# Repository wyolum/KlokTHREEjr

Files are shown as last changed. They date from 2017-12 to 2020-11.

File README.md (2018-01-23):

# KlokTHREEjr
RGB LED matrix for text and animation display.

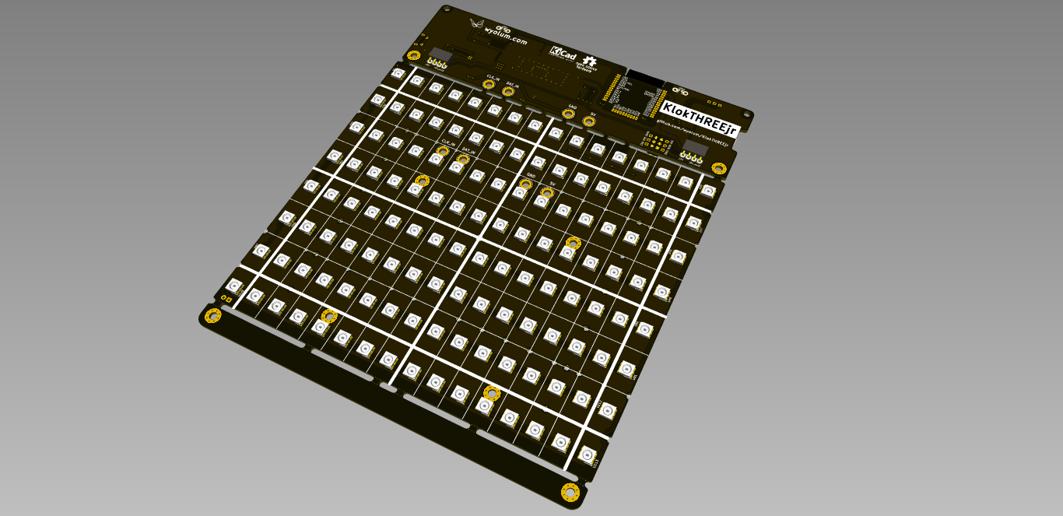
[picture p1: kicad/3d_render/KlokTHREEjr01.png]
KlokTHREEjr


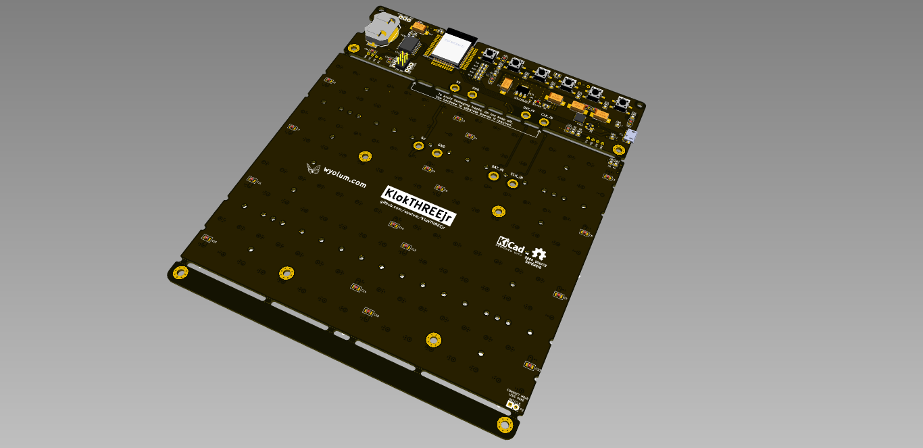
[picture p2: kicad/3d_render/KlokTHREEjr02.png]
KlokTHREEjr


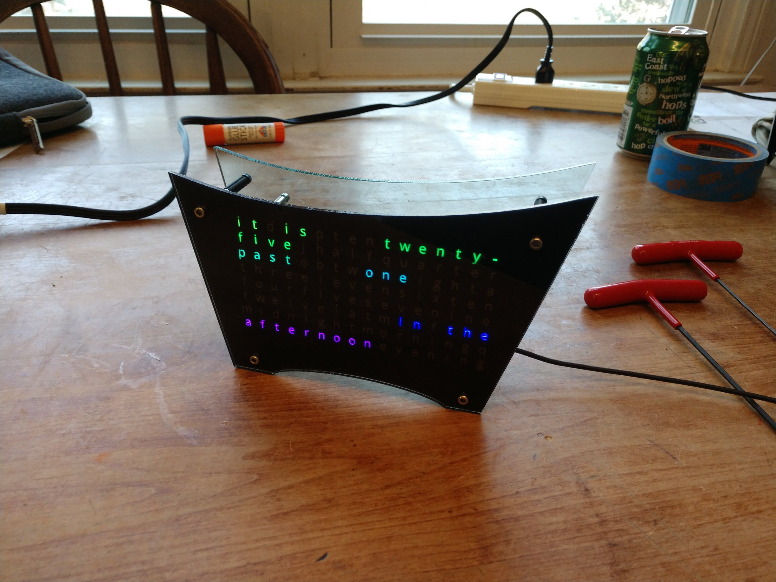
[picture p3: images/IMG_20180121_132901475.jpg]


License
-------
[CERN Open Hardware Licence v1.2 ]

[CERN Open Hardware Licence v1.2 ]:http://www.ohwr.org/attachments/2388/cern_ohl_v_1_2.txt

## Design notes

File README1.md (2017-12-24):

# Chromogram
RGB LED matrix for text and animation display.

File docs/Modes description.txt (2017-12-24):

Power-up
-
Display code version "1.0"
L | R held down <go to Self test>
- or -
wait 1 second then <go to Time mode>

_________________
Self test mode
_________________
Display "Test"
- cycle R, G, B pixels (mostly to check for bad pixels)

L | R - <go to Time mode>

_________________
Time mode
_________________
L - go to Seconds mode
R - Colour++
R held - go to Colour/Group select mode

L & R held - go to Time Set mode

_________________
Seconds mode
_________________
L - go to Temperature mode

_________________
Temperature mode
_________________
L - go to Time mode
L held - toggle between deg F and deg C

_________________
Colour/Group select mode
_________________
R - colour ++
R held - group ++
no button for 1 sec - go to Time mode

Display <Group><Colour/Speed>, e.g. "A0" for White, "A2" for Red, "B1" for solid colour fade w/ 500ms delay
(Remember last colour/speed shown when switching groups)

Group A - Solid colours
	0-White
	1-Pink
	2-Red
	3-Orange
	4-Yellow
	5-Green
	6-Blue
	7-Purple
	<repeat>

Group B - Solid colours
	0-White
	1-Hot pink
	2-Blood orange
	3-Lemon lime
	4-Neon green
	5-Teal
	6-Turquois
	7-Light purple
	<repeat>

Group C - Solid colour fade
	Speed 1 - delay 500
	Speed 2 - delay 200
	Speed 3 - delay 100
	Speed 4 - delay 50
	Speed 5 - delay 10
	<repeat>

Group D	- Rainbow colour fade
	Speed 1 - delay 500
	Speed 2 - delay 200
	Speed 3 - delay 100
	Speed 4 - delay 50
	Speed 5 - delay 10
	<repeat>

Group E - Randomly coloured letters
	Speed 0 - colours only change when words change
	Speed 1 - colours change once per minute
	Speed 2 - colours change every 15 seconds
	Speed 3 - colours change every 5 seconds
	Speed 4 - colours change every second
	Speed 5 - delay 100ms
	Speed 6 - delay 10ms
	<repeat>

Group F	- Simulated fire

<back to Group A>

_________________
Time set mode
_________________
L - enter
R - selection ++

Display "Set"
Display "Hour"
Display current hour from RTC
R - Hour ++ (0 - 23, repeating)
<hour is selected>
L - 
Display "Min"
Display current minute from RTC
R - Minute ++ (0-59, repeating)
L - 
Display "OK" for 1 second
<Return to Time mode>

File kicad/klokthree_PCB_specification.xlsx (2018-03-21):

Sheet: Template
PCB Name 名称 | KlokTHREEjr
Board Size 尺寸 | Length*width (Unit:inch) | 6.4 | * | 7.65
Material 板材 | (Rigid) FR－4 | Special Requirement:
Layers 层数 | 2 | Special Requirement:
Thickness 厚度 | 1.6 mm | Special Requirement:
Copper Weight 铜厚 | 1 oz. | Special Requirement:
Soldermask Color 阻焊颜色 | BLACK | Special Requirement:
Silkscreen Color 丝印颜色 | WHITE | Special Requirement:
Surface Finishing 焊盘喷镀 | HASL Lead Free | Special Requirement:
Via soldermask 阻焊覆盖 | Soldermask Cover | Special Requirement:
Mini trace/spacing 最小线宽 | 0.20 mm | Special Requirement:
Mini hole size 最小孔径 | 0.40 mm | Special Requirement:
Special requirements 特殊工艺
 | Other Special requirements：

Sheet: Parameter
PCB Material | Layers | Thickness | Copper Weight | Soldermask Color | Silkscreen Color | Surface Finishing | Via soldermask | Mini trace/spacing | Mini hole size
FR-4 | 1 Layer | 0.6mm | 0.5 oz | Green | White | HASL Lead Free(RoHS) | Soldermask Cover | 4 mil or 0.10 mm | 6 mil or 0.15 mm
Flexible Printed Circuit | 2 Layer | 0.8mm | 1 oz | Red | Black | ENIG | Soldermask Opening | 5 mil or0.13 mm | 8 mil or 0.2 mm
Rogers 4003 | 4 Layer | 1.0mm | 2 oz | Blue | Yellow | OSP |  | 6 mil or 0.15 mm | 10 mil or 0.25 mm
Rogers 4350 | 6 Layer | 1.2mm | 3 oz | Black | Red | Immersion Tin |  | 8 mil or 0.20 mm | 12 mil or 0.30 mm
Taconic Series | 8 Layer | 1.3mm | Other | White | Other | Immersion Sliver
Aluminum-based material | 10 Layer | 1.6mm |  | Green Matte |  | Hard Gold
RF-35 | 12 Layer | 2.0mm |  | Blue Matte |  | Other
Arlon | 14 Layer | 2.5mm |  | Black Matte
Other | 16 Layer | 3.0mm |  | Other
 | Other | Other

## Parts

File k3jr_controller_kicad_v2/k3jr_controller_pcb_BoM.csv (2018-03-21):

Id | Designator | Package | Quantity | Designation | Supplier and ref
1 | BT1 | CR2032_SMD2 | 1 | Batt_RTC
2 | LDR1,LDR2 | r_0805_ldr_2 | 2 | LDR
3 | S5 | SW_SMD | 1 | SW-DEC
4 | C17,C25,C23 | c_2917 | 3 | 10uF/25V
5 | D1 | SOT-143 | 1 | RClamp0854P.TCT
6 | P1 | USB_Micro-B_Molex-105017-0001 | 1 | USB_micro
7 | HB47,HB48 | MountingHole_3.2mm_M3_Pad_Via | 2 | mtg_hole_3mm
8 | S6 | SW_SMD | 1 | SW-MODE
9 | C27 | c_2917 | 1 | 100uF/6V3
10 | U132 | QFN-28-1EP_5x5mm_Pitch0.5mm | 1 | CP2102N-A01-GQFN28
11 | R25,R24,R11,R10,R3,R7,R6,R12,R13 | r_0805 | 9 | 10k
12 | C31,C22,C26,C24,C29,C30 | c_0805 | 6 | 100nF
13 | S4 | SW_SMD | 1 | SW-BOOT
14 | HB45,HB46 | MountingHole_3.2mm_M3 | 2 | mtg_hole_3mm_small
15 | G1,G7 | Logo-WL3 | 2 | LOGO_WL
16 | C18 | c_2917 | 1 | 22uF/25V
17 | R9,R8 | r_0805 | 2 | 4K7
18 | U131 | SOT-223-3_TabPin2 | 1 | 1117-33
19 | R23,R21 | r_0805 | 2 | 0R
20 | R22,R18,R16 | r_0805 | 3 | 470R
21 | R20,R19 | r_0805 | 2 | 0R NC
22 | R4 | r_0805 | 1 | 1k
23 | Q1 | SOT-363_SC-70-6 | 1 | DDC114TU
24 | C28 | c_0805 | 1 | 1uF/10V
25 | C21,C20,C19 | c_0805 | 3 | 1nF
26 | TP1 | BreakOutPad | 1 | ~RST
27 | S2 | SW_SMD | 1 | SW-INC
28 | U130 | DS3231 | 1 | DS3231N
29 | S3 | SW_SMD | 1 | SW-EN
30 | J8 | 1pin | 1 | GND
31 | J7 | 1pin | 1 | 5V
32 | J23 | BreakOutPad | 1 | GND
33 | J22 | BreakOutPad | 1 | RST
34 | J21 | BreakOutPad | 1 | MOSI
35 | J20 | Header_ISP | 1 | SPI
36 | J19 | BreakOutPad | 1 | SCK
37 | J18 | BreakOutPad | 1 | 3V3
38 | J17 | BreakOutPad | 1 | MISO
39 | TP3 | BreakOutPad | 1 | 32kHz
40 | TP2 | BreakOutPad | 1 | SQR
41 | J25 | Header_4x1 | 1 | I2C_ext2
42 | J24 | Header_4x1 | 1 | I2C_ext1
43 | G3,G9 | OSHW_6mm | 2 | OSHW
44 | G2,G8 | KiCad-Logo2_6mm_SilkScreen | 2 | KiCad
45 | J2 | 1pin | 1 | DAT_IN
46 | J1 | 1pin | 1 | CLK_IN
47 | JP1 | R_0402 | 1 | LED_PWR_EN
48 | U129 | esp_wroom_32 | 1 | ESP-wroom-32
49 | S1 | SW_SMD | 1 | SW-ENTER
50 | D2 | LED-0805 | 1 | LED_PWR
51 | L1,L2 | r_0805 | 2 | 330E

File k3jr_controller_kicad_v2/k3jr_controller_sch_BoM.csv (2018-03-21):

Reference Type | Quantity | Reference | Value | Footprint | Datasheet | manf# | Digikey | Field4 | Field5 | Field6 | Field7 | Field8 | Field9 | Field10 | Field11
BT | 1 | BT1, | Batt_RTC | k3jr_controller_libs:CR2032_SMD2 |  |  | BU2032SM-HD-GCT-ND
C | 3 | C19,C20,C21, | 1nF | k3jr_controller_libs:c_0805 |  | Value
C | 6 | C29,C31,C30,C22,C24,C26, | 100nF | k3jr_controller_libs:c_0805
C | 1 | C27, | 100uF/6V3 | k3jr_controller_libs:c_2917
C | 1 | C28, | 1uF/10V | k3jr_controller_libs:c_0805
C | 3 | C17,C23,C25, | 10uF/25V | k3jr_controller_libs:c_2917
C | 1 | C18, | 22uF/25V | k3jr_controller_libs:c_2917
D | 1 | D2, | LED_PWR | k3jr_controller_libs:LED-0805 |  |  |  | LED SS 5MM 625NM RED DIFF | 2V, 10mA | Round with Domed Top, 5mm, T-1 3/4 | Kingbright Corp | WP7113ID | Digikey | 754-1264-ND | http://www.digikey.com/product-detail/en/WP7113ID/754-1264-ND/1747663
D | 1 | D1, | RClamp0854P.TCT | k3jr_controller_libs:SOT-143
G | 2 | G2,G8, | KiCad | k3jr_controller_libs:KiCad-Logo2_6mm_SilkScreen |  | Value
G | 2 | G1,G7, | LOGO_WL | k3jr_controller_libs:Logo-WL3 |  | Value
G | 2 | G3,G9, | OSHW | k3jr_controller_libs:OSHW_6mm |  | Value
HB | 2 | HB47,HB48, | mtg_hole_3mm | k3jr_controller_libs:MountingHole_3.2mm_M3_Pad_Via |  | Value
HB | 2 | HB45,HB46, | mtg_hole_3mm_small | k3jr_controller_libs:MountingHole_3.2mm_M3 |  | Value
J | 1 | J1, | CLK_IN | k3jr_controller_libs:1pin
J | 1 | J2, | DAT_IN | k3jr_controller_libs:1pin
J | 2 | J23,J8, | GND | k3jr_controller_libs:BreakOutPad |  | mfr_pn
J | 1 | J24, | I2C_ext1 | k3jr_controller_libs:Header_4x1
J | 1 | J25, | I2C_ext2 | k3jr_controller_libs:Header_4x1
J | 1 | J17, | MISO | k3jr_controller_libs:BreakOutPad
J | 1 | J21, | MOSI | k3jr_controller_libs:BreakOutPad |  | mfr_pn
J | 1 | J22, | RST | k3jr_controller_libs:BreakOutPad |  | mfr_pn
J | 1 | J19, | SCK | k3jr_controller_libs:BreakOutPad |  | mfr_pn
J | 1 | J20, | SPI | k3jr_controller_libs:Header_ISP
J | 1 | J7, | 5V | k3jr_controller_libs:1pin
J | 1 | J18, | 3V3 | k3jr_controller_libs:BreakOutPad |  | mfr_pn
JP | 1 | JP1, | LED_PWR_EN | k3jr_controller_libs:R_0402
L | 2 | L1,L2, | 330E | k3jr_controller_libs:r_0805
LDR | 2 | LDR1,LDR2, | LDR | k3jr_controller_libs:r_0805_ldr_2
P | 1 | P1, | USB_micro | k3jr_controller_libs:USB_Micro-B_Molex-105017-0001
Q | 1 | Q1, | DDC114TU | k3jr_controller_libs:SOT-363_SC-70-6 | https://www.diodes.com/assets/Datasheets/ds30345.pdf
R | 2 | R8,R9, | 4K7 | k3jr_controller_libs:r_0805
R | 2 | R21,R23, | 0R | k3jr_controller_libs:r_0805 |  | Value
R | 3 | R22,R16,R18, | 470R | k3jr_controller_libs:r_0805 |  | Value
R | 2 | R20,R19, | 0R NC | k3jr_controller_libs:r_0805 |  | Value
R | 1 | R4, | 1k | k3jr_controller_libs:r_0805
R | 9 | R24,R25,R12,R13,R10,R11,R6,R7,R3, | 10k | k3jr_controller_libs:r_0805
S | 1 | S4, | SW-BOOT | k3jr_controller_libs:SW_SMD |  | Value
S | 1 | S5, | SW-DEC | k3jr_controller_libs:SW_SMD
S | 1 | S3, | SW-EN | k3jr_controller_libs:SW_SMD |  | Value
S | 1 | S1, | SW-ENTER | k3jr_controller_libs:SW_SMD
S | 1 | S2, | SW-INC | k3jr_controller_libs:SW_SMD
S | 1 | S6, | SW-MODE | k3jr_controller_libs:SW_SMD
TP | 1 | TP2, | SQR | k3jr_controller_libs:BreakOutPad
TP | 1 | TP3, | 32kHz | k3jr_controller_libs:BreakOutPad
TP | 1 | TP1, | ~RST | k3jr_controller_libs:BreakOutPad
U | 1 | U131, | 1117-33 | k3jr_controller_libs:SOT-223-3_TabPin2 | http://www.diodes.com/datasheets/AP1117.pdf | mfr_pn
U | 1 | U132, | CP2102N-A01-GQFN28 | k3jr_controller_libs:QFN-28-1EP_5x5mm_Pitch0.5mm | http://www.silabs.com/support%20documents/technicaldocs/cp2102n-datasheet.pdf | Value
U | 1 | U130, | DS3231N | k3jr_controller_libs:DS3231
U | 1 | U129, | ESP-wroom-32 | k3jr_controller_libs:esp_wroom_32 |  | mfr_pn

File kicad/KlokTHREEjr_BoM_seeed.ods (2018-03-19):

Electronic Engineering BOM List
Product Name： KlokTHREEjr
Version：V1
Issue Date：18/MAR/2018
Item No. (序号) | Reference Des (上件位置) | Qty (用量) | Catalog (分类） | Part_Description (规格描述) | Part_Value （元件值） | Part_Package （元件封装） | Manufacturers Name (使用厂牌名称) | Manufacturers Part No. (使用厂牌型号) | Distributors Name （供应商名称） | Distributors Part No. (供貨商型号) | Unit Price （单价） | Price Break To Use （价格分段的购买量） | Notes/Remark （备注）
Example（填写范例）
1 | BT1 | 1 | OTHER | HOLDER COIN CELL 20MM SMD | Batt_RTC | CR2032_SMD | MPD (Memory Protection Devices) | BK-912 | Digikey | BK-912-ND |  |  | https://www.digikey.com/product-detail/en/mpd-memory-protection-devices/BK-912/BK-912-ND/2647825
2 | BATT1 | 1 | OTHER | BATTERY LITHIUM 3V COIN 20MM | Battery Coin 2032 | CR2032 | Panasonic – BSG | CR2032 | Digikey | P189-ND |  |  | https://www.digikey.com/product-detail/en/panasonic-bsg/CR2032/P189-ND/31939
3 | C31,C22,C26,C24,C29,C30,C9,C6,C1,C2,C3,C4,C5,C7,C8,C10,C11,C12,C13,C14,C15,C16 | 22 | Capacitor | CAP CER 0.1UF 50V X7R 0805 | 100nF | c_0805 | KEMET | C0805C104M5RACTU | Digikey | 399-1169-1-ND |  |  | https://www.digikey.com/product-detail/en/kemet/C0805C104M5RACTU/399-1169-1-ND/411444
4 | C17,C23,C25 | 3 | Capacitor | CAP ALUM POLY 10UF 20% 25V SMD | 10uF/25V | c_2917 | Panasonic Electronic Components | EEF-CS1E100R | Digikey | P16804-1-ND |  |  | https://www.digikey.com/product-detail/en/panasonic-electronic-components/EEF-CS1E100R/P16804-1-ND/4755574
5 | C18 | 1 | Capacitor | CAP ALUM POLY 22UF 20% 25V SMD | 22uF/25V | c_2917 | Panasonic Electronic Components | EEF-CX1E220R | Digikey | P16818-1-ND |  |  | https://www.digikey.com/product-detail/en/panasonic-electronic-components/EEF-CX1E220R/P16818-1-ND/4755588
6 | C19,C20,C21 | 3 | Capacitor | CAP CER 1000PF 50V X7R 0603 | 1nF | c_0805 | AVX Corporation | 06035C102KAT2A | Digikey | 478-1215-1-ND |  |  | https://www.digikey.com/product-detail/en/avx-corporation/06035C102KAT2A/478-1215-1-ND/564247
7 | C27 | 1 | Capacitor | CAP ALUM POLY 100UF 20% 6.3V SMD | 100uF/6V3 | c_2917 | Panasonic Electronic Components | EEF-CX0J101R | Digikey | PCE4278CT-ND |  |  | https://www.digikey.com/product-detail/en/panasonic-electronic-components/EEF-CX0J101R/PCE4278CT-ND/816448
8 | C28 | 1 | Capacitor | CAP CER 1UF 25V X7R 0805 | 1uF/25V | c_0805 | Samsung Electro-Mechanics | CL21B105KAFNNNG | Digikey | 1276-6469-1-ND |  |  | https://www.digikey.com/product-detail/en/samsung-electro-mechanics/CL21B105KAFNNNG/1276-6469-1-ND/5958097
9 | D1 | 1 | Diode | TVS DIODE 5.5V 30V SLP1616P6 | RClamp0854P.TCT | SOT-143 | Semtech Corporation | RCLAMP0854P.TCT | Digikey | RCLAMP0854P.TCTCT-ND |  |  | https://www.digikey.com/product-detail/en/semtech-corporation/RCLAMP0854P.TCT/RCLAMP0854P.TCTCT-ND/5113720
10 | D2 | 1 | Diode | LED GREEN CLEAR 0805 SMD | LED_PWR | LED-0805 | Wurth Electronics Inc. | 150080GS75000 | Digikey | 732-4983-1-ND |  |  | https://www.digikey.com/product-detail/en/wurth-electronics-inc/150080GS75000/732-4983-1-ND/4489913
11 | L1,L2 | 2 | PROTECTOR CATEGORY | FERRITE BEAD 330 OHM 0805 1LN | 330E | r_0805 | TDK Corporation | MPZ2012S331AT000 | Digikey | 445-1569-1-ND |  |  | https://www.digikey.com/product-detail/en/tdk-corporation/MPZ2012S331AT000/445-1569-1-ND/571899
12 | P1 | 1 | Connector | CONN RCPT MICRO USB R/A SMD | USB_micro | USB_Micro-B_Molex-105017-0001 | Molex, LLC | 1050170001 | Digikey | WM1399CT-ND |  |  | https://www.digikey.com/product-detail/en/molex-llc/1050170001/WM1399CT-ND/2350885
13 | Q1 | 1 | Transistor | TRANS 2NPN PREBIAS 0.2W SOT363 | DDC114TU | SOT-363_SC-70-6 | Diodes Incorporated | DDC114TU-7-F | Digikey | DDC114TU-FDICT-ND |  |  | https://www.digikey.com/product-detail/en/diodes-incorporated/DDC114TU-7-F/DDC114TU-FDICT-ND/815483
14 | R1,R2,R16,R18,R22 | 5 | Resister | RES SMD 470 OHM 5% 1/8W 0805 | 470R | r_0805 | Stackpole Electronics Inc. | RMCF0805JT470R | Digikey | RMCF0805JT470RCT-ND |  |  | https://www.digikey.com/product-detail/en/stackpole-electronics-inc/RMCF0805JT470R/RMCF0805JT470RCT-ND/1942551
15 | R25,R24,R11,R10,R3,R7,R6,R12,R13 | 9 | Resister | RES SMD 10K OHM 1% 1/8W 0805 | 10k | r_0805 | Stackpole Electronics Inc. | RMCF0805FT10K0 | Digikey | RMCF0805FT10K0CT-ND |  |  | https://www.digikey.com/product-detail/en/stackpole-electronics-inc/RMCF0805FT10K0/RMCF0805FT10K0CT-ND/1942435
16 | R4 | 1 | Resister | RES SMD 1K OHM 1% 1/8W 0805 | 1k | r_0805 | Stackpole Electronics Inc. | RMCF0805FT1K00 | Digikey | RMCF0805FT1K00CT-ND |  |  | https://www.digikey.com/product-detail/en/stackpole-electronics-inc/RMCF0805FT1K00/RMCF0805FT1K00CT-ND/1942370
17 | R8,R9 | 2 | Resister | RES SMD 4.7K OHM 1% 1/8W 0805 | 4K7 | r_0805 | Stackpole Electronics Inc. | RMCF0805FT4K70 | Digikey | RMCF0805FT4K70CT-ND |  |  | https://www.digikey.com/product-detail/en/stackpole-electronics-inc/RMCF0805FT4K70/RMCF0805FT4K70CT-ND/1942412
18 | R21,R23 | 2 | Resister | RES SMD 0 OHM JUMPER 1/8W 0805 | 0R | r_0805 | Stackpole Electronics Inc. | RMCF0805ZT0R00 | Digikey | RMCF0805ZT0R00CT-ND |  |  | https://www.digikey.com/product-detail/en/stackpole-electronics-inc/RMCF0805ZT0R00/RMCF0805ZT0R00CT-ND/1942606
19 | S1 | 1 | OTHER | SWITCH TACTILE SPST-NO 0.05A 24V | SW-ENTER | SW_SMD | TE Connectivity ALCOSWITCH Switches | FSM6JSMA | Digikey | 450-1133-ND |  |  | https://www.digikey.com/product-detail/en/te-connectivity-alcoswitch-switches/FSM6JSMA/450-1133-ND/525822
20 | S2 | 1 | OTHER | SWITCH TACTILE SPST-NO 0.05A 24V | SW-INC | SW_SMD | TE Connectivity ALCOSWITCH Switches | FSM6JSMA | Digikey | 450-1133-ND |  |  | https://www.digikey.com/product-detail/en/te-connectivity-alcoswitch-switches/FSM6JSMA/450-1133-ND/525822
21 | S3 | 1 | OTHER | SWITCH TACTILE SPST-NO 0.05A 24V | EN | SW_SMD | TE Connectivity ALCOSWITCH Switches | FSM6JSMA | Digikey | 450-1133-ND |  |  | https://www.digikey.com/product-detail/en/te-connectivity-alcoswitch-switches/FSM6JSMA/450-1133-ND/525822
22 | S4 | 1 | OTHER | SWITCH TACTILE SPST-NO 0.05A 24V | BOOT | SW_SMD | TE Connectivity ALCOSWITCH Switches | FSM6JSMA | Digikey | 450-1133-ND |  |  | https://www.digikey.com/product-detail/en/te-connectivity-alcoswitch-switches/FSM6JSMA/450-1133-ND/525822
23 | S5 | 1 | OTHER | SWITCH TACTILE SPST-NO 0.05A 24V | SW-DEC | SW_SMD | TE Connectivity ALCOSWITCH Switches | FSM6JSMA | Digikey | 450-1133-ND |  |  | https://www.digikey.com/product-detail/en/te-connectivity-alcoswitch-switches/FSM6JSMA/450-1133-ND/525822
24 | S6 | 1 | OTHER | SWITCH TACTILE SPST-NO 0.05A 24V | SW-MODE | SW_SMD | TE Connectivity ALCOSWITCH Switches | FSM6JSMA | Digikey | 450-1133-ND |  |  | https://www.digikey.com/product-detail/en/te-connectivity-alcoswitch-switches/FSM6JSMA/450-1133-ND/525822
25 | U129 | 1 | IC | SMD MODULE, ESP32-D0WDQ6, 32MBIT | ESP-wroom-32 | esp_wroom_32 | Espressif Systems | ESP-WROOM-32 | Digikey | 1904-1010-1-ND |  |  | https://www.digikey.com/product-detail/en/espressif-systems/ESP-WROOM-32/1904-1010-1-ND/8544305
26 | U130 | 1 | IC | IC RTC CLK/CALENDAR I2C 16-SOIC | DS3231N | DS3231 | Maxim Integrated | DS3231M+ | Digikey | DS3231M+-ND |  |  | https://www.digikey.com/product-detail/en/maxim-integrated/DS3231M/DS3231M-ND/2402420
27 | U131 | 1 | IC | IC REG LIN 3.3V 800MA SOT223-4 | AP1117-33 | SOT-223-3_TabPin2 | Texas Instruments | TLV1117-33CDCYR | Digikey | 296-21112-1-ND |  |  | https://www.digikey.com/product-detail/en/texas-instruments/TLV1117-33CDCYR/296-21112-1-ND/1217055
28 | U132 | 1 | IC | IC BRIDGE USB TO UART 28QFN | CP2102N-A01-GQFN28 | QFN-28-1EP_5x5mm_Pitch0.5mm | Silicon Labs | CP2102N-A01-GQFN28 | Digikey | 336-3694-ND |  |  | https://www.digikey.com/product-detail/en/silicon-labs/CP2102N-A01-GQFN28/336-3694-ND/6012519
PARTS KIT (DO NOT POPULATE)
29 | LDR1,LDR2 | 2 | Resister | PHOTOCELL 16-33KOHM | LDR | r_0805_ldr | Luna Optoelectronics | PDV-P8103 | Digikey | PDV-P8103-ND |  |  | https://www.digikey.com/product-detail/en/luna-optoelectronics/PDV-P8103/PDV-P8103-ND/480610
DO NOT POPULATE
30 | U1,U2,U3,U4,U5,U6,U7,U8,U9,U10,U11,U12,U13,U14,U15,U16, U17,U18,U19,U20,U21,U22,U23,U24,U25,U26,U27,U28,U29,U30,U31,U32, U33,U34,U35,U36,U37,U38,U39,U40,U41,U42,U43,U44,U45,U46,U47,U48, U49,U50,U51,U52,U53,U54,U55,U56,U57,U58,U59,U60,U61,U62,U63,U64, U65,U66,U67,U68,U69,U70,U71,U72,U73,U74,U75,U76,U77,U78,U79,U80, U81,U82,U83,U84,U85,U86,U87,U88,U89,U90,U91,U92,U93,U94,U95,U96, U97,U98,U99,U100,U101,U102,U103,U104,U105,U106,U107,U108,U109,U110,U111,U112, U113,U114,U115,U116,U117,U118,U119,U120,U121,U122,U123,U124,U125,U126,U127,U128 | 128 | IC | 5050 SMD RGB LED with built-in controller | APA102 | 5050 | Shiji Lighting | APA102C |  | Aliexpress
1. Recommended Distributor: Digi-Key, Mouser, Avnet Express, Farnell.
2. Catalog: Capacitor,Resister,Diode,Connector,Transistor,IC,PROTECTOR CATEGORY,OTHER
3. Required Fields: Item No, Reference Des, Qty, Catalog, Part_Value, Part Package
Optional Fields: Part_Description, Manufacturers Name, Manufacturers Part No, Distributors Name, Distributors Part No, Unit Cost, Price break to use, Notes/Remark

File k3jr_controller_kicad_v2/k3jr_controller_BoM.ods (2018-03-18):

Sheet: klokTHREEjr_pcb_BoM
No | Designator | Package | Quantity | Designation | Digi PN | Mfr. | Mfg PN | Decription | Link
1 | BT1 | CR2032_SMD | 1 | Batt_RTC | BK-912-ND | MPD (Memory Protection Devices) | BK-912 | HOLDER COIN CELL 20MM SMD | https://www.digikey.com/product-detail/en/mpd-memory-protection-devices/BK-912/BK-912-ND/2647825
2 | BATT1 | CR2032 | 1 | Battery Coin 2032 | P189-ND | Panasonic – BSG | CR2032 | BATTERY LITHIUM 3V COIN 20MM | https://www.digikey.com/product-detail/en/panasonic-bsg/CR2032/P189-ND/31939
3 | C31,C22,C26,C24,C29,C30,C9,C6,C1,C2,C3,C4,C5,C7,C8,C10,C11,C12,C13,C14,C15,C16 | c_0805 | 22 | 100nF | 399-1169-1-ND | KEMET | C0805C104M5RACTU | CAP CER 0.1UF 50V X7R 0805 | https://www.digikey.com/product-detail/en/kemet/C0805C104M5RACTU/399-1169-1-ND/411444
4 | C17,C23,C25 | c_2917 | 3 | 10uF/25V | P16804-1-ND | Panasonic Electronic Components | EEF-CS1E100R | CAP ALUM POLY 10UF 20% 25V SMD | https://www.digikey.com/product-detail/en/panasonic-electronic-components/EEF-CS1E100R/P16804-1-ND/4755574
5 | C18 | c_2917 | 1 | 22uF/25V | P16818-1-ND | Panasonic Electronic Components | EEF-CX1E220R | CAP ALUM POLY 22UF 20% 25V SMD | https://www.digikey.com/product-detail/en/panasonic-electronic-components/EEF-CX1E220R/P16818-1-ND/4755588
6 | C19,C20,C21 | c_0805 | 3 | 1nF | 478-1215-1-ND | AVX Corporation | 06035C102KAT2A | CAP CER 1000PF 50V X7R 0603 | https://www.digikey.com/product-detail/en/avx-corporation/06035C102KAT2A/478-1215-1-ND/564247
7 | C27 | c_2917 | 1 | 100uF/6V3 | PCE4278CT-ND | Panasonic Electronic Components | EEF-CX0J101R | CAP ALUM POLY 100UF 20% 6.3V SMD | https://www.digikey.com/product-detail/en/panasonic-electronic-components/EEF-CX0J101R/PCE4278CT-ND/816448
8 | C28 | c_0805 | 1 | 1uF/25V | 1276-6469-1-ND | Samsung Electro-Mechanics | CL21B105KAFNNNG | CAP CER 1UF 25V X7R 0805 | https://www.digikey.com/product-detail/en/samsung-electro-mechanics/CL21B105KAFNNNG/1276-6469-1-ND/5958097
9 | D1 | SOT-143 | 1 | RClamp0854P.TCT | RCLAMP0854P.TCTCT-ND | Semtech Corporation | RCLAMP0854P.TCT | TVS DIODE 5.5V 30V SLP1616P6 | https://www.digikey.com/product-detail/en/semtech-corporation/RCLAMP0854P.TCT/RCLAMP0854P.TCTCT-ND/5113720
10 | D2 | LED-0805 | 1 | LED_PWR | 732-4983-1-ND | Wurth Electronics Inc. | 150080GS75000 | LED GREEN CLEAR 0805 SMD | https://www.digikey.com/product-detail/en/wurth-electronics-inc/150080GS75000/732-4983-1-ND/4489913
11 | L1,L2 | r_0805 | 2 | 330E | 445-1569-1-ND | TDK Corporation | MPZ2012S331AT000 | FERRITE BEAD 330 OHM 0805 1LN | https://www.digikey.com/product-detail/en/tdk-corporation/MPZ2012S331AT000/445-1569-1-ND/571899
12 | LDR1,LDR2 | r_0805_ldr | 2 | LDR | PDV-P8103-ND | Luna Optoelectronics | PDV-P8103 | PHOTOCELL 16-33KOHM | https://www.digikey.com/product-detail/en/luna-optoelectronics/PDV-P8103/PDV-P8103-ND/480610
13 | P1 | USB_Micro-B_Molex-105017-0001 | 1 | USB_micro | WM1399CT-ND | Molex, LLC | 1050170001 | CONN RCPT MICRO USB R/A SMD | https://www.digikey.com/product-detail/en/molex-llc/1050170001/WM1399CT-ND/2350885
14 | Q1 | SOT-363_SC-70-6 | 1 | DDC114TU | DDC114TU-FDICT-ND | Diodes Incorporated | DDC114TU-7-F | TRANS 2NPN PREBIAS 0.2W SOT363 | https://www.digikey.com/product-detail/en/diodes-incorporated/DDC114TU-7-F/DDC114TU-FDICT-ND/815483
15 | R1,R2,R16,R18,R22 | r_0805 | 5 | 470R | RMCF0805JT470RCT-ND | Stackpole Electronics Inc. | RMCF0805JT470R | RES SMD 470 OHM 5% 1/8W 0805 | https://www.digikey.com/product-detail/en/stackpole-electronics-inc/RMCF0805JT470R/RMCF0805JT470RCT-ND/1942551
16 | R25,R24,R11,R10,R3,R7,R6,R12,R13 | r_0805 | 9 | 10k | RMCF0805FT10K0CT-ND | Stackpole Electronics Inc. | RMCF0805FT10K0 | RES SMD 10K OHM 1% 1/8W 0805 | https://www.digikey.com/product-detail/en/stackpole-electronics-inc/RMCF0805FT10K0/RMCF0805FT10K0CT-ND/1942435
17 | R4 | r_0805 | 1 | 1k | RMCF0805FT1K00CT-ND | Stackpole Electronics Inc. | RMCF0805FT1K00 | RES SMD 1K OHM 1% 1/8W 0805 | https://www.digikey.com/product-detail/en/stackpole-electronics-inc/RMCF0805FT1K00/RMCF0805FT1K00CT-ND/1942370
18 | R8,R9 | r_0805 | 2 | 4K7 | RMCF0805FT4K70CT-ND | Stackpole Electronics Inc. | RMCF0805FT4K70 | RES SMD 4.7K OHM 1% 1/8W 0805 | https://www.digikey.com/product-detail/en/stackpole-electronics-inc/RMCF0805FT4K70/RMCF0805FT4K70CT-ND/1942412
19 | R21,R23 | r_0805 | 2 | 0R | RMCF0805ZT0R00CT-ND | Stackpole Electronics Inc. | RMCF0805ZT0R00 | RES SMD 0 OHM JUMPER 1/8W 0805 | https://www.digikey.com/product-detail/en/stackpole-electronics-inc/RMCF0805ZT0R00/RMCF0805ZT0R00CT-ND/1942606
20 | S1 | SW_SMD | 1 | SW-ENTER | 450-1133-ND | TE Connectivity ALCOSWITCH Switches | FSM6JSMA | SWITCH TACTILE SPST-NO 0.05A 24V | https://www.digikey.com/product-detail/en/te-connectivity-alcoswitch-switches/FSM6JSMA/450-1133-ND/525822
21 | S2 | SW_SMD | 1 | SW-INC | 450-1133-ND | TE Connectivity ALCOSWITCH Switches | FSM6JSMA | SWITCH TACTILE SPST-NO 0.05A 24V | https://www.digikey.com/product-detail/en/te-connectivity-alcoswitch-switches/FSM6JSMA/450-1133-ND/525822
22 | S3 | SW_SMD | 1 | EN | 450-1133-ND | TE Connectivity ALCOSWITCH Switches | FSM6JSMA | SWITCH TACTILE SPST-NO 0.05A 24V | https://www.digikey.com/product-detail/en/te-connectivity-alcoswitch-switches/FSM6JSMA/450-1133-ND/525822
23 | S4 | SW_SMD | 1 | BOOT | 450-1133-ND | TE Connectivity ALCOSWITCH Switches | FSM6JSMA | SWITCH TACTILE SPST-NO 0.05A 24V | https://www.digikey.com/product-detail/en/te-connectivity-alcoswitch-switches/FSM6JSMA/450-1133-ND/525822
24 | S5 | SW_SMD | 1 | SW-DEC | 450-1133-ND | TE Connectivity ALCOSWITCH Switches | FSM6JSMA | SWITCH TACTILE SPST-NO 0.05A 24V | https://www.digikey.com/product-detail/en/te-connectivity-alcoswitch-switches/FSM6JSMA/450-1133-ND/525822
25 | S6 | SW_SMD | 1 | SW-MODE | 450-1133-ND | TE Connectivity ALCOSWITCH Switches | FSM6JSMA | SWITCH TACTILE SPST-NO 0.05A 24V | https://www.digikey.com/product-detail/en/te-connectivity-alcoswitch-switches/FSM6JSMA/450-1133-ND/525822
26 | U1,U2,U3,U4,U5,U6,U7,U8,U9,U10,U11,U12,U13,U14,U15,U16, U17,U18,U19,U20,U21,U22,U23,U24,U25,U26,U27,U28,U29,U30,U31,U32, U33,U34,U35,U36,U37,U38,U39,U40,U41,U42,U43,U44,U45,U46,U47,U48, U49,U50,U51,U52,U53,U54,U55,U56,U57,U58,U59,U60,U61,U62,U63,U64, U65,U66,U67,U68,U69,U70,U71,U72,U73,U74,U75,U76,U77,U78,U79,U80, U81,U82,U83,U84,U85,U86,U87,U88,U89,U90,U91,U92,U93,U94,U95,U96, U97,U98,U99,U100,U101,U102,U103,U104,U105,U106,U107,U108,U109,U110,U111,U112, U113,U114,U115,U116,U117,U118,U119,U120,U121,U122,U123,U124,U125,U126,U127,U128 | 5050 | 128 | APA102 | Aliexpress | Shiji Lighting | APA102C | 5050 SMD RGB LED with built-in controller
27 | U129 | esp_wroom_32 | 1 | ESP-wroom-32 | 1904-1010-1-ND | Espressif Systems | ESP-WROOM-32 | SMD MODULE, ESP32-D0WDQ6, 32MBIT | https://www.digikey.com/product-detail/en/espressif-systems/ESP-WROOM-32/1904-1010-1-ND/8544305
28 | U130 | DS3231 | 1 | DS3231N | DS3231M+-ND | Maxim Integrated | DS3231M+ | IC RTC CLK/CALENDAR I2C 16-SOIC | https://www.digikey.com/product-detail/en/maxim-integrated/DS3231M/DS3231M-ND/2402420
29 | U131 | SOT-223-3_TabPin2 | 1 | AP1117-33 | 296-21112-1-ND | Texas Instruments | TLV1117-33CDCYR | IC REG LIN 3.3V 800MA SOT223-4 | https://www.digikey.com/product-detail/en/texas-instruments/TLV1117-33CDCYR/296-21112-1-ND/1217055
30 | U132 | QFN-28-1EP_5x5mm_Pitch0.5mm | 1 | CP2102N-A01-GQFN28 | 336-3694-ND | Silicon Labs | CP2102N-A01-GQFN28 | IC BRIDGE USB TO UART 28QFN | https://www.digikey.com/product-detail/en/silicon-labs/CP2102N-A01-GQFN28/336-3694-ND/6012519
 | DNP
 | R19,R20 | r_0805 | 2 | 0R NC
 | J20 | Header_3x2 | 1 | Header_ISP
 | J24 | Header_4x1 | 1 | I2C_ext1
 | J25 | Header_4x1 | 1 | I2C_ext2
 | JP1 | R_0402 | 1 | LED_PWR_EN
 | P2 | Pin_Header_Straight_1x02 | 1 | OUT_CLK_DAT

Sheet: BoM_PCB
Id | Designator | Package | Quantity | Designation | Supplier and ref
1 | BT1 | CR2032_SMD2 | 1 | Batt_RTC
2 | C17,C25,C23 | c_2917 | 3 | 10uF/25V
3 | C18 | c_2917 | 1 | 22uF/25V
4 | C21,C20,C19 | c_0805 | 3 | 1nF
5 | C27 | c_2917 | 1 | 100uF/6V3
6 | C28 | c_0805 | 1 | 1uF/10V
7 | C31,C22,C26,C24,C29,C30,C9,C6,C1,C2,C3,C4,C5,C7,C8,C10,C11,C12,C13,C14,C15,C16 | c_0805 | 22 | 100nF
8 | D1 | SOT-143 | 1 | RClamp0854P.TCT
9 | D2 | LED-0805 | 1 | LED_PWR
10 | L1,L2 | r_0805 | 2 | 330E
11 | LDR1,LDR2 | r_0805_ldr_2 | 2 | LDR
12 | P1 | USB_Micro-B_Molex-105017-0001 | 1 | USB_micro
13 | Q1 | SOT-363_SC-70-6 | 1 | DDC114TU
14 | R4 | r_0805 | 1 | 1k
15 | R9,R8 | r_0805 | 2 | 4K7
16 | R20,R19 | r_0805 | 2 | 0R NC
17 | R22,R18,R16,R1,R2 | r_0805 | 5 | 470R
18 | R23,R21 | r_0805 | 2 | 0R
19 | R25,R24,R11,R10,R3,R7,R6,R12,R13 | r_0805 | 9 | 10k
20 | S1 | SW_SMD | 1 | SW-ENTER
 | S2 | SW_SMD | 1 | SW-INC
 | S3 | SW_SMD | 1 | SW-EN
 | S4 | SW_SMD | 1 | SW-BOOT
 | S5 | SW_SMD | 1 | SW-DEC
 | S6 | SW_SMD | 1 | SW-MODE
21 | U127,U18,U1,U3,U4,U5,U6,U7,U8,U9,U10,U11,U12,U13,U14,U15,U16,U17,U19,U20,U21,U22,U23,U24,U25,U26,U27,U28,U29,U30,U31,U32,U33,U34,U35,U36,U37,U38,U39,U40,U41,U42,U43,U44,U45,U46,U47,U48,U49,U50,U51,U52,U53,U54,U55,U56,U57,U58,U59,U60,U61,U62,U63,U64,U65,U66,U67,U68,U69,U70,U71,U72,U73,U74,U75,U76,U77,U78,U79,U80,U81,U82,U83,U84,U85,U86,U87,U88,U89,U90,U91,U92,U93,U94,U95,U96,U97,U98,U99,U100,U101,U102,U103,U104,U105,U106,U107,U108,U109,U110,U111,U112,U113,U114,U115,U116,U117,U118,U119,U120,U121,U122,U123,U124,U125,U126,U128,U2 | APA102 | 128 | APA102
22 | U129 | esp_wroom_32 | 1 | ESP-wroom-32
23 | U130 | DS3231 | 1 | DS3231N
24 | U131 | SOT-223-3_TabPin2 | 1 | 1117-33
25 | U132 | QFN-28-1EP_5x5mm_Pitch0.5mm | 1 | CP2102N-A01-GQFN28
26 | BITE1,BITE2,BITE3,BITE4,BITE5,BITE6,BITE7,BITE8 | mouse-bite-2.54mm-slot_OSH | 8 | Mouse_Bite
27 | G1,G7 | Logo-WL3 | 2 | LOGO_WL
28 | G2,G8 | KiCad-Logo2_6mm_SilkScreen | 2 | KiCad
29 | G3,G9 | OSHW_6mm | 2 | OSHW
30 | HB44,HB43,HB42,HB41,HB40,HB39,HB38,HB37,HB36,HB35,HB34,HB33,HB32,HB31,HB30,HB29,HB28,HB27,HB26,HB25,HB24,HB23,HB22,HB21,HB20,HB19,HB18,HB17,HB16,HB15,HB14,HB13,HB12,HB11,HB10,HB9,HB8,HB7,HB6,HB5,HB4,HB3,HB2,HB1 | hole_baffle_2mm | 44 | hole_baffle
31 | HB45,HB46 | MountingHole_3.2mm_M3 | 2 | mtg_hole_3mm_small
32 | HB47,HB48,HB49,HB50,HB51,HB52,HB53,HB54 | MountingHole_3.2mm_M3_Pad_Via | 8 | mtg_hole_3mm
33 | J1,J9 | 1pin | 2 | CLK_IN
34 | J2,J10 | 1pin | 2 | DAT_IN
35 | J7,J15 | 1pin | 2 | 5V
36 | J8,J16 | 1pin | 2 | GND
37 | J17 | BreakOutPad | 1 | MISO
38 | J18 | BreakOutPad | 1 | 3V3
39 | J19 | BreakOutPad | 1 | SCK
40 | J20 | Header_ISP | 1 | SPI
41 | J21 | BreakOutPad | 1 | MOSI
42 | J22 | BreakOutPad | 1 | RST
43 | J23 | BreakOutPad | 1 | GND
44 | J24 | Header_4x1 | 1 | I2C_ext1
45 | J25 | Header_4x1 | 1 | I2C_ext2
46 | JP1 | R_0402 | 1 | LED_PWR_EN
47 | P2 | Pin_Header_Straight_1x02 | 1 | OUT_CLK_DAT
48 | TP1 | BreakOutPad | 1 | ~RST
49 | TP2 | BreakOutPad | 1 | SQR
50 | TP3 | BreakOutPad | 1 | 32kHz

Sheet: BoM_SCH
 | Reference | Value | Footprint
1 | R21 | 0R | KlokTHREEjr_libs:r_0805
 | R23 | 0R | KlokTHREEjr_libs:r_0805
2 | R20 | 0R NC | KlokTHREEjr_libs:r_0805
 | R19 | 0R NC | KlokTHREEjr_libs:r_0805
3 | R4 | 1k | KlokTHREEjr_libs:r_0805
4 | C19 | 1nF | KlokTHREEjr_libs:c_0805
 | C20 | 1nF | KlokTHREEjr_libs:c_0805
 | C21 | 1nF | KlokTHREEjr_libs:c_0805
5 | C28 | 1uF/10V | KlokTHREEjr_libs:c_0805
6 | R8 | 4K7 | KlokTHREEjr_libs:r_0805
 | R9 | 4K7 | KlokTHREEjr_libs:r_0805
7 | R24 | 10k | KlokTHREEjr_libs:r_0805
 | R25 | 10k | KlokTHREEjr_libs:r_0805
 | R12 | 10k | KlokTHREEjr_libs:r_0805
 | R13 | 10k | KlokTHREEjr_libs:r_0805
 | R10 | 10k | KlokTHREEjr_libs:r_0805
 | R11 | 10k | KlokTHREEjr_libs:r_0805
 | R6 | 10k | KlokTHREEjr_libs:r_0805
 | R7 | 10k | KlokTHREEjr_libs:r_0805
 | R3 | 10k | KlokTHREEjr_libs:r_0805
8 | C17 | 10uF/25V | KlokTHREEjr_libs:c_2917
 | C23 | 10uF/25V | KlokTHREEjr_libs:c_2917
 | C25 | 10uF/25V | KlokTHREEjr_libs:c_2917
9 | C18 | 22uF/25V | KlokTHREEjr_libs:c_2917
10 | C29 | 100nF | KlokTHREEjr_libs:c_0805
 | C31 | 100nF | KlokTHREEjr_libs:c_0805
 | C30 | 100nF | KlokTHREEjr_libs:c_0805
 | C1 | 100nF | KlokTHREEjr_libs:c_0805
 | C2 | 100nF | KlokTHREEjr_libs:c_0805
 | C3 | 100nF | KlokTHREEjr_libs:c_0805
 | C4 | 100nF | KlokTHREEjr_libs:c_0805
 | C5 | 100nF | KlokTHREEjr_libs:c_0805
 | C6 | 100nF | KlokTHREEjr_libs:c_0805
 | C7 | 100nF | KlokTHREEjr_libs:c_0805
 | C8 | 100nF | KlokTHREEjr_libs:c_0805
 | C9 | 100nF | KlokTHREEjr_libs:c_0805
 | C10 | 100nF | KlokTHREEjr_libs:c_0805
 | C11 | 100nF | KlokTHREEjr_libs:c_0805
 | C12 | 100nF | KlokTHREEjr_libs:c_0805
 | C14 | 100nF | KlokTHREEjr_libs:c_0805
 | C13 | 100nF | KlokTHREEjr_libs:c_0805
 | C15 | 100nF | KlokTHREEjr_libs:c_0805
 | C16 | 100nF | KlokTHREEjr_libs:c_0805
 | C22 | 100nF | KlokTHREEjr_libs:c_0805
 | C24 | 100nF | KlokTHREEjr_libs:c_0805
 | C26 | 100nF | KlokTHREEjr_libs:c_0805
11 | C27 | 100uF/6V3 | KlokTHREEjr_libs:c_2917
12 | L1 | 330E | KlokTHREEjr_libs:r_0805
 | L1 | 330E | KlokTHREEjr_libs:r_0805
13 | R1 | 470R | KlokTHREEjr_libs:r_0805
 | R2 | 470R | KlokTHREEjr_libs:r_0805
 | R22 | 470R | KlokTHREEjr_libs:r_0805
 | R16 | 470R | KlokTHREEjr_libs:r_0805
 | R18 | 470R | KlokTHREEjr_libs:r_0805
14 | U131 | 1117-33 | KlokTHREEjr_libs:SOT-223-3_TabPin2
15 | U1 | APA102 | KlokTHREEjr_libs:APA102
 | U2 | APA102 | KlokTHREEjr_libs:APA102
 | U3 | APA102 | KlokTHREEjr_libs:APA102
 | U4 | APA102 | KlokTHREEjr_libs:APA102
 | U5 | APA102 | KlokTHREEjr_libs:APA102
 | U6 | APA102 | KlokTHREEjr_libs:APA102
 | U7 | APA102 | KlokTHREEjr_libs:APA102
 | U8 | APA102 | KlokTHREEjr_libs:APA102
 | U9 | APA102 | KlokTHREEjr_libs:APA102
 | U10 | APA102 | KlokTHREEjr_libs:APA102
 | U11 | APA102 | KlokTHREEjr_libs:APA102
 | U12 | APA102 | KlokTHREEjr_libs:APA102
 | U13 | APA102 | KlokTHREEjr_libs:APA102
 | U14 | APA102 | KlokTHREEjr_libs:APA102
 | U15 | APA102 | KlokTHREEjr_libs:APA102
 | U16 | APA102 | KlokTHREEjr_libs:APA102
 | U17 | APA102 | KlokTHREEjr_libs:APA102
 | U18 | APA102 | KlokTHREEjr_libs:APA102
 | U19 | APA102 | KlokTHREEjr_libs:APA102
 | U20 | APA102 | KlokTHREEjr_libs:APA102
 | U21 | APA102 | KlokTHREEjr_libs:APA102
 | U22 | APA102 | KlokTHREEjr_libs:APA102
 | U23 | APA102 | KlokTHREEjr_libs:APA102
 | U24 | APA102 | KlokTHREEjr_libs:APA102
 | U25 | APA102 | KlokTHREEjr_libs:APA102
 | U26 | APA102 | KlokTHREEjr_libs:APA102
 | U27 | APA102 | KlokTHREEjr_libs:APA102
 | U28 | APA102 | KlokTHREEjr_libs:APA102
 | U29 | APA102 | KlokTHREEjr_libs:APA102
 | U30 | APA102 | KlokTHREEjr_libs:APA102
 | U31 | APA102 | KlokTHREEjr_libs:APA102
 | U32 | APA102 | KlokTHREEjr_libs:APA102
 | U33 | APA102 | KlokTHREEjr_libs:APA102
 | U34 | APA102 | KlokTHREEjr_libs:APA102
 | U35 | APA102 | KlokTHREEjr_libs:APA102
 | U36 | APA102 | KlokTHREEjr_libs:APA102
 | U37 | APA102 | KlokTHREEjr_libs:APA102
 | U38 | APA102 | KlokTHREEjr_libs:APA102
 | U39 | APA102 | KlokTHREEjr_libs:APA102
 | U40 | APA102 | KlokTHREEjr_libs:APA102
 | U41 | APA102 | KlokTHREEjr_libs:APA102
 | U42 | APA102 | KlokTHREEjr_libs:APA102
 | U43 | APA102 | KlokTHREEjr_libs:APA102
 | U44 | APA102 | KlokTHREEjr_libs:APA102
 | U45 | APA102 | KlokTHREEjr_libs:APA102
 | U46 | APA102 | KlokTHREEjr_libs:APA102
 | U47 | APA102 | KlokTHREEjr_libs:APA102
 | U48 | APA102 | KlokTHREEjr_libs:APA102
 | U49 | APA102 | KlokTHREEjr_libs:APA102
 | U50 | APA102 | KlokTHREEjr_libs:APA102
 | U51 | APA102 | KlokTHREEjr_libs:APA102
 | U52 | APA102 | KlokTHREEjr_libs:APA102
 | U53 | APA102 | KlokTHREEjr_libs:APA102
 | U54 | APA102 | KlokTHREEjr_libs:APA102
 | U55 | APA102 | KlokTHREEjr_libs:APA102
 | U56 | APA102 | KlokTHREEjr_libs:APA102
 | U57 | APA102 | KlokTHREEjr_libs:APA102
 | U58 | APA102 | KlokTHREEjr_libs:APA102
 | U59 | APA102 | KlokTHREEjr_libs:APA102
 | U60 | APA102 | KlokTHREEjr_libs:APA102
 | U61 | APA102 | KlokTHREEjr_libs:APA102
 | U62 | APA102 | KlokTHREEjr_libs:APA102
 | U63 | APA102 | KlokTHREEjr_libs:APA102
 | U64 | APA102 | KlokTHREEjr_libs:APA102
 | U65 | APA102 | KlokTHREEjr_libs:APA102
 | U66 | APA102 | KlokTHREEjr_libs:APA102
 | U67 | APA102 | KlokTHREEjr_libs:APA102
 | U68 | APA102 | KlokTHREEjr_libs:APA102
 | U69 | APA102 | KlokTHREEjr_libs:APA102
 | U70 | APA102 | KlokTHREEjr_libs:APA102
 | U71 | APA102 | KlokTHREEjr_libs:APA102
 | U72 | APA102 | KlokTHREEjr_libs:APA102
 | U73 | APA102 | KlokTHREEjr_libs:APA102
 | U74 | APA102 | KlokTHREEjr_libs:APA102
 | U75 | APA102 | KlokTHREEjr_libs:APA102
 | U76 | APA102 | KlokTHREEjr_libs:APA102
 | U77 | APA102 | KlokTHREEjr_libs:APA102
 | U78 | APA102 | KlokTHREEjr_libs:APA102
 | U79 | APA102 | KlokTHREEjr_libs:APA102
 | U80 | APA102 | KlokTHREEjr_libs:APA102
 | U81 | APA102 | KlokTHREEjr_libs:APA102
 | U82 | APA102 | KlokTHREEjr_libs:APA102
 | U83 | APA102 | KlokTHREEjr_libs:APA102
 | U84 | APA102 | KlokTHREEjr_libs:APA102
 | U85 | APA102 | KlokTHREEjr_libs:APA102
 | U86 | APA102 | KlokTHREEjr_libs:APA102
 | U87 | APA102 | KlokTHREEjr_libs:APA102
 | U88 | APA102 | KlokTHREEjr_libs:APA102
 | U89 | APA102 | KlokTHREEjr_libs:APA102
 | U90 | APA102 | KlokTHREEjr_libs:APA102
 | U91 | APA102 | KlokTHREEjr_libs:APA102
 | U92 | APA102 | KlokTHREEjr_libs:APA102
 | U93 | APA102 | KlokTHREEjr_libs:APA102
 | U94 | APA102 | KlokTHREEjr_libs:APA102
 | U95 | APA102 | KlokTHREEjr_libs:APA102
 | U96 | APA102 | KlokTHREEjr_libs:APA102
 | U97 | APA102 | KlokTHREEjr_libs:APA102
 | U98 | APA102 | KlokTHREEjr_libs:APA102
 | U99 | APA102 | KlokTHREEjr_libs:APA102
 | U100 | APA102 | KlokTHREEjr_libs:APA102
 | U101 | APA102 | KlokTHREEjr_libs:APA102
 | U102 | APA102 | KlokTHREEjr_libs:APA102
 | U103 | APA102 | KlokTHREEjr_libs:APA102
 | U104 | APA102 | KlokTHREEjr_libs:APA102
 | U105 | APA102 | KlokTHREEjr_libs:APA102
 | U106 | APA102 | KlokTHREEjr_libs:APA102
 | U107 | APA102 | KlokTHREEjr_libs:APA102
 | U108 | APA102 | KlokTHREEjr_libs:APA102
 | U109 | APA102 | KlokTHREEjr_libs:APA102
 | U110 | APA102 | KlokTHREEjr_libs:APA102
 | U111 | APA102 | KlokTHREEjr_libs:APA102
 | U112 | APA102 | KlokTHREEjr_libs:APA102
 | U113 | APA102 | KlokTHREEjr_libs:APA102
 | U114 | APA102 | KlokTHREEjr_libs:APA102
 | U115 | APA102 | KlokTHREEjr_libs:APA102
 | U116 | APA102 | KlokTHREEjr_libs:APA102
 | U117 | APA102 | KlokTHREEjr_libs:APA102
 | U118 | APA102 | KlokTHREEjr_libs:APA102
 | U119 | APA102 | KlokTHREEjr_libs:APA102
 | U120 | APA102 | KlokTHREEjr_libs:APA102
 | U121 | APA102 | KlokTHREEjr_libs:APA102
 | U122 | APA102 | KlokTHREEjr_libs:APA102
 | U123 | APA102 | KlokTHREEjr_libs:APA102
 | U124 | APA102 | KlokTHREEjr_libs:APA102
 | U125 | APA102 | KlokTHREEjr_libs:APA102
 | U126 | APA102 | KlokTHREEjr_libs:APA102
 | U127 | APA102 | KlokTHREEjr_libs:APA102
 | U128 | APA102 | KlokTHREEjr_libs:APA102
16 | BT1 | Batt_RTC | KlokTHREEjr_libs:CR2032_SMD2
17 | U132 | CP2102N-A01-GQFN28 | KlokTHREEjr_libs:QFN-28-1EP_5x5mm_Pitch0.5mm
18 | Q1 | DDC114TU | KlokTHREEjr_libs:SOT-363_SC-70-6
19 | U130 | DS3231N | KlokTHREEjr_libs:DS3231
20 | U129 | ESP-wroom-32 | KlokTHREEjr_libs:esp_wroom_32
21 | LDR1 | LDR | KlokTHREEjr_libs:r_0805_ldr
 | LDR2 | LDR | KlokTHREEjr_libs:r_0805_ldr
22 | D2 | LED_PWR | KlokTHREEjr_libs:LED-0805
23 | D1 | RClamp0854P.TCT | KlokTHREEjr_libs:SOT-143
24 | S4 | SW-BOOT | KlokTHREEjr_libs:SW_SMD
 | S5 | SW-DEC | KlokTHREEjr_libs:SW_SMD
 | S3 | SW-EN | KlokTHREEjr_libs:SW_SMD
 | S1 | SW-ENTER | KlokTHREEjr_libs:SW_SMD
 | S2 | SW-INC | KlokTHREEjr_libs:SW_SMD
 | S6 | SW-MODE | KlokTHREEjr_libs:SW_SMD
25 | P1 | USB_micro | KlokTHREEjr_libs:USB_Micro-B_Molex-105017-0001
 | TP1 | ~RST | KlokTHREEjr_libs:BreakOutPad
 | J1 | CLK_IN | KlokTHREEjr_libs:1pin
 | J9 | CLK_IN | KlokTHREEjr_libs:1pin
 | J2 | DAT_IN | KlokTHREEjr_libs:1pin
 | J10 | DAT_IN | KlokTHREEjr_libs:1pin
 | J18 | 3V3 | KlokTHREEjr_libs:BreakOutPad
 | J23 | GND | KlokTHREEjr_libs:BreakOutPad
 | J8 | GND | KlokTHREEjr_libs:1pin
 | J16 | GND | KlokTHREEjr_libs:1pin
 | J7 | 5V | KlokTHREEjr_libs:1pin
 | J15 | 5V | KlokTHREEjr_libs:1pin
 | TP3 | 32kHz | KlokTHREEjr_libs:BreakOutPad
 | HB1 | hole_baffle | KlokTHREEjr_libs:hole_baffle_2mm
 | HB2 | hole_baffle | KlokTHREEjr_libs:hole_baffle_2mm
 | HB3 | hole_baffle | KlokTHREEjr_libs:hole_baffle_2mm
 | HB4 | hole_baffle | KlokTHREEjr_libs:hole_baffle_2mm
 | HB5 | hole_baffle | KlokTHREEjr_libs:hole_baffle_2mm
 | HB6 | hole_baffle | KlokTHREEjr_libs:hole_baffle_2mm
 | HB7 | hole_baffle | KlokTHREEjr_libs:hole_baffle_2mm
 | HB8 | hole_baffle | KlokTHREEjr_libs:hole_baffle_2mm
 | HB9 | hole_baffle | KlokTHREEjr_libs:hole_baffle_2mm
 | HB10 | hole_baffle | KlokTHREEjr_libs:hole_baffle_2mm
 | HB11 | hole_baffle | KlokTHREEjr_libs:hole_baffle_2mm
 | HB12 | hole_baffle | KlokTHREEjr_libs:hole_baffle_2mm
 | HB13 | hole_baffle | KlokTHREEjr_libs:hole_baffle_2mm
 | HB14 | hole_baffle | KlokTHREEjr_libs:hole_baffle_2mm
 | HB15 | hole_baffle | KlokTHREEjr_libs:hole_baffle_2mm
 | HB16 | hole_baffle | KlokTHREEjr_libs:hole_baffle_2mm
 | HB17 | hole_baffle | KlokTHREEjr_libs:hole_baffle_2mm
 | HB18 | hole_baffle | KlokTHREEjr_libs:hole_baffle_2mm
 | HB19 | hole_baffle | KlokTHREEjr_libs:hole_baffle_2mm
 | HB20 | hole_baffle | KlokTHREEjr_libs:hole_baffle_2mm
 | HB21 | hole_baffle | KlokTHREEjr_libs:hole_baffle_2mm
 | HB22 | hole_baffle | KlokTHREEjr_libs:hole_baffle_2mm
 | HB23 | hole_baffle | KlokTHREEjr_libs:hole_baffle_2mm
 | HB24 | hole_baffle | KlokTHREEjr_libs:hole_baffle_2mm
 | HB25 | hole_baffle | KlokTHREEjr_libs:hole_baffle_2mm
 | HB26 | hole_baffle | KlokTHREEjr_libs:hole_baffle_2mm
 | HB27 | hole_baffle | KlokTHREEjr_libs:hole_baffle_2mm
 | HB28 | hole_baffle | KlokTHREEjr_libs:hole_baffle_2mm
 | HB29 | hole_baffle | KlokTHREEjr_libs:hole_baffle_2mm
 | HB30 | hole_baffle | KlokTHREEjr_libs:hole_baffle_2mm
 | HB31 | hole_baffle | KlokTHREEjr_libs:hole_baffle_2mm
 | HB32 | hole_baffle | KlokTHREEjr_libs:hole_baffle_2mm
 | HB33 | hole_baffle | KlokTHREEjr_libs:hole_baffle_2mm
 | HB34 | hole_baffle | KlokTHREEjr_libs:hole_baffle_2mm
 | HB35 | hole_baffle | KlokTHREEjr_libs:hole_baffle_2mm
 | HB36 | hole_baffle | KlokTHREEjr_libs:hole_baffle_2mm
 | HB37 | hole_baffle | KlokTHREEjr_libs:hole_baffle_2mm
 | HB38 | hole_baffle | KlokTHREEjr_libs:hole_baffle_2mm
 | HB39 | hole_baffle | KlokTHREEjr_libs:hole_baffle_2mm
 | HB40 | hole_baffle | KlokTHREEjr_libs:hole_baffle_2mm
 | HB41 | hole_baffle | KlokTHREEjr_libs:hole_baffle_2mm
 | HB42 | hole_baffle | KlokTHREEjr_libs:hole_baffle_2mm
 | HB43 | hole_baffle | KlokTHREEjr_libs:hole_baffle_2mm
 | HB44 | hole_baffle | KlokTHREEjr_libs:hole_baffle_2mm
 | J24 | I2C_ext1 | KlokTHREEjr_libs:Header_4x1
 | J25 | I2C_ext2 | KlokTHREEjr_libs:Header_4x1
 | G2 | KiCad | KlokTHREEjr_libs:KiCad-Logo2_6mm_SilkScreen
 | G8 | KiCad | KlokTHREEjr_libs:KiCad-Logo2_6mm_SilkScreen
 | JP1 | LED_PWR_EN | KlokTHREEjr_libs:R_0402
 | G1 | LOGO_WL | KlokTHREEjr_libs:Logo-WL3
 | G7 | LOGO_WL | KlokTHREEjr_libs:Logo-WL3
 | J17 | MISO | KlokTHREEjr_libs:BreakOutPad
 | J21 | MOSI | KlokTHREEjr_libs:BreakOutPad
 | BITE1 | Mouse_Bite | KlokTHREEjr_libs:mouse-bite-2.54mm-slot_OSH
 | BITE2 | Mouse_Bite | KlokTHREEjr_libs:mouse-bite-2.54mm-slot_OSH
 | BITE5 | Mouse_Bite | KlokTHREEjr_libs:mouse-bite-2.54mm-slot_OSH
 | BITE6 | Mouse_Bite | KlokTHREEjr_libs:mouse-bite-2.54mm-slot_OSH
 | BITE7 | Mouse_Bite | KlokTHREEjr_libs:mouse-bite-2.54mm-slot_OSH
 | BITE8 | Mouse_Bite | KlokTHREEjr_libs:mouse-bite-2.54mm-slot_OSH
 | BITE3 | Mouse_Bite | KlokTHREEjr_libs:mouse-bite-2.54mm-slot_OSH
 | BITE4 | Mouse_Bite | KlokTHREEjr_libs:mouse-bite-2.54mm-slot_OSH
 | HB47 | mtg_hole_3mm | KlokTHREEjr_libs:MountingHole_3.2mm_M3_Pad_Via
 | HB48 | mtg_hole_3mm | KlokTHREEjr_libs:MountingHole_3.2mm_M3_Pad_Via
 | HB49 | mtg_hole_3mm | KlokTHREEjr_libs:MountingHole_3.2mm_M3_Pad_Via
 | HB50 | mtg_hole_3mm | KlokTHREEjr_libs:MountingHole_3.2mm_M3_Pad_Via
 | HB51 | mtg_hole_3mm | KlokTHREEjr_libs:MountingHole_3.2mm_M3_Pad_Via
 | HB52 | mtg_hole_3mm | KlokTHREEjr_libs:MountingHole_3.2mm_M3_Pad_Via
 | HB53 | mtg_hole_3mm | KlokTHREEjr_libs:MountingHole_3.2mm_M3_Pad_Via
 | HB54 | mtg_hole_3mm | KlokTHREEjr_libs:MountingHole_3.2mm_M3_Pad_Via
 | HB45 | mtg_hole_3mm_small | KlokTHREEjr_libs:MountingHole_3.2mm_M3
 | HB46 | mtg_hole_3mm_small | KlokTHREEjr_libs:MountingHole_3.2mm_M3
 | G3 | OSHW | KlokTHREEjr_libs:OSHW_6mm
 | G9 | OSHW | KlokTHREEjr_libs:OSHW_6mm
 | P2 | OUT_CLK_DAT | KlokTHREEjr_libs:Pin_Header_Straight_1x02
 | J22 | RST | KlokTHREEjr_libs:BreakOutPad
 | J19 | SCK | KlokTHREEjr_libs:BreakOutPad
 | J20 | SPI | KlokTHREEjr_libs:Header_ISP
 | TP2 | SQR | KlokTHREEjr_libs:BreakOutPad

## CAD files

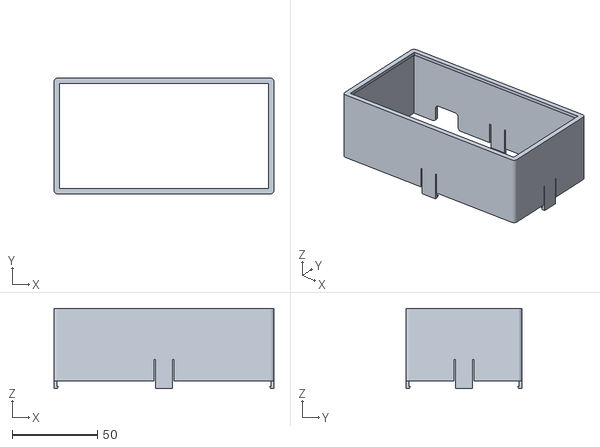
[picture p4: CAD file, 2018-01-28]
fabricate/DesKLOK_case_anool/3d_print_ver/desk_klok_case.stl
128.8 x 67.8 x 46.9

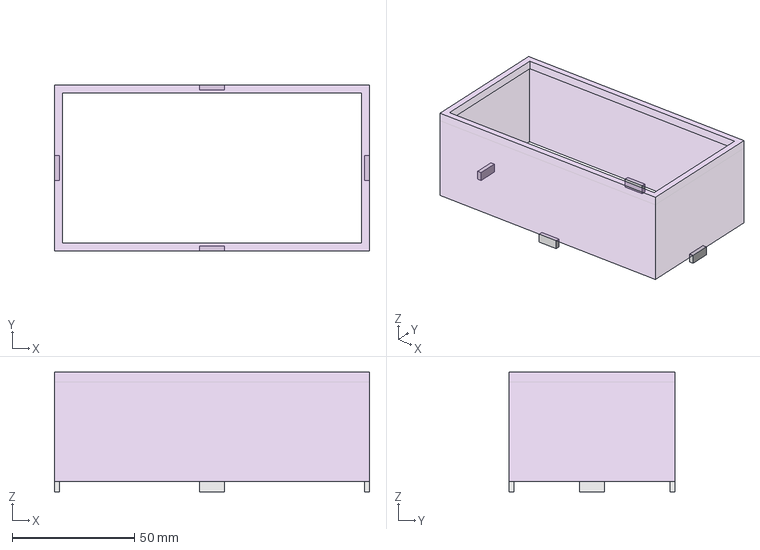
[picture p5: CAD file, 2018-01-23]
fabricate/DesKLOK_case_anool/DesKLOK_case_01.fcstd
128.8 x 67.8 x 49.0 mm

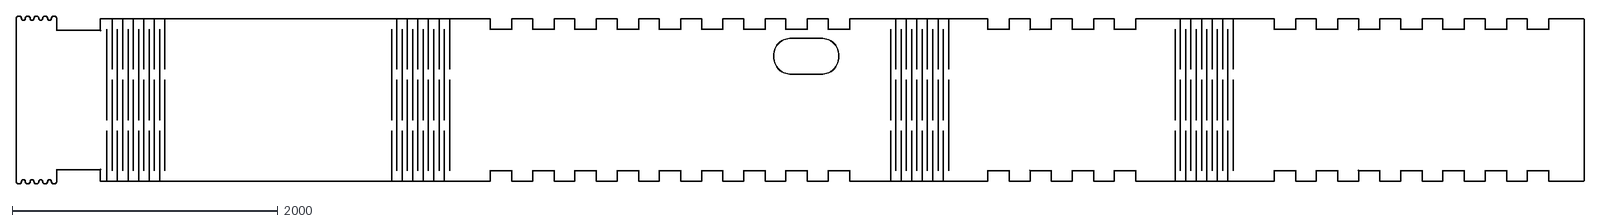
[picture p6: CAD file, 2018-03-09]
fabricate/DesKLOK_case_anool/laser_cut_ver2/desk_klok_FlexBox_side.dxf
11793.5 x 1262.5

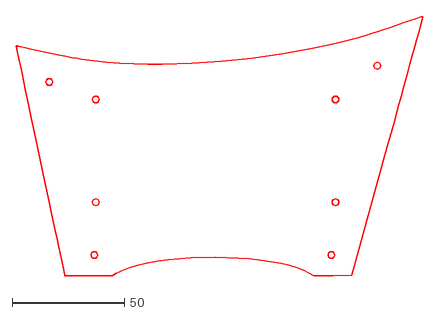
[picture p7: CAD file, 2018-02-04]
fabricate/dulles_clock/dulles_back_plate.dxf
181.6 x 116.0

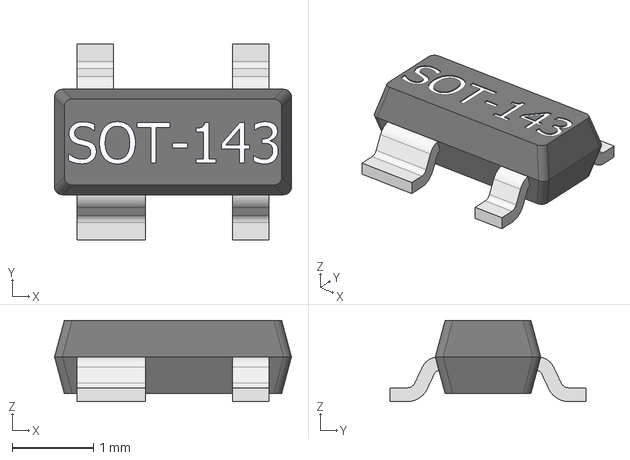
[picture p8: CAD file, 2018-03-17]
k3jr_controller_kicad_v2/3d_modules/SOT-143.step
2.92 x 2.42 x 1.00 mm

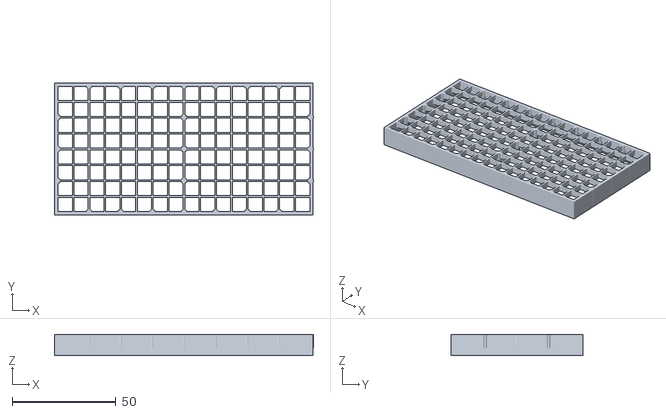
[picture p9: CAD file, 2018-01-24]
fabricate/DesKLOK_case_anool/3d_print_ver/desk_klok_baffle.stl
124.7 x 63.7 x 10.2

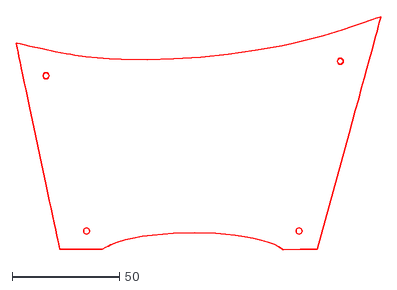
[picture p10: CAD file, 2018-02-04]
fabricate/dulles_clock/dulles_front_plate.dxf
169.8 x 108.4

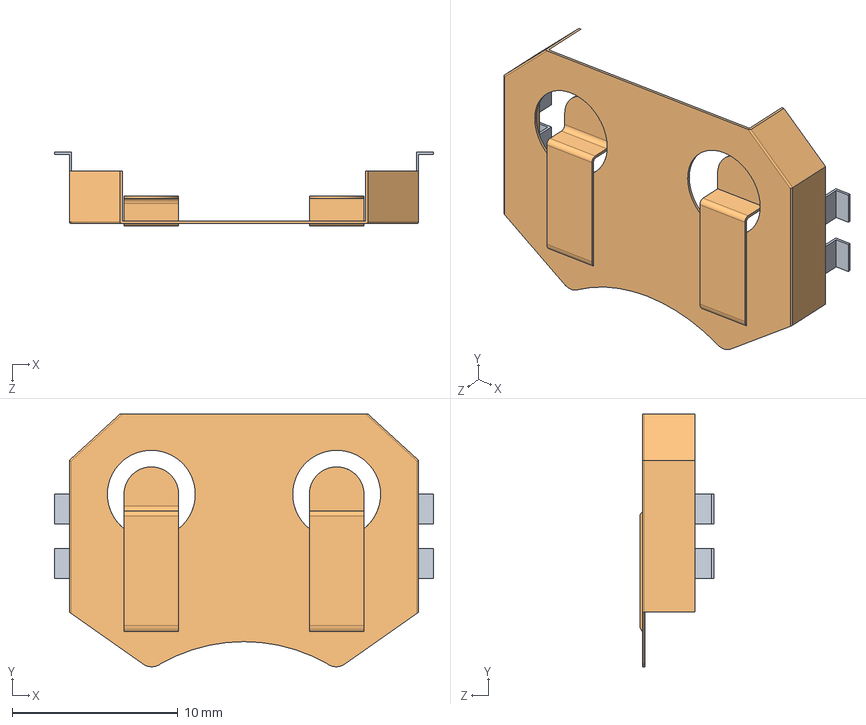
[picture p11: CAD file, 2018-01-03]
k3jr_controller_kicad_v2/3d_modules/bat_2032_BK-912_V1I3.step
22.9 x 15.2 x 4.47 mm
User Library-BK-912_V1I3_1
User Library-BK-912_V1I3_2
User Library-BK-912_V1I3_3
User Library-BK-912_V1I3_4
User Library-BK-912_V1I3_5

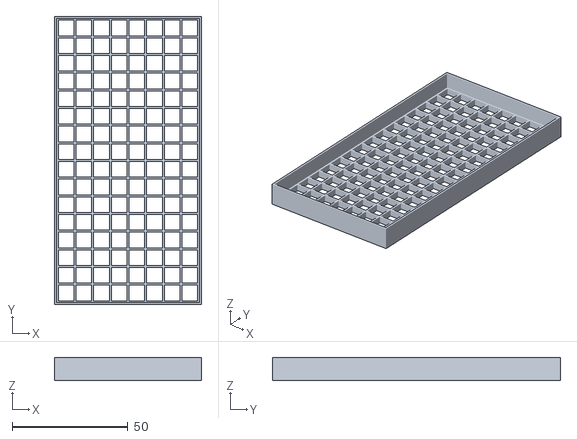
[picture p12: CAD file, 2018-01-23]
fabricate/dulles_clock/ultim8x8baffles.stl
63.4 x 124.4 x 10.0

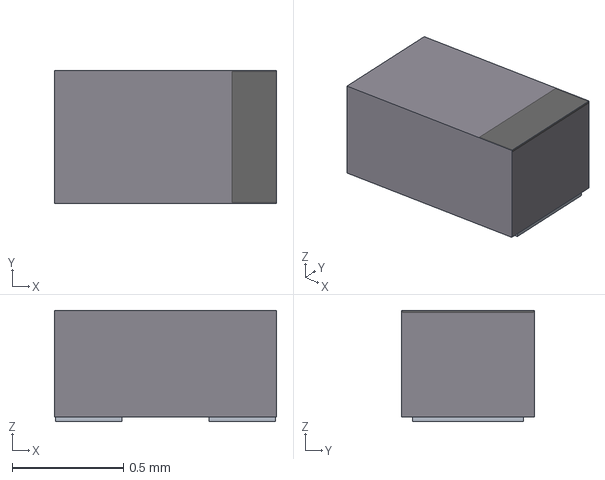
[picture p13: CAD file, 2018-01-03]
k3jr_controller_kicad_v2/3d_modules/D_LLP1006-2L.step
1.00 x 0.6 x 0.5 mm

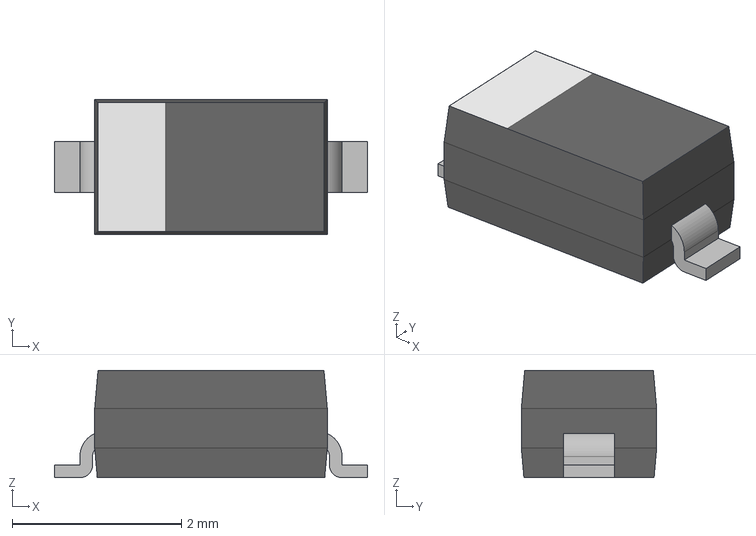
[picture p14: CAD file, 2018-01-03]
k3jr_controller_kicad_v2/3d_modules/D_SOD_123.step
3.70 x 1.60 x 1.27 mm

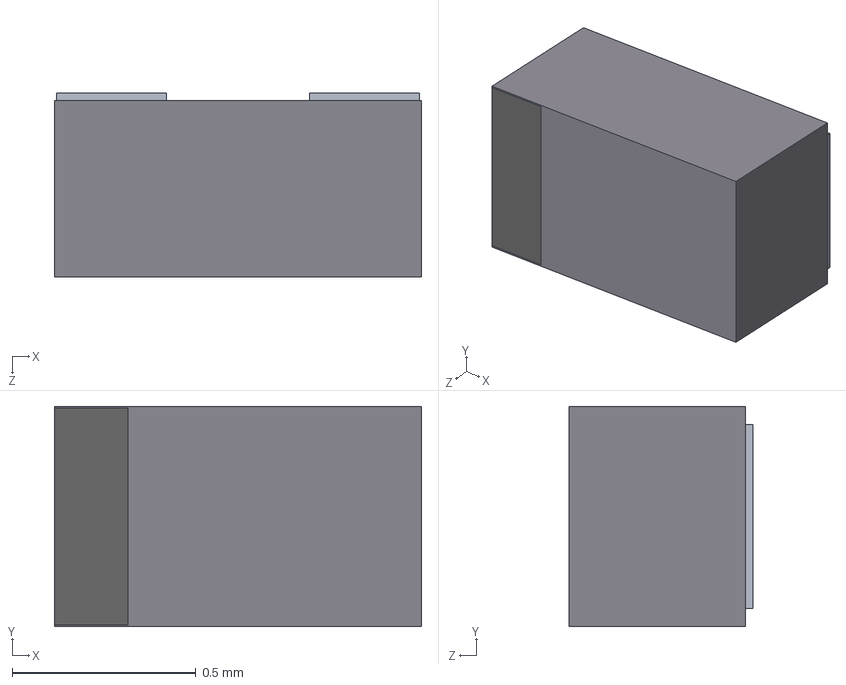
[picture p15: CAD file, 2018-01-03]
k3jr_controller_kicad_v2/3d_modules/D_1006-LLP1006-2L.step
1.00 x 0.6 x 0.5 mm
User Library-D_1006_Pad002
User Library-D_1006_Cut
User Library-D_1006_Pad001

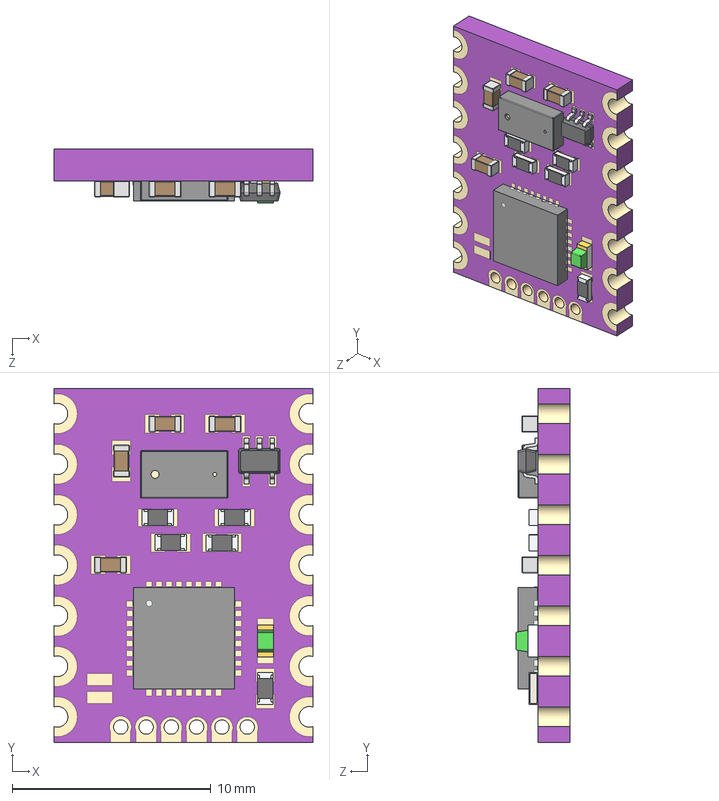
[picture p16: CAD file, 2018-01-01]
k3jr_controller_kicad_v2/3d_modules/MappyDot.step
13.0 x 17.8 x 2.70 mm
mappydot
User Library-CR1608-0603_Predeterminado x 5
User Library-cap_0603-1___ _________ x 4
User Library-led0603_GRE_Domyslna
User Library-VQFN-32
User Library-sot353___ _________
vl53l0x

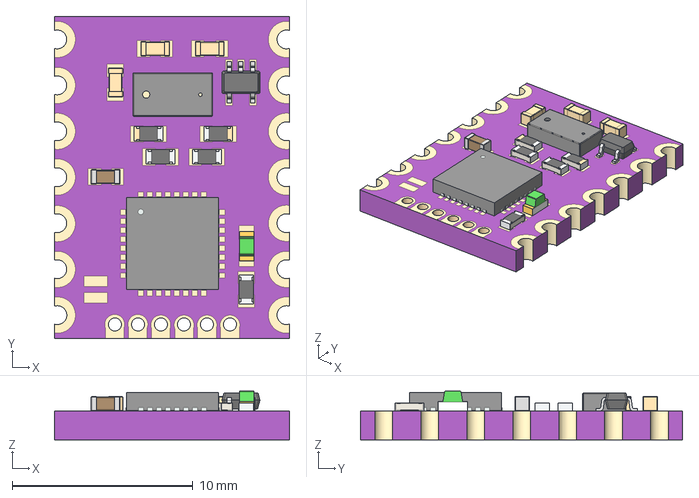
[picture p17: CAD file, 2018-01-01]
k3jr_controller_kicad_v2/3d_modules/mappydot1.step
13.0 x 17.8 x 2.70 mm

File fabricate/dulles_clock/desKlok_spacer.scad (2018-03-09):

H = 8;
// H = 37.5 - 20 // with 10mm spacer
difference(){
  cylinder(h=H, d=4 + 1.4, $fn=30);
  translate([0, 0, -1])cylinder(h=H + 2, d=4, $fn=30);
}

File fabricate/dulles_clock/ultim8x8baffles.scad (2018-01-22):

inch=25.4;
//cube/led width
cw = 7;
led_h = 1.4;
//diagonal separation
//ds = sqrt(2*(cw*cw));
ds = .3*inch;
// ds = 7.7;
L = 8 * ds;
W = 16 * ds;

//baffle height
bh = 3;
bt = .82;

w = .2 * inch;
h = led_h;

module grid(){
  for(yl = [0:ds:17*ds]){
    translate([-cw/2, -ds/2 + yl-bt, led_h])cube([L, bt, bh]);
  } 
  for(xl = [0:ds:8*ds]){
    translate([-cw/2 + xl, -ds/2 - bt, led_h])cube([bt, W + bt, bh]);
  } 

  /*
  translate([(0 + .5) * ds + bt, (1 + .5) * ds - bt/2, 0])rotate(a=45, v=[0, 0, 1])translate([-w/2, -w/2, 0]) cube([w, w, h]);
  translate([(0 + .5) * ds + bt, (13 + .5) * ds - bt/2, 0])rotate(a=45, v=[0, 0, 1])translate([-w/2, -w/2, 0]) cube([w, w, h]);
  translate([(6 + .5) * ds + bt, (1 + .5) * ds - bt/2, 0])rotate(a=45, v=[0, 0, 1])translate([-w/2, -w/2, 0]) cube([w, w, h]);
  translate([(6 + .5) * ds + bt, (13 + .5) * ds - bt/2, 0])rotate(a=45, v=[0, 0, 1])translate([-w/2, -w/2, 0]) cube([w, w, h]);
  
  translate([(0 + .5) * ds + bt, (1 + .5) * ds - bt/2, led_h])cylinder($fn=4, r1=w/2 * sqrt(2), r2=1, h=bh);
  translate([(0 + .5) * ds + bt, (13 + .5) * ds - bt/2, led_h])cylinder($fn=4, r1=w/2 * sqrt(2), r2=1, h=bh);
  translate([(6 + .5) * ds + bt, (1 + .5) * ds - bt/2, led_h])cylinder($fn=4, r1=w/2 * sqrt(2), r2=1, h=bh);
  translate([(6 + .5) * ds + bt, (13 + .5) * ds - bt/2, led_h])cylinder($fn=4, r1=w/2 * sqrt(2), r2=1, h=bh);
  */
  //translate([(1 + .5) * ds, (1 + .5) * ds, 0])rotate(a=45, v=[0, 0, 1])translate([-w/2, -w/2, 0]) cube([w, w, h]);
  //translate([(-2 + .5) * ds, (1 + .5) * ds, led_h])cylinder($fn=4, r1=w/2 * sqrt(2), r2=0, h=bh);
}
translate([-ds/2 + .3, ds/2 + bt, 0])rotate(a=180, v=[0, 1, 0])grid();

translate([-L-bt, 0, -4.41])
difference(){
  translate([-bt, -bt, 0])cube([L + 3 * bt, W + 3 * bt, 10]);
  translate([0, 0, -1])cube([L +     bt, W +     bt, 12]);
}

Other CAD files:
k3jr_controller_kicad_v2/3d_modules/bat_cr2032.step
k3jr_controller_kicad_v2/3d_modules/bat_2032_2.step
k3jr_controller_kicad_v2/3d_modules/QFN28-0_5.step
k3jr_controller_kicad_v2/3d_modules/SOT-223.step
fabricate/DesKLOK_case_anool/laser_cut_ver1/baffles.stl
k3jr_controller_kicad_v1/3d_modules/LED_SMD_APA102.step
k3jr_controller_kicad_v1/3d_modules/LED_SMD_APA102_01.step
k3jr_controller_kicad_v1/3d_modules/LED_SMD_APA102_02.step
k3jr_controller_kicad_v1/3d_modules/MicroUSB-B_Molex_105017-0001.step
k3jr_controller_kicad_v1/3d_modules/QFN-28.step
k3jr_controller_kicad_v1/3d_modules/QFN28-0_5.step
k3jr_controller_kicad_v1/3d_modules/QFN_28_1EP_5x5mm.step
k3jr_controller_kicad_v1/3d_modules/SOD-123.step
k3jr_controller_kicad_v1/3d_modules/SOIC16_Wide.step
k3jr_controller_kicad_v1/3d_modules/SOT-223.step
k3jr_controller_kicad_v1/3d_modules/SOT-363.step
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

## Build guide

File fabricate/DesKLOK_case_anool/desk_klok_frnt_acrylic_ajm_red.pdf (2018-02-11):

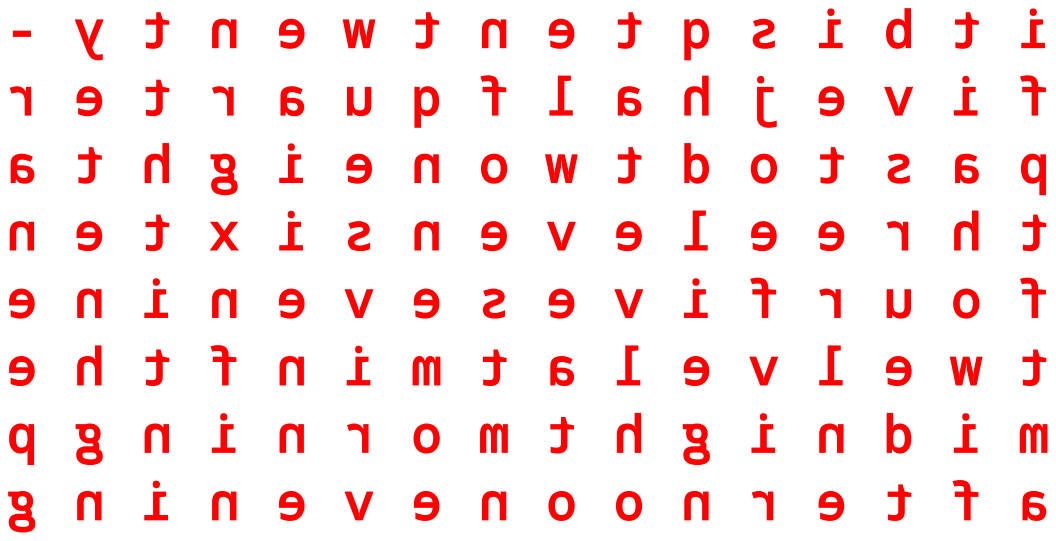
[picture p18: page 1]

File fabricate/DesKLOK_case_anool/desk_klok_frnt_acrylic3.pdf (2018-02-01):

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
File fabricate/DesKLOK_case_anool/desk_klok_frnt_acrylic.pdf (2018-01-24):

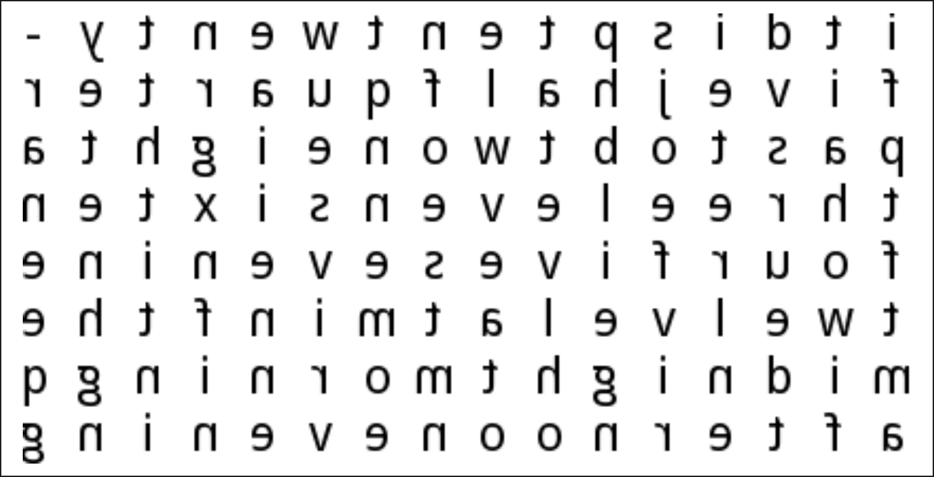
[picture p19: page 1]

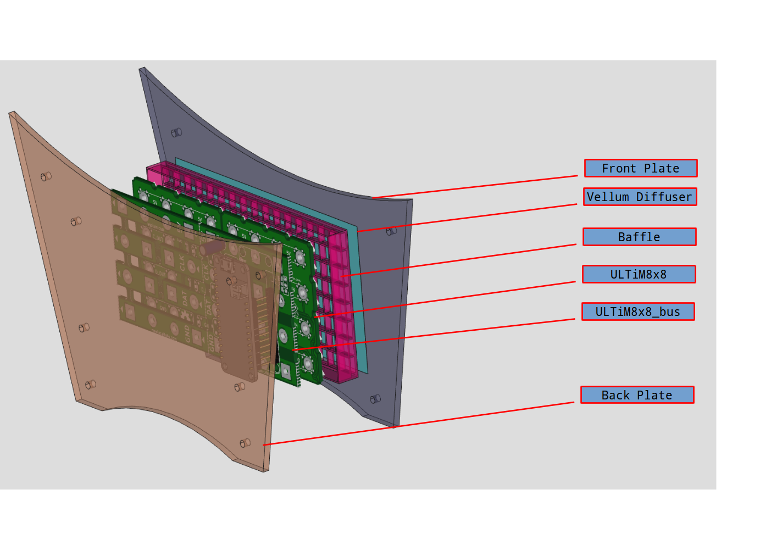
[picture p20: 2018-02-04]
fabricate/dulles_clock/dulles_clock_render_04.png

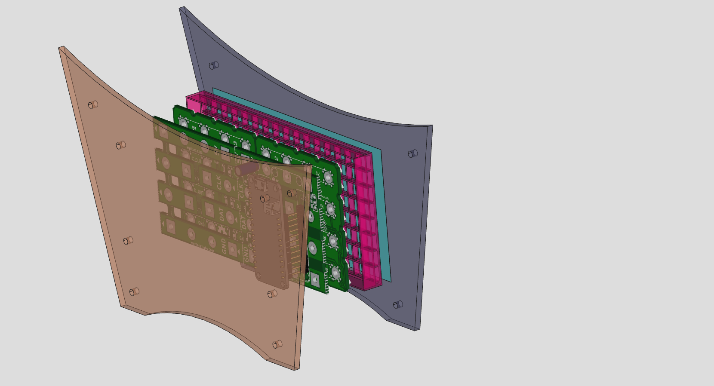
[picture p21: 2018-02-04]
fabricate/dulles_clock/dulles_clock_render_02.png

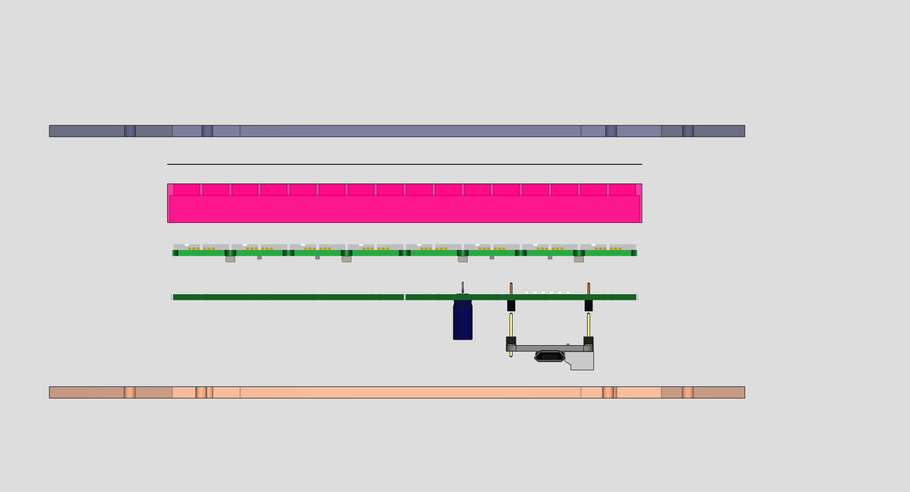
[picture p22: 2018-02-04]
fabricate/dulles_clock/dulles_clock_render_01.png

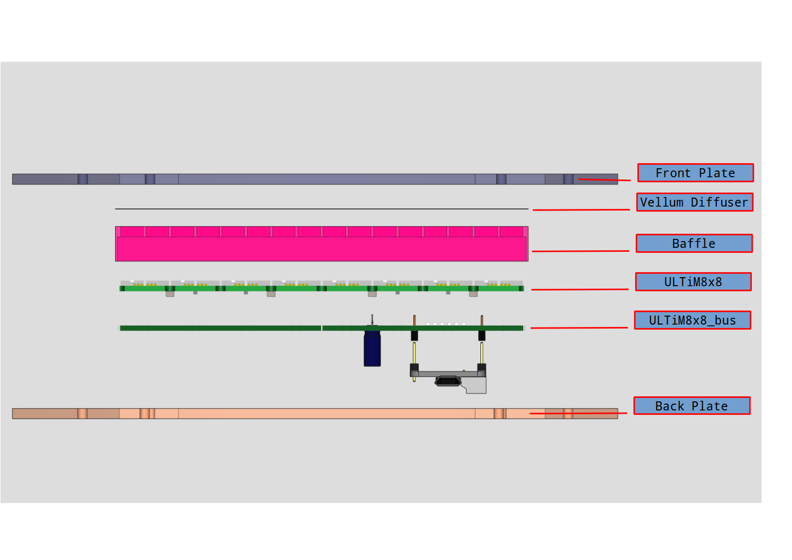
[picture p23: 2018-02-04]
fabricate/dulles_clock/dulles_clock_render_03.png

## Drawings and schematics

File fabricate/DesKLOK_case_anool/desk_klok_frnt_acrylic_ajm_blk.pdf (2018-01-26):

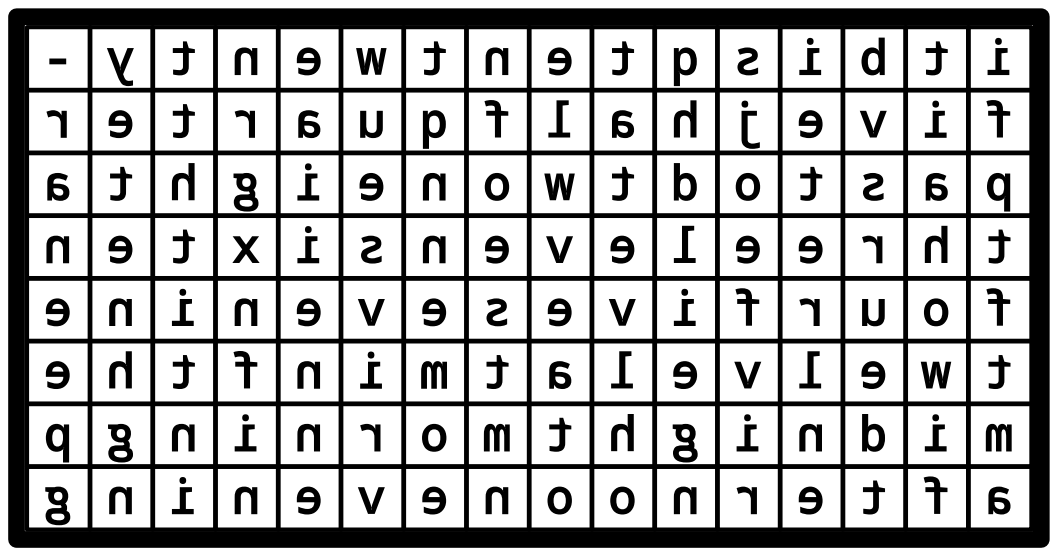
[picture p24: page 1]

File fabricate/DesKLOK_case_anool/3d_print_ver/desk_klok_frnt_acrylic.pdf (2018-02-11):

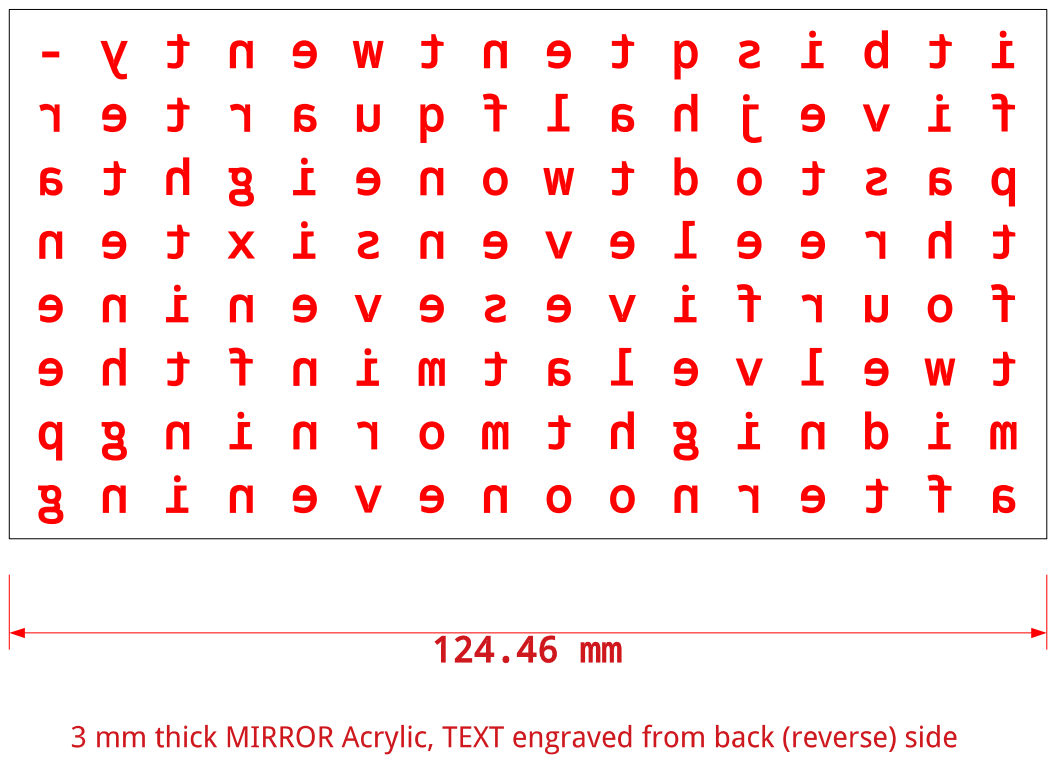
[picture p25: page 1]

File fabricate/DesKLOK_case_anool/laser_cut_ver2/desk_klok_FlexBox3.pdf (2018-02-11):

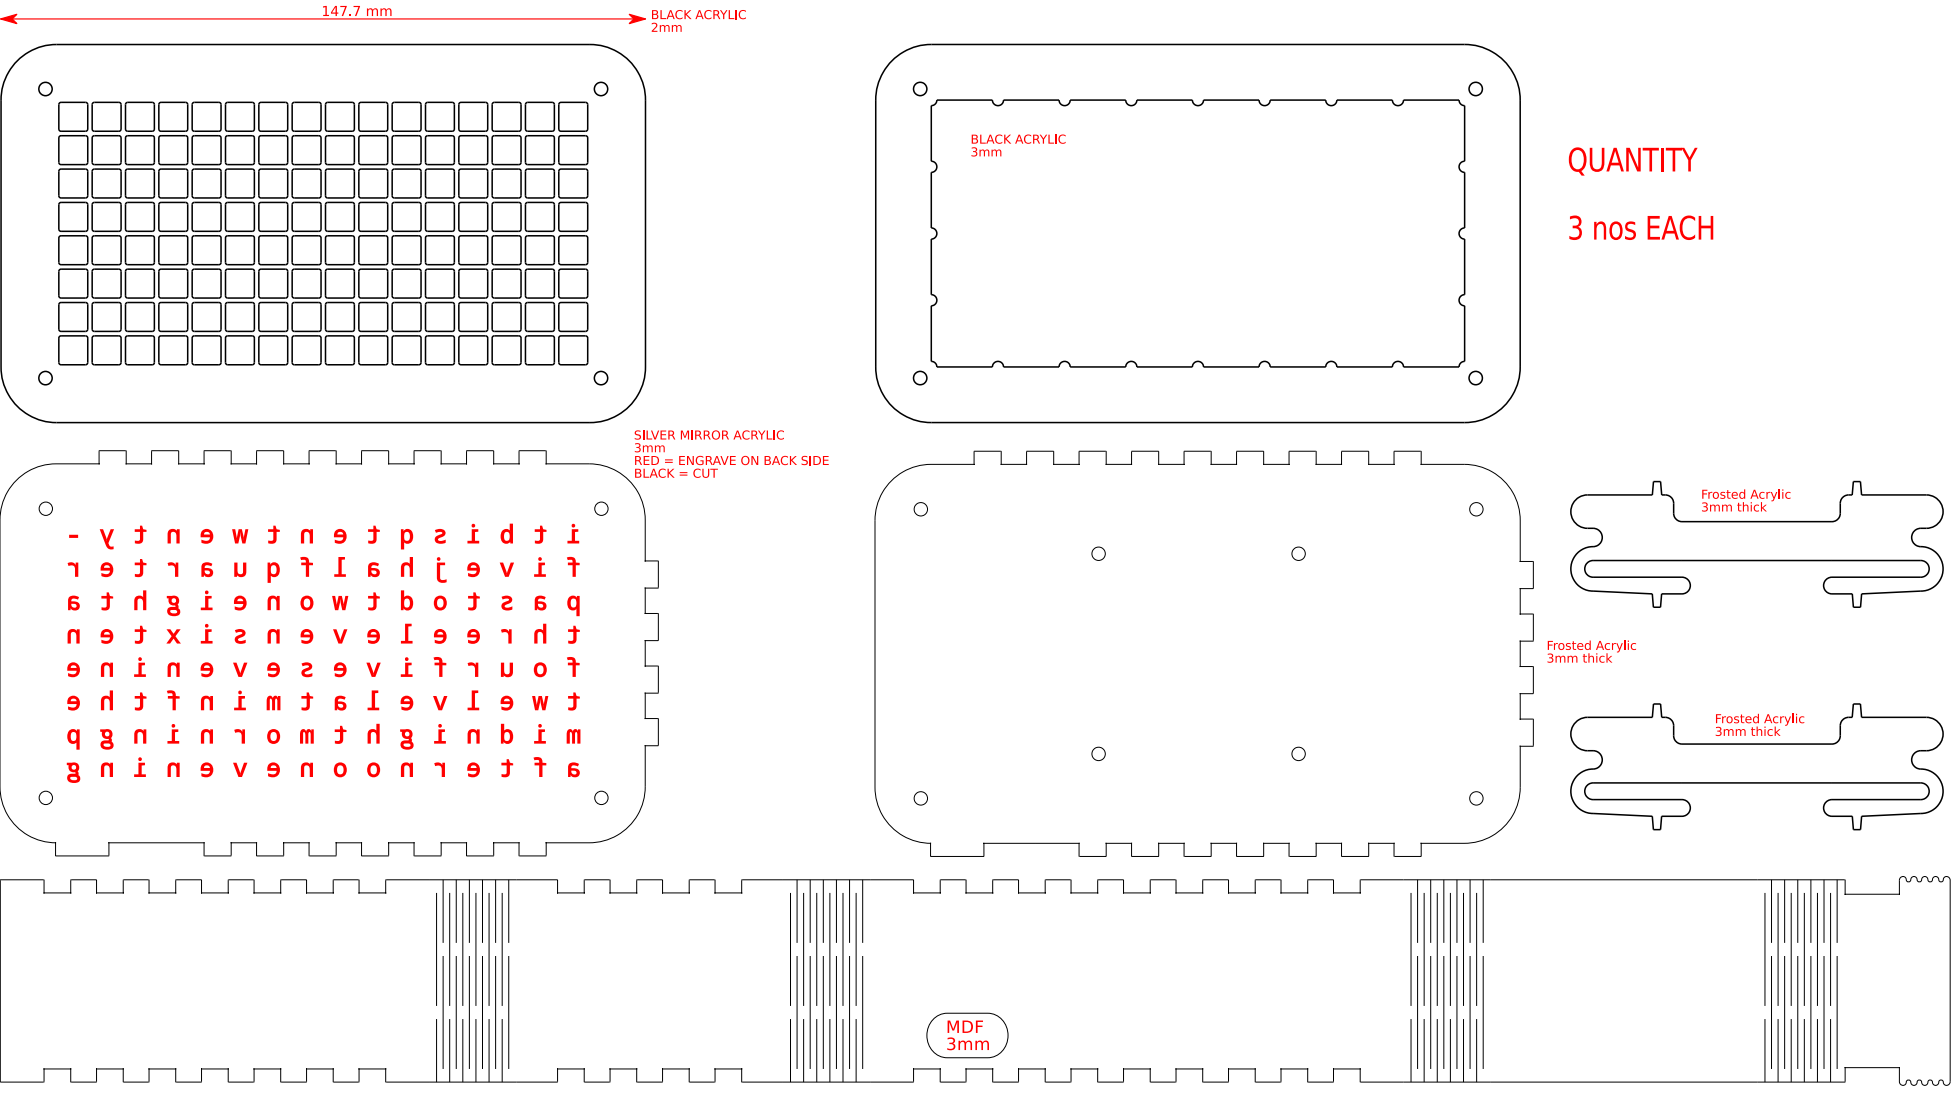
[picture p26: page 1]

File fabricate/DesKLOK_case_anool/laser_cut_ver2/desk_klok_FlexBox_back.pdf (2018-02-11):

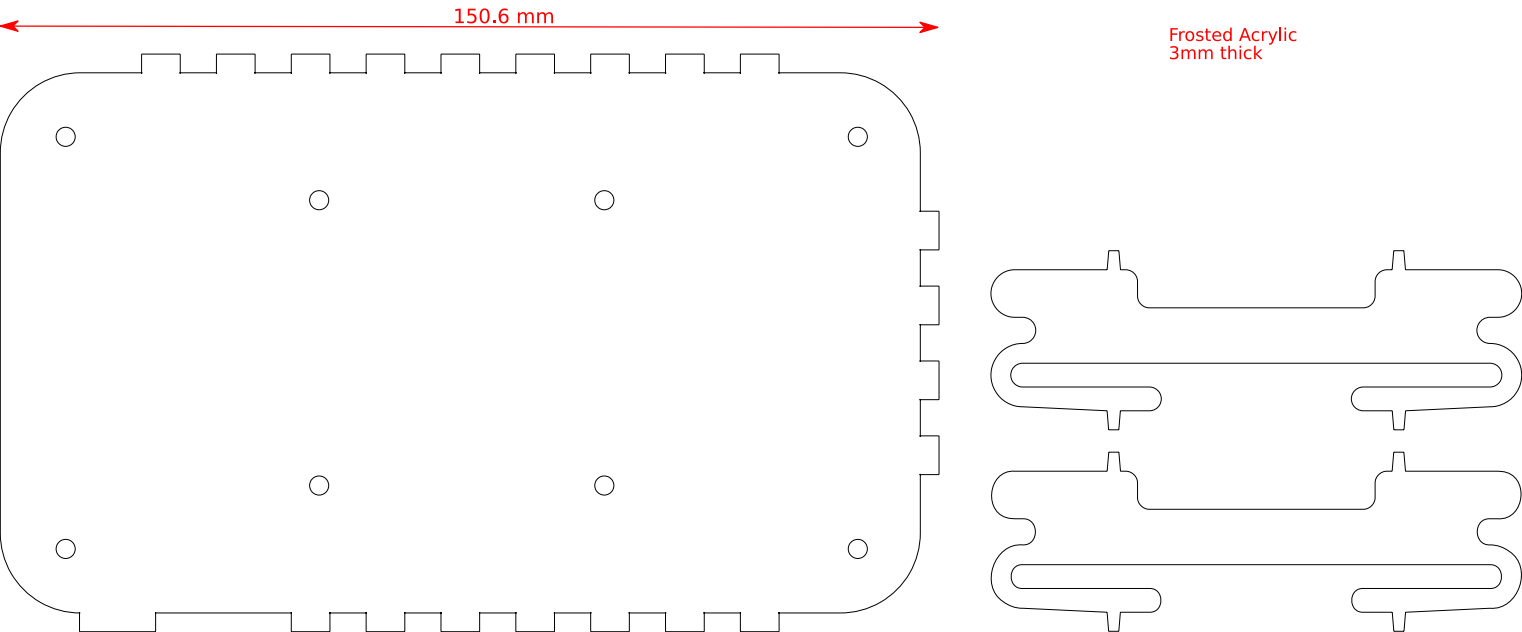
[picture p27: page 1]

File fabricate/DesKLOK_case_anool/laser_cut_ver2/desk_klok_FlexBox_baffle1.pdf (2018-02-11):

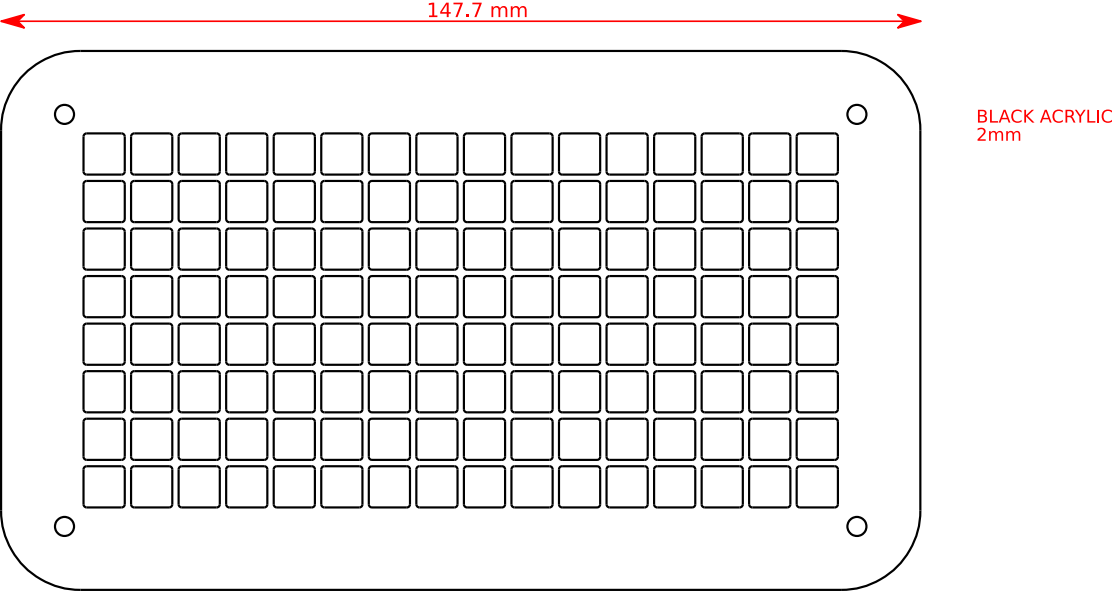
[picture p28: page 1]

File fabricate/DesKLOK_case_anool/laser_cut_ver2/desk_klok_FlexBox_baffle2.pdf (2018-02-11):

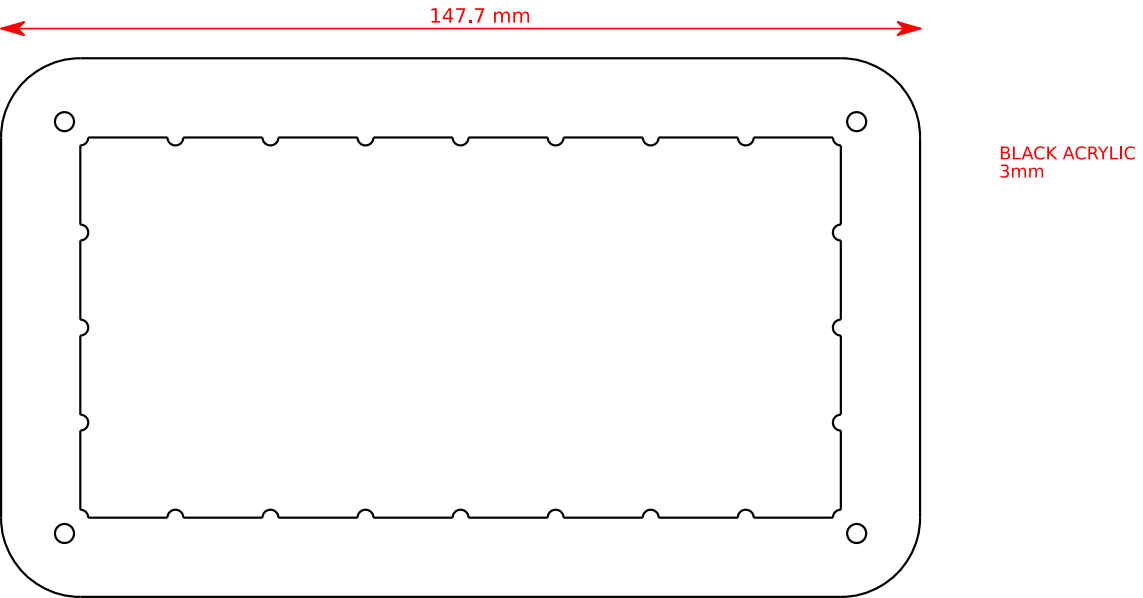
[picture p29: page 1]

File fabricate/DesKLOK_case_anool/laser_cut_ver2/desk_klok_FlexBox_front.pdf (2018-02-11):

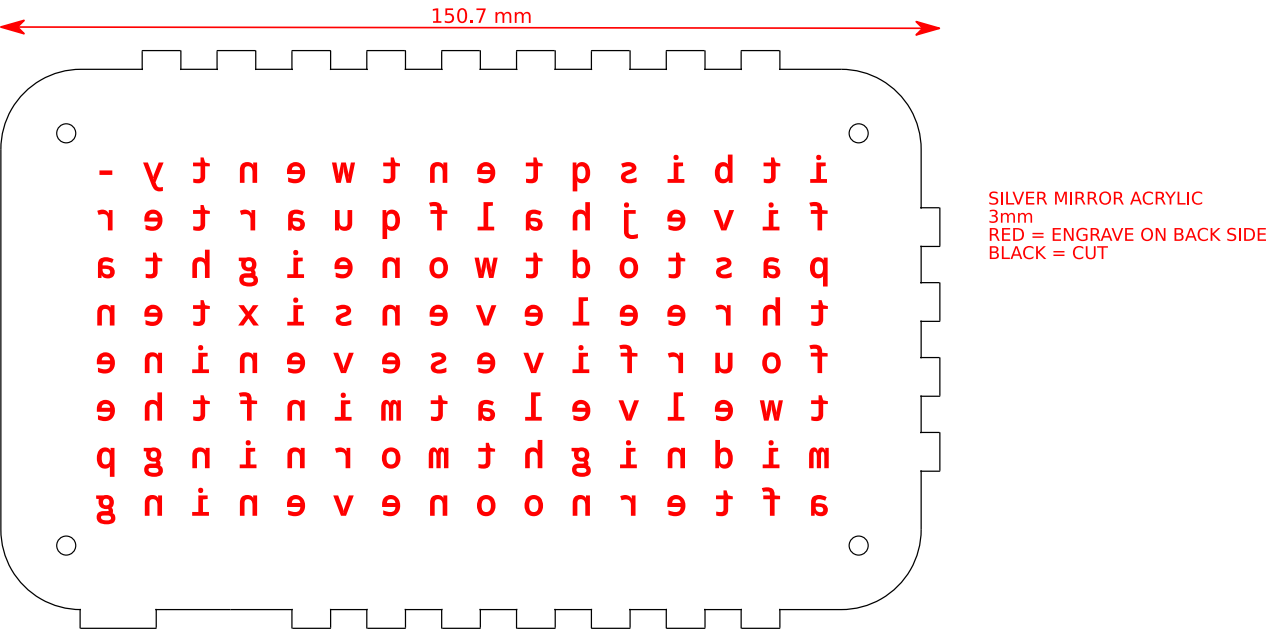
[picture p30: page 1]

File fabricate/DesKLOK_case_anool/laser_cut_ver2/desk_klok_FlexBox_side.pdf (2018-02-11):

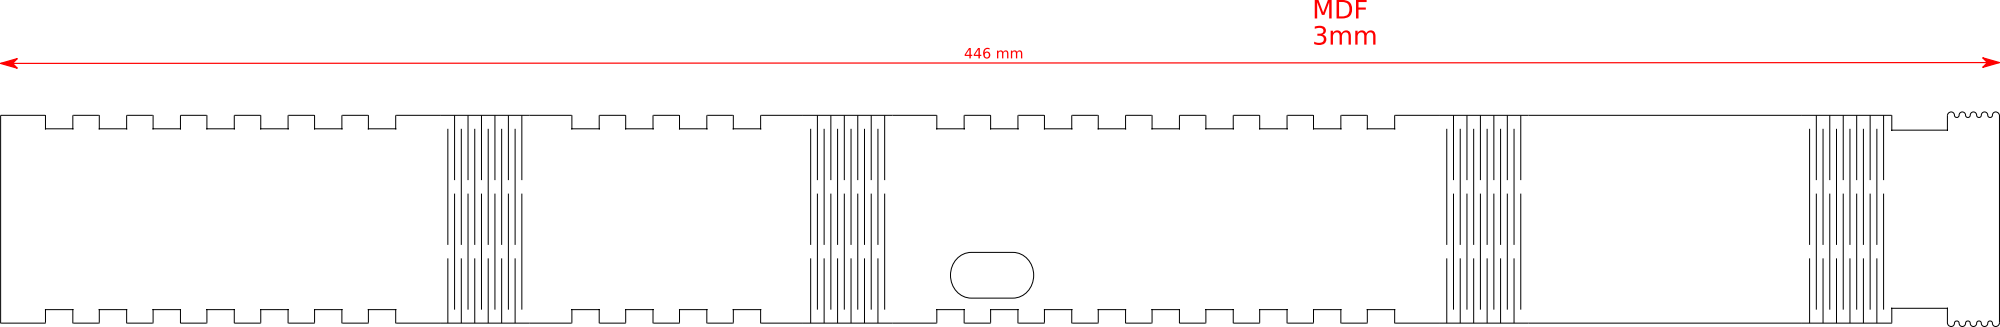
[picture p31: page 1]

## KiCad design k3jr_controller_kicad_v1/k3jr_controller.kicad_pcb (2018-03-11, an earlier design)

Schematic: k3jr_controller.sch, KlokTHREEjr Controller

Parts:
C27: 100uF/6V3; c_2917
C28: 1uF/10V; c_0805
C29, C30, C31: 100nF; c_0805
G1: LOGO_WL; Logo-WL3
G2: KiCad; KiCad-Logo2_6mm_SilkScreen
G3: OSHW; OSHW_6mm
J17: MISO; BreakOutPad
J18: 3V3; BreakOutPad
J19: SCK; BreakOutPad
J20: SPI; Header_ISP
J21: MOSI; BreakOutPad
J22: RST; BreakOutPad
J23: GND; BreakOutPad
J24: I2C_ext1; Header_4x1
J25: I2C_ext2; Header_4x1
R10, R11, R24, R25: 10k; r_0805
S1: SW-ENTER; SW_SMD
S2: SW-INC; SW_SMD
S5: SW-DEC; SW_SMD
S6: SW-MODE; SW_SMD
U129: ESP-wroom-32; esp_wroom_32

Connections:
/3V3: C27.1, C28.1, C29.1, C30.1, C31.1, J18.1, J20.2, J24.3, J25.3, U129.2; also elsewhere on the board
/5V: S1.1, S1.3, S2.1, S2.3, S5.1, S5.3, S6.1, S6.3; also elsewhere on the board
/CLK: U129.20
/CLK_IN: U129.27; also elsewhere on the board
/CMD: U129.19
/DAT_IN: U129.26; also elsewhere on the board
/EN: U129.3; also elsewhere on the board
/IO0: U129.25; also elsewhere on the board
/IO2: U129.24
/IO12: U129.14
/IO13: U129.16; also elsewhere on the board
/IO14: U129.13
/IO15: U129.23; also elsewhere on the board
/IO23: U129.37
/IO27: U129.12
/IO34: U129.6
/IO35: U129.7
/LDR1: U129.11; also elsewhere on the board
/LDR2: U129.8; also elsewhere on the board
/LDR3: U129.9; also elsewhere on the board
/LDR4: U129.10; also elsewhere on the board
/MISO: J17.1, J20.1
/MOSI: J20.4, J21.1
/NC: U129.32
/RST: J20.5, J22.1
/RXD0: U129.34; also elsewhere on the board
/SCK: J19.1, J20.3
/SCL: J24.1, J25.1, U129.36; also elsewhere on the board
/SD2: U129.17
/SD3: U129.18
/SDA: J24.2, J25.2, U129.33; also elsewhere on the board
/SDI: U129.22
/SDO: U129.21
/SENSOR_VN: U129.5
/SENSOR_VP: U129.4
/SW_D: R24.1, S5.2, S5.4, U129.29
/SW_E: R10.1, S1.2, S1.4, U129.31
/SW_I: R11.1, S2.2, S2.4, U129.30
/SW_M: R25.1, S6.2, S6.4, U129.28
/TXD0: U129.35; also elsewhere on the board
GND: C27.2, C28.2, C29.2, C30.2, C31.2, J20.6, J23.1, J24.4, J25.4, R10.2, R11.2, R24.2, R25.2, U129.1, U129.15, U129.38, U129.39; also elsewhere on the board

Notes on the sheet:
Push Buttons
BUTTONS
LED CLK/DAT
I2C
SERIAL
LDR
Native SPI pins are (clk, mosi, miso, cs): SPI1: 6, 8, 7, 11 HSPI: 14,13,12,15 VSPI: 18,23,19, 5 If using native pins max SPI clock can be set to 80 MHZ. Only HSPI & VSPI are supported by esp-idf driver.
SPI header with breakout pins. Connect with wire to appropriate pins on ESP32
I2C interface for external connections to sensors etc.
SPI HEADER
I2C HEADER

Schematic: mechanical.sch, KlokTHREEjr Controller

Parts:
G4: LOGO_WL; Logo-WL3
G5: KiCad; KiCad-Logo2_6mm_SilkScreen
G6: OSHW; OSHW_6mm
HB45, HB46: mtg_hole_3mm_small; MountingHole_3.2mm_M3
HB47, HB48: mtg_hole_3mm; MountingHole_3.2mm_M3_Pad_Via
J1: CLK_IN; 1pin
J2: DAT_IN; 1pin
J3: LDR1; 1pin
J4: LDR2; 1pin
J5: LDR3; 1pin
J6: LDR4; 1pin
J7: 5V; 1pin
J8: GND; 1pin

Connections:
/5V: J7.1; also elsewhere on the board
/CLK_IN: J1.1; also elsewhere on the board
/DAT_IN: J2.1; also elsewhere on the board
/LDR1: J3.1; also elsewhere on the board
/LDR2: J4.1; also elsewhere on the board
/LDR3: J5.1; also elsewhere on the board
/LDR4: J6.1; also elsewhere on the board
GND: J8.1; also elsewhere on the board

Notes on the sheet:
<- 6.1" ->
<- 1.35" ->
Mounting holes for C3jr compatibility 3 mm diameter plated
Mounting holes for piggy back attachment of "snap-off" control board. Use M3 HEX posts to connect LED board to control board

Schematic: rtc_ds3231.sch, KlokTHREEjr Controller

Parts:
BT1: Batt_RTC; CR2032_SMD2; Digikey BU2032SM-HD-GCT-ND
C22: 100nF; c_0805
R6, R7: 10k; r_0805
R8, R9: 4K7; r_0805
TP1: ~RST; BreakOutPad
TP2: SQR; BreakOutPad
TP3: 32kHz; BreakOutPad
U130: DS3231N; DS3231

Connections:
/3V3: R6.1, R7.1, R8.1, R9.1, U130.2; also elsewhere on the board
/SCL: R8.2, U130.16; also elsewhere on the board
/SDA: R9.2, U130.15; also elsewhere on the board
/rtc_ds3231/32kHz: R7.2, TP3.1, U130.1
/rtc_ds3231/BAT: BT1.1, C22.1, U130.14
/rtc_ds3231/RESET: TP1.1, U130.4
/rtc_ds3231/SQR: R6.2, TP2.1, U130.3
GND: BT1.2, C22.2, U130.5, U130.6, U130.7, U130.8, U130.9, U130.10, U130.11, U130.12, U130.13; also elsewhere on the board

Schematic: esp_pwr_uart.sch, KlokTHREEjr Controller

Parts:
C17, C23, C25: 10uF/25V; c_2917
C18: 22uF/25V; c_2917
C19, C20, C21: 1nF; c_0805
C24, C26: 100nF; c_0805
D1: 1N5819; D_SOD-123
D2: LED_PWR; LED-0805
D3, D4: VESD05A1B; D_LLP1006-2L
JP1: LED_PWR_EN; R_0402
P1: USB_micro; USB_Micro-B_Molex-105017-0001
Q1: DDC114TU; SOT-363_SC-70-6
R3: 10k; r_0805
R4: 1k; r_0805
R16, R18, R22: 470R; r_0805
R19, R20: 0R NC; r_0805
R21, R23: 0R; r_0805
S3: EN; SW_SMD
S4: BOOT; SW_SMD
U131: 1117-33; SOT-223-3_TabPin2
U132: CP2102N-A01-GQFN28; QFN-28-1EP_5x5mm_Pitch0.5mm

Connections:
/3V3: C18.1, C23.1, C24.1, R3.1, U131.2 (VO), U132.6, U132.7; also elsewhere on the board
/5V: C17.1, C25.1, C26.1, D1.2, R4.1, U131.3 (VI), U132.8; also elsewhere on the board
/DTR: Q1.2, Q1.4, U132.28
/EN: C19.1, Q1.6, R3.2, R16.1; also elsewhere on the board
/IO0: Q1.3, R18.1; also elsewhere on the board
/IO13: R20.1; also elsewhere on the board
/IO15: R19.1; also elsewhere on the board
/RXD0: R23.1; also elsewhere on the board
/TXD0: R21.1; also elsewhere on the board
/esp_pwr_uart/CTS: R19.2, U132.23
/esp_pwr_uart/RTS: Q1.1, Q1.5, R20.2, U132.24
/esp_pwr_uart/RXD: R21.2, U132.25
/esp_pwr_uart/TXD: R22.1, R23.2
/esp_pwr_uart/USB_D+: D3.2, P1.3, U132.4
/esp_pwr_uart/USB_D-: D4.2, P1.2, U132.5
GND: C17.2, C18.2, C19.2, C20.2, C21.2, C23.2, C24.2, C25.2, C26.2, D3.1, D4.1, JP1.1, P1.5, P1.6, S3.2, S3.4, S4.2, S4.4, U131.1 (GND), U132.3, U132.29; also elsewhere on the board
unnamed: C20.1, R16.2, S3.1, S3.3
unnamed: C21.1, R18.2, S4.1, S4.3
unnamed: D1.1, P1.1
unnamed: D2.1, R4.2
unnamed: D2.2, JP1.2
unnamed: R22.2, U132.26

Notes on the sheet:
Auto program DTR RTS-->EN IO0 1 1 1 1 0 0 1 1 1 0 0 1 0 1 1 0

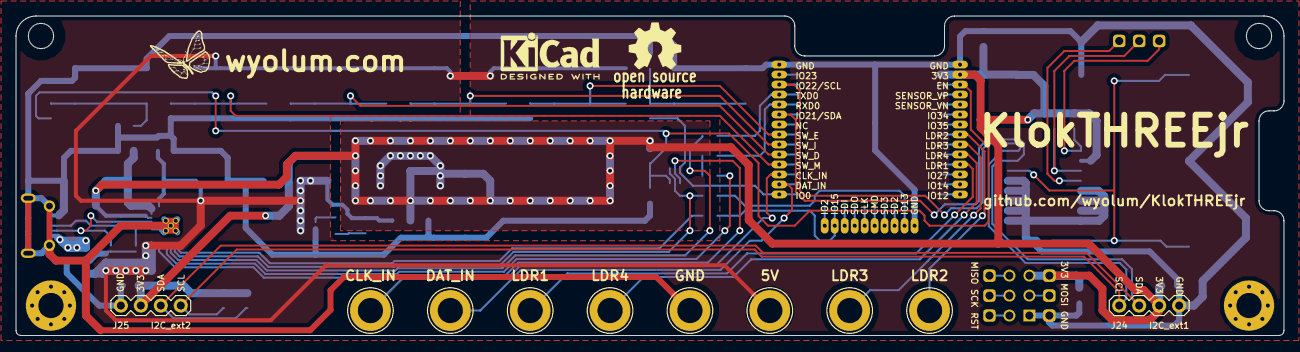
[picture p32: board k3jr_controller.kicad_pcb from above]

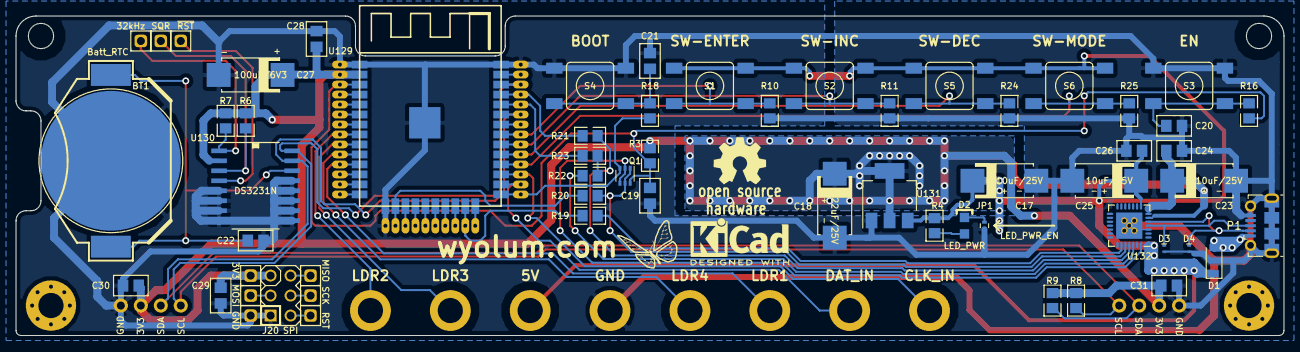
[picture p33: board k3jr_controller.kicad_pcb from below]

Board: 2 copper layers, 161.3 x 40.6 mm, 80 parts (63 on the bottom side), 42 nets.

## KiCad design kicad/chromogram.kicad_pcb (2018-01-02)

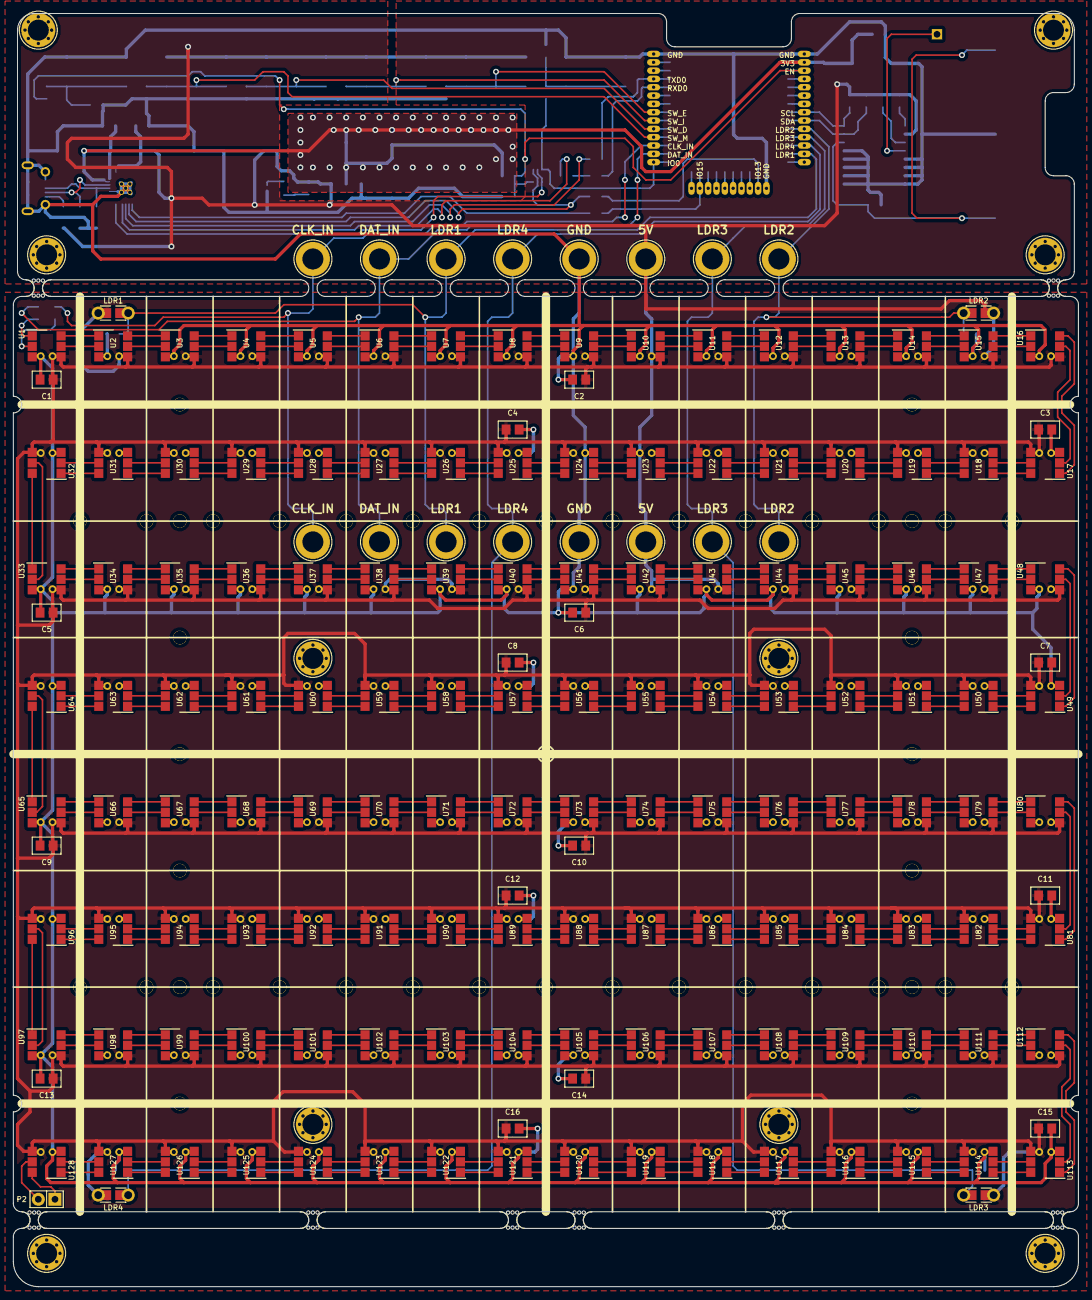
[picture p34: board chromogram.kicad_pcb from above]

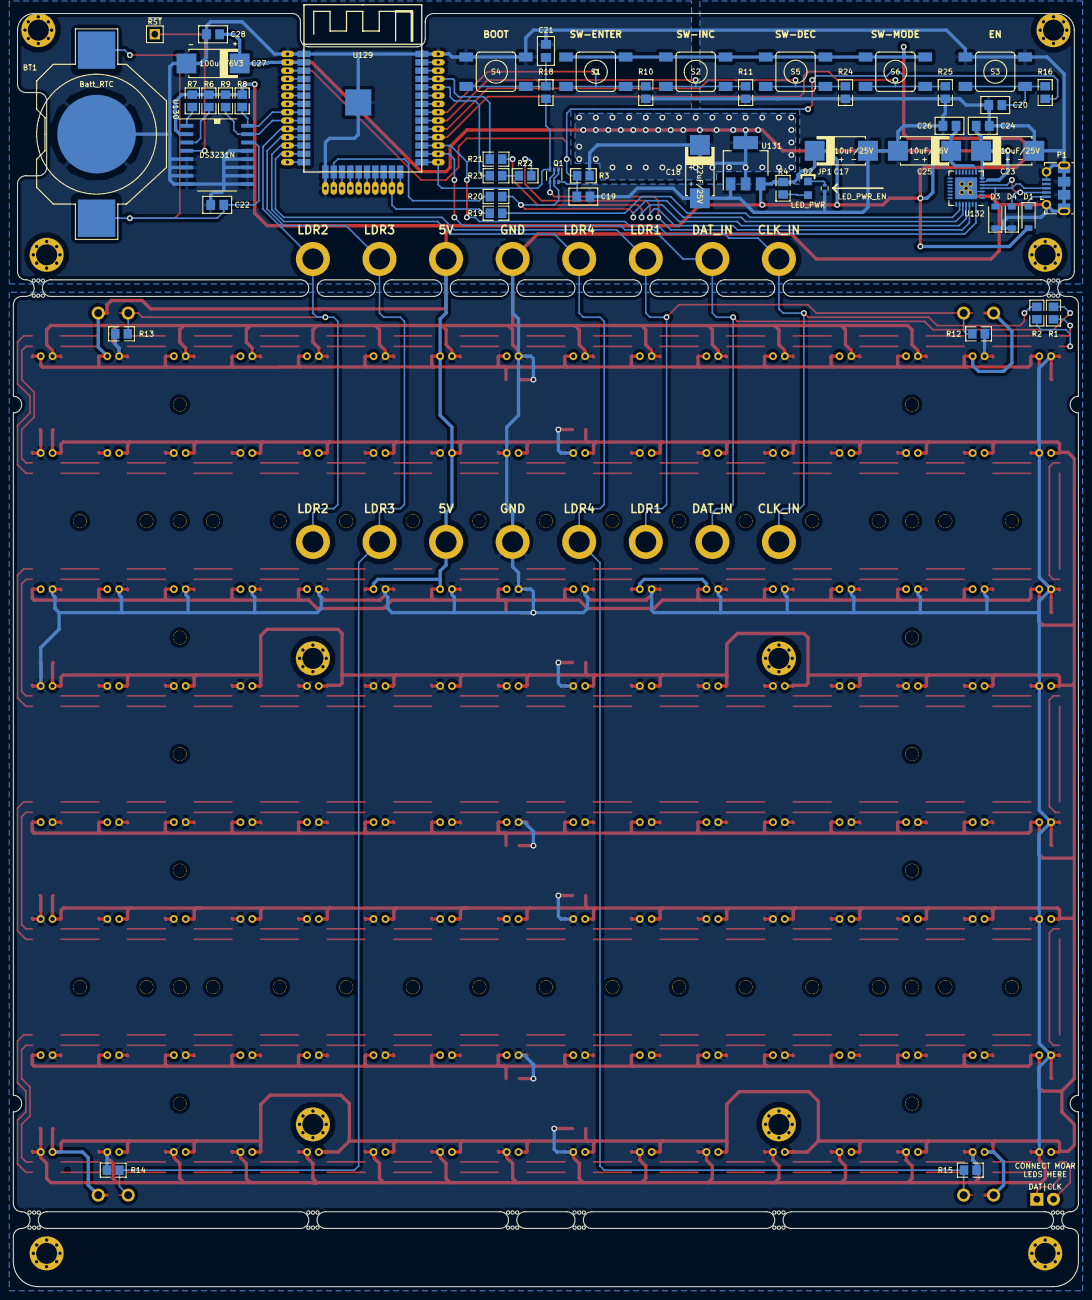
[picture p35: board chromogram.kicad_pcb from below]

Board: 2 copper layers, 162.6 x 194.3 mm, 281 parts (54 on the bottom side), 296 nets.

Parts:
BITE1, BITE2, BITE3, BITE4, BITE5, BITE6, BITE7, BITE8: Mouse_Bite; mouse-bite-2.54mm-slot
BT1: Batt_RTC; CR2032_SMD
C1, C2, C3, C4, C5, C6, C7, C8, C9, C10, C11, C12, C13, C14, C15, C16, C22, C24, C26: 100nF; c_0805
C17, C23, C25: 10uF/25V; c_2917
C18: 22uF/25V; c_2917
C19, C20, C21: 1nF; c_0805
C27: 100uF/6V3; c_2917
C28: 1uF/10V; c_0805
D1: 1N5819; D_SOD-123
D2: LED_PWR; LED-0805
D3, D4: VESD05A1B; D_SOD-123
HB1, HB2, HB3, HB4, HB5, HB6, HB7, HB8, HB9, HB10, HB11, HB12, HB13, HB14, HB15, HB16, HB17, HB18, HB19, HB20, HB21, HB22, HB23, HB24, HB25, HB26, HB27, HB28, HB29, HB30, HB31, HB32, HB33, HB34, HB35, HB36, HB37, HB38, HB39, HB40, HB41, HB42, HB43, HB44: hole_baffle; hole_baffle_2mm
HB45, HB46, HB47, HB48, HB49, HB50, HB51, HB52, HB53, HB54: hole_baffle; mtg_hole_3mm_vias_2
J1, J9: CLK_IN; 1pin
J2, J10: DAT_IN; 1pin
J3, J11: LDR1; 1pin
J4, J12: LDR2; 1pin
J5, J13: LDR3; 1pin
J6, J14: LDR4; 1pin
J7, J15: 5V; 1pin
J8, J16: GND; 1pin
JP1: LED_PWR_EN; R_0402
LDR1, LDR2, LDR3, LDR4: LDR; r_0805_ldr
P1: USB_micro; USB_Micro-B_Molex-105017-0001
P2: OUT_CLK_DAT; Pin_Header_Straight_1x02
Q1: DDC114TU; SOT-363_SC-70-6
R1, R2, R16, R18, R22: 470R; r_0805
R3: 10k; r_0805
R4: 2k; r_0805
R6, R7, R10, R11, R12, R13, R14, R15, R24, R25: 10K; r_0805
R8, R9: 4K7; r_0805
R19, R20: 0R NC; r_0805
R21, R23: 0R; r_0805
S1: SW-ENTER; SW_SMD
S2: SW-INC; SW_SMD
S3: EN; SW_SMD
S4: BOOT; SW_SMD
S5: SW-DEC; SW_SMD
S6: SW-MODE; SW_SMD
TP1: ~RST; BreakOutPad
U1, U2, U3, U4, U5, U6, U7, U8, U9, U10, U11, U12, U13, U14, U15, U16, U17, U18, U19, U20, U21, U22, U23, U24, U25, U26, U27, U28, U29, U30, U31, U32, U33, U34, U35, U36, U37, U38, U39, U40, U41, U42, U43, U44, U45, U46, U47, U48, U49, U50, U51, U52, U53, U54, U55, U56, U57, U58, U59, U60, U61, U62, U63, U64, U65, U66, U67, U68, U69, U70, U71, U72, U73, U74, U75, U76, U77, U78, U79, U80, U81, U82, U83, U84, U85, U86, U87, U88, U89, U90, U91, U92, U93, U94, U95, U96, U97, U98, U99, U100, U101, U102, U103, U104, U105, U106, U107, U108, U109, U110, U111, U112, U113, U114, U115, U116, U117, U118, U119, U120, U121, U122, U123, U124, U125, U126, U127, U128: APA102
U129: ESP-wroom-32; esp_wroom_32
U130: DS3231N; DS3231
U131: AP1117-15; SOT-223-3_TabPin2
U132: CP2102N-A01-GQFN28; QFN-28-1EP_5x5mm_Pitch0.5mm

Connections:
/3V3: C18.1, C23.1, C24.1, C27.1, C28.1, R3.1, U129.2, U131.2, U132.6, U132.7
/5V: C1.2, C2.2, C3.2, C4.2, C5.2, C6.2, C7.2, C8.2, C9.2, C10.2, C11.2, C12.2, C13.2, C14.2, C15.2, C16.2, C17.1, C25.1, C26.1, D1.2, J7.1, J15.1, LDR1.1, LDR2.1, LDR3.1, LDR4.1, R4.1, R6.1, R7.1, R8.1, R9.1, S1.1, S1.3, S2.1, S2.3, S5.1, S5.3, S6.1, S6.3, U1.4, U2.4, U3.4, U4.4, U5.4, U6.4, U7.4, U8.4, U9.4, U10.4, U11.4, U12.4, U13.4, U14.4, U15.4, U16.4, U17.4, U18.4, U19.4, U20.4, U21.4, U22.4, U23.4, U24.4, U25.4, U26.4, U27.4, U28.4, U29.4, U30.4, U31.4, U32.4, U33.4, U34.4, U35.4, U36.4, U37.4, U38.4, U39.4, U40.4, U41.4, U42.4, U43.4, U44.4, U45.4, U46.4, U47.4, U48.4, U49.4, U50.4, U51.4, U52.4, U53.4, U54.4, U55.4, U56.4, U57.4, U58.4, U59.4, U60.4, U61.4, U62.4, U63.4, U64.4, U65.4, U66.4, U67.4, U68.4, U69.4, U70.4, U71.4, U72.4, U73.4, U74.4, U75.4, U76.4, U77.4, U78.4, U79.4, U80.4, U81.4, U82.4, U83.4, U84.4, U85.4, U86.4, U87.4, U88.4, U89.4, U90.4, U91.4, U92.4, U93.4, U94.4, U95.4, U96.4, U97.4, U98.4, U99.4, U100.4, U101.4, U102.4, U103.4, U104.4, U105.4, U106.4, U107.4, U108.4, U109.4, U110.4, U111.4, U112.4, U113.4, U114.4, U115.4, U116.4, U117.4, U118.4, U119.4, U120.4, U121.4, U122.4, U123.4, U124.4, U125.4, U126.4, U127.4, U128.4, U130.2, U131.3, U132.8
/CI_A: R2.2, U1.2
/CI_B: U16.5, U17.2
/CI_C: U32.5, U33.2
/CI_D: U48.5, U49.2
/CI_E: U64.5, U65.2
/CI_F: U80.5, U81.2
/CI_G: U96.5, U97.2
/CI_H: U112.5, U113.2
/CLK_IN: J1.1, J9.1, R2.1, U129.27
/CLK_OUT: P2.2, U128.5
/DAT_IN: J2.1, J10.1, R1.1, U129.26
/DAT_OUT: P2.1, U128.6
/DI_A: R1.2, U1.1
/DI_B: U16.6, U17.1
/DI_C: U32.6, U33.1
/DI_D: U48.6, U49.1
/DI_E: U64.6, U65.1
/DI_F: U80.6, U81.1
/DI_G: U96.6, U97.1
/DI_H: U112.6, U113.1
/DTR: Q1.2, Q1.4, U132.28
/EN: C19.1, Q1.6, R3.2, R16.1, U129.3
/IO0: Q1.3, R18.1, U129.25
/IO13: R20.1, U129.16
/IO15: R19.1, U129.23
/LDR1: J3.1, J11.1, LDR1.2, R12.1, U129.13
/LDR2: J4.1, J12.1, LDR2.2, R13.1, U129.10
/LDR3: J5.1, J13.1, LDR3.2, R14.1, U129.11
/LDR4: J6.1, J14.1, LDR4.2, R15.1, U129.12
/RXD0: R23.1, U129.34
/SCL: R8.2, U129.8, U130.16
/SDA: R9.2, U129.9, U130.15
/SW_D: R24.1, S5.2, S5.4, U129.29
/SW_E: R10.1, S1.2, S1.4, U129.31
/SW_I: R11.1, S2.2, S2.4, U129.30
/SW_M: R25.1, S6.2, S6.4, U129.28
/TXD0: R21.1, U129.35
/esp_pwr_uart/CTS: R19.2, U132.23
/esp_pwr_uart/RTS: Q1.1, Q1.5, R20.2, U132.24
/esp_pwr_uart/RXD: R21.2, U132.25
/esp_pwr_uart/TXD: R22.1, R23.2
/esp_pwr_uart/USB_D+: D3.2, P1.3, U132.4
/esp_pwr_uart/USB_D-: D4.2, P1.2, U132.5
/rtc_ds3231/32kHz: R7.2, U130.1
/rtc_ds3231/BAT: BT1.1, C22.1, U130.14
/rtc_ds3231/RESET: TP1.1, U130.4
/rtc_ds3231/SQR: R6.2, U130.3
GND: BT1.2, C1.1, C2.1, C3.1, C4.1, C5.1, C6.1, C7.1, C8.1, C9.1, C10.1, C11.1, C12.1, C13.1, C14.1, C15.1, C16.1, C17.2, C18.2, C19.2, C20.2, C21.2, C22.2, C23.2, C24.2, C25.2, C26.2, C27.2, C28.2, D3.1, D4.1, J8.1, J16.1, JP1.1, P1.5, P1.6, R10.2, R11.2, R12.2, R13.2, R14.2, R15.2, R24.2, R25.2, S3.2, S3.4, S4.2, S4.4, U1.3, U2.3, U3.3, U4.3, U5.3, U6.3, U7.3, U8.3, U9.3, U10.3, U11.3, U12.3, U13.3, U14.3, U15.3, U16.3, U17.3, U18.3, U19.3, U20.3, U21.3, U22.3, U23.3, U24.3, U25.3, U26.3, U27.3, U28.3, U29.3, U30.3, U31.3, U32.3, U33.3, U34.3, U35.3, U36.3, U37.3, U38.3, U39.3, U40.3, U41.3, U42.3, U43.3, U44.3, U45.3, U46.3, U47.3, U48.3, U49.3, U50.3, U51.3, U52.3, U53.3, U54.3, U55.3, U56.3, U57.3, U58.3, U59.3, U60.3, U61.3, U62.3, U63.3, U64.3, U65.3, U66.3, U67.3, U68.3, U69.3, U70.3, U71.3, U72.3, U73.3, U74.3, U75.3, U76.3, U77.3, U78.3, U79.3, U80.3, U81.3, U82.3, U83.3, U84.3, U85.3, U86.3, U87.3, U88.3, U89.3, U90.3, U91.3, U92.3, U93.3, U94.3, U95.3, U96.3, U97.3, U98.3, U99.3, U100.3, U101.3, U102.3, U103.3, U104.3, U105.3, U106.3, U107.3, U108.3, U109.3, U110.3, U111.3, U112.3, U113.3, U114.3, U115.3, U116.3, U117.3, U118.3, U119.3, U120.3, U121.3, U122.3, U123.3, U124.3, U125.3, U126.3, U127.3, U128.3, U129.1, U129.15, U129.38, U129.39, U130.5, U130.6, U130.7, U130.8, U130.9, U130.10, U130.11, U130.12, U130.13, U131.1, U132.3, U132.29
unnamed: C20.1, R16.2, S3.1, S3.3
unnamed: C21.1, R18.2, S4.1, S4.3
unnamed: D1.1, P1.1
unnamed: D2.1, R4.2
unnamed: D2.2, JP1.2
unnamed: R22.2, U132.26
unnamed: U1.5, U2.2
unnamed: U1.6, U2.1
unnamed: U2.5, U3.2
unnamed: U2.6, U3.1
unnamed: U3.5, U4.2
unnamed: U3.6, U4.1
unnamed: U4.5, U5.2
unnamed: U4.6, U5.1
unnamed: U5.5, U6.2
unnamed: U5.6, U6.1
unnamed: U6.5, U7.2
unnamed: U6.6, U7.1
unnamed: U7.5, U8.2
unnamed: U7.6, U8.1
unnamed: U8.5, U9.2
unnamed: U8.6, U9.1
unnamed: U9.6, U10.1
unnamed: U9.5, U10.2
unnamed: U10.5, U11.2
unnamed: U10.6, U11.1
unnamed: U11.5, U12.2
unnamed: U11.6, U12.1
unnamed: U12.5, U13.2
unnamed: U12.6, U13.1
unnamed: U13.5, U14.2
unnamed: U13.6, U14.1
unnamed: U14.5, U15.2
unnamed: U14.6, U15.1
unnamed: U15.5, U16.2
unnamed: U15.6, U16.1
unnamed: U17.5, U18.2
unnamed: U17.6, U18.1
unnamed: U18.5, U19.2
unnamed: U18.6, U19.1
unnamed: U19.5, U20.2
unnamed: U19.6, U20.1
unnamed: U20.5, U21.2
unnamed: U20.6, U21.1
unnamed: U21.5, U22.2
unnamed: U21.6, U22.1
unnamed: U22.5, U23.2
unnamed: U22.6, U23.1
unnamed: U23.5, U24.2
unnamed: U23.6, U24.1
unnamed: U24.5, U25.2
unnamed: U24.6, U25.1
unnamed: U25.5, U26.2
unnamed: U25.6, U26.1
unnamed: U26.5, U27.2
unnamed: U26.6, U27.1
unnamed: U27.5, U28.2
unnamed: U27.6, U28.1
unnamed: U28.5, U29.2
unnamed: U28.6, U29.1
unnamed: U29.5, U30.2
unnamed: U29.6, U30.1
unnamed: U30.5, U31.2
unnamed: U30.6, U31.1
unnamed: U31.5, U32.2
unnamed: U31.6, U32.1
unnamed: U33.5, U34.2
unnamed: U33.6, U34.1
unnamed: U34.5, U35.2
unnamed: U34.6, U35.1
unnamed: U35.5, U36.2
unnamed: U35.6, U36.1
unnamed: U36.5, U37.2
unnamed: U36.6, U37.1
unnamed: U37.5, U38.2
unnamed: U37.6, U38.1
unnamed: U38.5, U39.2
unnamed: U38.6, U39.1
unnamed: U39.5, U40.2
unnamed: U39.6, U40.1
unnamed: U40.5, U41.2
unnamed: U40.6, U41.1
unnamed: U41.5, U42.2
unnamed: U41.6, U42.1
unnamed: U42.5, U43.2
unnamed: U42.6, U43.1
unnamed: U43.5, U44.2
unnamed: U43.6, U44.1
unnamed: U44.5, U45.2
unnamed: U44.6, U45.1
unnamed: U45.5, U46.2
unnamed: U45.6, U46.1
unnamed: U46.5, U47.2
unnamed: U46.6, U47.1
unnamed: U47.5, U48.2
unnamed: U47.6, U48.1
unnamed: U49.5, U50.2
unnamed: U49.6, U50.1
unnamed: U50.5, U51.2
unnamed: U50.6, U51.1
unnamed: U51.5, U52.2
unnamed: U51.6, U52.1
unnamed: U52.5, U53.2
unnamed: U52.6, U53.1
unnamed: U53.5, U54.2
unnamed: U53.6, U54.1
unnamed: U54.5, U55.2
unnamed: U54.6, U55.1
unnamed: U55.5, U56.2
unnamed: U55.6, U56.1
unnamed: U56.5, U57.2
unnamed: U56.6, U57.1
unnamed: U57.5, U58.2
unnamed: U57.6, U58.1
unnamed: U58.5, U59.2
unnamed: U58.6, U59.1
unnamed: U59.5, U60.2
unnamed: U59.6, U60.1
unnamed: U60.5, U61.2
unnamed: U60.6, U61.1
unnamed: U61.5, U62.2
unnamed: U61.6, U62.1
unnamed: U62.5, U63.2
unnamed: U62.6, U63.1
unnamed: U63.5, U64.2
unnamed: U63.6, U64.1
unnamed: U65.5, U66.2
unnamed: U65.6, U66.1
unnamed: U66.5, U67.2
unnamed: U66.6, U67.1
unnamed: U67.5, U68.2
unnamed: U67.6, U68.1
unnamed: U68.5, U69.2
unnamed: U68.6, U69.1
unnamed: U69.5, U70.2
unnamed: U69.6, U70.1
unnamed: U70.5, U71.2
unnamed: U70.6, U71.1
unnamed: U71.5, U72.2
unnamed: U71.6, U72.1
unnamed: U72.5, U73.2
unnamed: U72.6, U73.1
unnamed: U73.5, U74.2
unnamed: U73.6, U74.1
unnamed: U74.5, U75.2
unnamed: U74.6, U75.1
unnamed: U75.5, U76.2
unnamed: U75.6, U76.1
unnamed: U76.5, U77.2
unnamed: U76.6, U77.1
unnamed: U77.5, U78.2
unnamed: U77.6, U78.1
unnamed: U78.5, U79.2
unnamed: U78.6, U79.1
unnamed: U79.5, U80.2
unnamed: U79.6, U80.1
unnamed: U81.5, U82.2
unnamed: U81.6, U82.1
unnamed: U82.5, U83.2
unnamed: U82.6, U83.1
unnamed: U83.5, U84.2
unnamed: U83.6, U84.1
unnamed: U84.5, U85.2
unnamed: U84.6, U85.1
unnamed: U85.5, U86.2
unnamed: U85.6, U86.1
unnamed: U86.5, U87.2
unnamed: U86.6, U87.1
unnamed: U87.5, U88.2
unnamed: U87.6, U88.1
unnamed: U88.5, U89.2
unnamed: U88.6, U89.1
unnamed: U89.5, U90.2
unnamed: U89.6, U90.1
unnamed: U90.5, U91.2
unnamed: U90.6, U91.1
unnamed: U91.5, U92.2
unnamed: U91.6, U92.1
unnamed: U92.5, U93.2
unnamed: U92.6, U93.1
unnamed: U93.5, U94.2
unnamed: U93.6, U94.1
unnamed: U94.5, U95.2
unnamed: U94.6, U95.1
unnamed: U95.5, U96.2
unnamed: U95.6, U96.1
unnamed: U97.5, U98.2
unnamed: U97.6, U98.1
unnamed: U98.5, U99.2
unnamed: U98.6, U99.1
unnamed: U99.6, U100.1
unnamed: U99.5, U100.2
unnamed: U100.5, U101.2
unnamed: U100.6, U101.1
unnamed: U101.5, U102.2
unnamed: U101.6, U102.1
unnamed: U102.5, U103.2
unnamed: U102.6, U103.1
unnamed: U103.5, U104.2
unnamed: U103.6, U104.1
unnamed: U104.5, U105.2
unnamed: U104.6, U105.1
unnamed: U105.5, U106.2
unnamed: U105.6, U106.1
unnamed: U106.5, U107.2
unnamed: U106.6, U107.1
unnamed: U107.5, U108.2
unnamed: U107.6, U108.1
unnamed: U108.5, U109.2
unnamed: U108.6, U109.1
unnamed: U109.5, U110.2
unnamed: U109.6, U110.1
unnamed: U110.5, U111.2
unnamed: U110.6, U111.1
unnamed: U111.5, U112.2
unnamed: U111.6, U112.1
unnamed: U113.5, U114.2
unnamed: U113.6, U114.1
unnamed: U114.5, U115.2
unnamed: U114.6, U115.1
unnamed: U115.5, U116.2
unnamed: U115.6, U116.1
unnamed: U116.5, U117.2
unnamed: U116.6, U117.1
unnamed: U117.5, U118.2
unnamed: U117.6, U118.1
unnamed: U118.5, U119.2
unnamed: U118.6, U119.1
unnamed: U119.5, U120.2
unnamed: U119.6, U120.1
unnamed: U120.5, U121.2
unnamed: U120.6, U121.1
unnamed: U121.5, U122.2
unnamed: U121.6, U122.1
unnamed: U122.5, U123.2
unnamed: U122.6, U123.1
unnamed: U123.5, U124.2
unnamed: U123.6, U124.1
unnamed: U124.5, U125.2
unnamed: U124.6, U125.1
unnamed: U125.5, U126.2
unnamed: U125.6, U126.1
unnamed: U126.5, U127.2
unnamed: U126.6, U127.1
unnamed: U127.5, U128.2
unnamed: U127.6, U128.1

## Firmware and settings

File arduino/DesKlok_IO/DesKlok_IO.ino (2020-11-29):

#include <AdafruitIO_WiFi.h>
#include <EEPROM.h>
#include <EEPROMAnything.h>
#include "config.h"
#include <NTPClient.h>
#include <WiFiUdp.h>
#include <FastLED.h>
#include <WiFiClientSecure.h>
#include <credentials.h> //see arduino/libraries/credentials/README for a credentials.h template
#define ULTIM8x16
#include <MatrixMaps.h>

#define WIFI_MANAGER

WiFiClientSecure *client_p;

//#include "dutch_v1.h"
// #include "english_v0.h"
// #include "english_v2.h"
#include "english_v3.h"
// #include "english_v4.h"
// #include "french_v1.h"
// #include "german_v1.h"
// #include "german_v2.h"
// #include "german_v3.h"
// #include "german_v4.h"
// #include "german_v5.h"
// #include "hebrew_v1.h"
// #include "hungarian_v1.h"
// #include "hungarian_v2.h"
// #include "irish_v1.h"
// #include "spanish_v1.h"

// You can specify the time server pool and the offset (in seconds, can be
// changed later with setTimeOffset() ). Additionaly you can specify the
// update interval (in milliseconds, can be changed using setUpdateInterval() ).
WiFiUDP ntpUDP;

NTPClient timeClient(ntpUDP, "us.pool.ntp.org", 0, 60000);

struct config_t{
  int timezone;
  long alarm;
  int mode;
  uint8_t brightness;
  uint8_t display_idx;
} configuration;

uint32_t current_time;

typedef void (*Init)();
typedef void (*Background)();
typedef void (*Transition)(uint16_t last_time_inc, uint16_t time_inc);
void minutes_hack(uint8_t i, bool *out);
void get_time_display(bool* mask, int i);
void fill_red();
void fill_green();
void fill_blue();

typedef struct{
  Init       init;
  Background background;
  Transition transition;
  String     name;
  int        id;
} Display;

typedef Display Displays[];

void noop(){
}
void blend_to_rainbow();

Display WordDropDisplay = {blend_to_rainbow, rainbow, word_drop, String("Word Drop"), 0};
Display WipeAroundDisplay = {blend_to_rainbow, rainbow, wipe_around_transition, String("Wipe Around"), 1};
Display TheMatrixDisplay = {blend_to_blue, fill_blue, TheMatrix, String("The Matrix"), 2};

const int N_DISPLAY = 3;
Display *Display_ps[N_DISPLAY] = {&WordDropDisplay,
				  &WipeAroundDisplay,
				  &TheMatrixDisplay};
Display* CurrentDisplay_p = &WipeAroundDisplay;

void new_display(Display* Display_p){
  Display_p->init();
  CurrentDisplay_p = Display_p;
}

// language constants
uint8_t n_minute_led;               // number of minute hack leds
uint8_t n_minute_state;             // number of minute hack states to cycle through
uint8_t n_byte_per_display = 4;         // number of bytes used for each 5 minunte time incriment

uint8_t display_idx;
uint8_t last_min_hack_inc = 0;
uint16_t last_time_inc = 0;

/* The display memory buffer is larger than physical display for screen 
 * staging and fast display.
 */
const uint8_t MAX_BRIGHTNESS = 50;
const bool ON = true;
const bool OFF = false;

// How many leds are in the strip?
#define N_BOARD 2
#define NUM_LEDS 64 * N_BOARD
bool mask[NUM_LEDS];
bool wipe[NUM_LEDS];

//// LOLIN32
// Clock pin only needed for SPI based chipsets when not using hardware SPI
//#define CLK_PIN 12

#define DATA_PIN     13
#define CLK_PIN      14

#define COLOR_ORDER BGR
#define LED_TYPE APA102
#define MILLI_AMPS 1000  // IMPORTANT: set the max milli-Amps of your power supply (4A = 4000mA)

// This is an array of leds.  One item for each led in your strip.
CRGB leds[NUM_LEDS];
CRGB buffer[2 * NUM_LEDS];


void blend_to_rainbow(){
  int i;
  CHSV newcolor;
  int count = ((current_time % 300) * 255) / 300;
  
  newcolor.val = 255;
  newcolor.sat = 255;
  for(int ii=0; ii<NUM_LEDS; ii++){
    for( int row = 0; row < MatrixHeight; row++) {
      for( int col = 0; col < MatrixWidth; col++) {
	i = XY(col, row);
	if(mask[i]){
	  newcolor.hue =  (count + (MatrixWidth * row + col) * 2) % 256;
	  nblend(leds[XY(col, row)], newcolor, 1);
	}
      }
    }
    FastLED.show();
    delay(1);
  }
}

void blend_to_color(CRGB color){
  for(int kk=0; kk<128; kk++){
    for(int ii=0; ii<NUM_LEDS; ii++){
      if(mask[ii]){
	nblend(leds[ii], color, 1);
      }
    }
    FastLED.show();
    delay(1);
  }
}

void blend_to_red(){
  blend_to_color(CRGB::Red);
}

void blend_to_green(){
  blend_to_color(CRGB::Green);
}

void blend_to_blue(){
  blend_to_color(CRGB::Blue);
}

void fill_red(){
  fill_solid(leds, NUM_LEDS, CRGB::Red);
}
void fill_green(){
  fill_solid(leds, NUM_LEDS, CRGB::Green);
}
void fill_blue(){
  fill_solid(leds, NUM_LEDS, CRGB::Blue);
}

void printTime(uint32_t tm){
  uint8_t hh, mm, ss;
  char s[8];
  
  hh = (tm % 86400 / 3600) % 24;
  mm = (tm % 86400 / 60) % 60;
  ss = (tm % 86400) % 60;
  
  sprintf(s, "%02d:%02d:%02d", hh, mm, ss);
  Serial.println(s);
}

void handleTimeSeconds(uint32_t tm){
  current_time = tm;
  printTime(current_time);
}

void setup(){
  Serial.begin(115200);
  delay(200);

  FastLED.addLeds<LED_TYPE, DATA_PIN, CLK_PIN, COLOR_ORDER>(leds, NUM_LEDS);
  FastLED.setDither(true);
  FastLED.setCorrection(TypicalLEDStrip);
  FastLED.setMaxPowerInVoltsAndMilliamps(5, MILLI_AMPS);
  fill_solid(leds, NUM_LEDS, CRGB::Black);
  FastLED.show();


#ifndef CONNECT_TO_ADA_IO  
  io.connect();
  Serial.print("Wait for IO connect.");
  while(io.status() < AIO_CONNECTED) {
    Serial.print(".");
    delay(500);
  }
  Serial.println(io.statusText());Serial.println("Connected to IO");
#endif
  timezone->onMessage(handleTimezone);
  brightness->onMessage(handleBrightness);
  display_idx_io->onMessage(handleDisplayIdx);
  EEPROM.begin(512);
  loadSettings();
  new_display(Display_ps[configuration.display_idx % N_DISPLAY]);
  
  FastLED.setBrightness(configuration.brightness);
  
  timeClient.setTimeOffset(configuration.timezone * 60);
  timeClient.begin();
  CurrentDisplay_p->init();
}

void loadSettings(){
  EEPROM_readAnything(0, configuration);  
}

void saveSettings(){
  EEPROM_writeAnything(0, configuration);
  EEPROM.commit();
}

void handleTimezone(AdafruitIO_Data *message){
  char *data = (char*)message->value();
  int dataLen = strlen(data);
  if (dataLen >= 0) {
    String dataStr = String(data);
    int new_timezone = (int)dataStr.toInt();
    if (new_timezone != configuration.timezone && -1440/2 < new_timezone && new_timezone <= 1440/2){
      configuration.timezone = new_timezone;
      timeClient.setTimeOffset(configuration.timezone * 60);
      saveSettings();
    }
  }  

  // print out the received value
  Serial.print(message->feedName());
  Serial.print(" ");
  Serial.println(message->value());
}

void handleBrightness(AdafruitIO_Data *message){
  char *data = (char*)message->value();

  int dataLen = strlen(data);
  if (dataLen > 0) {
    String dataStr = String(data);
    int new_brightness = (int)dataStr.toInt();
    if ((new_brightness != configuration.brightness) && (0 <= new_brightness) && (new_brightness <= MAX_BRIGHTNESS)){
      configuration.brightness = new_brightness;
      FastLED.setBrightness(configuration.brightness);
      saveSettings();
    }
  }
  // print out the received value
  Serial.print(message->feedName());
  Serial.print(" ");
  Serial.println(message->value());
}

void handleDisplayIdx(AdafruitIO_Data *message){
  char *data = (char*)message->value();

  int dataLen = strlen(data);
  if (dataLen > 0) {
    String dataStr = String(data);
    int new_idx = (int)dataStr.toInt() % N_DISPLAY;
    if ((new_idx != configuration.display_idx) && (0 <= new_idx) && (new_idx <= MAX_BRIGHTNESS)){
      configuration.display_idx = new_idx;
      new_display(Display_ps[new_idx]);
      saveSettings();
    }
  }
  // print out the received value
  Serial.print(message->feedName());
  Serial.print(" ");
  Serial.println(message->value());
}

const struct CRGB color = CRGB::White;

uint16_t XY( uint8_t x, uint8_t y)
{
  if(FLIP_DISPLAY){
    x = MatrixWidth - x - 1;
    y = MatrixHeight - y - 1;
  }
  uint16_t out = 0;
  if(x < MatrixWidth && y < MatrixHeight){
    out = MatrixMap[y][x];
  }
  return out;
}

typedef void (*Pattern)();
typedef Pattern PatternList[];
typedef struct {
  Pattern pattern;
  String name;
} PatternAndName;
typedef PatternAndName PatternAndNameList[];

// Pride2015 by Mark Kriegsman: https://gist.github.com/kriegsman/964de772d64c502760e5
// This function draws rainbows with an ever-changing,
// widely-varying set of parameters.
void pride()
{
  static uint16_t sPseudotime = 0;
  static uint16_t sLastMillis = 0;
  static uint16_t sHue16 = 0;

  uint8_t sat8 = beatsin88( 87, 220, 250);
  uint8_t brightdepth = beatsin88( 341, 96, 224);
  uint16_t brightnessthetainc16 = beatsin88( 203, (25 * 256), (40 * 256));
  uint8_t msmultiplier = beatsin88(147, 23, 60);

  uint16_t hue16 = sHue16;//gHue * 256;
  uint16_t hueinc16 = beatsin88(113, 1, 3000);

  uint16_t ms = millis();
  uint16_t deltams = ms - sLastMillis ;
  sLastMillis  = ms;
  sPseudotime += deltams * msmultiplier;
  sHue16 += deltams * beatsin88( 400, 5, 9);
  uint16_t brightnesstheta16 = sPseudotime;

  for ( uint16_t i = 0 ; i < NUM_LEDS; i++) {
    hue16 += hueinc16;
    uint8_t hue8 = hue16 / 256;

    brightnesstheta16  += brightnessthetainc16;
    uint16_t b16 = sin16( brightnesstheta16  ) + 32768;

    uint16_t bri16 = (uint32_t)((uint32_t)b16 * (uint32_t)b16) / 65536;
    uint8_t bri8 = (uint32_t)(((uint32_t)bri16) * brightdepth) / 65536;
    bri8 += (255 - brightdepth);

    CRGB newcolor = CHSV( hue8, sat8, bri8);

    uint16_t pixelnumber = i;
    pixelnumber = (NUM_LEDS - 1) - pixelnumber;

    nblend( leds[pixelnumber], newcolor, 64);
  }
}

void pride2()
{
  static uint16_t sPseudotime = 0;
  static uint16_t sLastMillis = 0;
  static uint16_t sHue16 = 0;

  uint8_t sat8 = beatsin88( 87, 220, 250);
  uint8_t brightdepth = beatsin88( 341, 96, 224);
  uint16_t brightnessthetainc16 = beatsin88( 203, (25 * 256), (40 * 256));
  uint8_t msmultiplier = beatsin88(147, 23, 60);

  uint16_t hue16 = sHue16;//gHue * 256;
  uint16_t hueinc16 = beatsin88(113, 1, 3000);

  uint16_t ms = millis();
  uint16_t deltams = ms - sLastMillis ;
  sLastMillis  = ms;
  sPseudotime += deltams * msmultiplier;
  sHue16 += deltams * beatsin88( 400, 5, 9);
  uint16_t brightnesstheta16 = sPseudotime;

  for (uint8_t x = 0; x < MatrixWidth; x++) {
    hue16 += hueinc16;
    uint8_t hue8 = hue16 / 256;

    brightnesstheta16  += brightnessthetainc16;
    uint16_t b16 = sin16( brightnesstheta16  ) + 32768;

    uint16_t bri16 = (uint32_t)((uint32_t)b16 * (uint32_t)b16) / 65536;
    uint8_t bri8 = (uint32_t)(((uint32_t)bri16) * brightdepth) / 65536;
    bri8 += (255 - brightdepth);

    CRGB newcolor = CHSV( hue8, sat8, bri8);

    for (uint8_t y = 0; y < MatrixHeight; y++) {
      nblend(leds[XY(x, y)], newcolor, 64);
    }
  }
}

PatternAndNameList patterns = {
  { pride,                  "Pride" },
  { pride2,                 "Pride 2" }
};

void rainbow() {
  int i, dx, dy;
  CHSV hsv;
  float dist;
  
  hsv.hue = 0;
  hsv.val = 255;
  hsv.sat = 240;
  int count = ((current_time % 300) * 255) / 300;
  for( int row = 0; row < MatrixHeight; row++) {
    for( int col = 0; col < MatrixWidth; col++) {
      dy = (row - 4) * 2;
      dx = col - 8;
      dist = sqrt(dx * dx + dy * dy);
      i = XY(col, row);
      //hsv.hue =  ((int)(dist * 16) - count) % 256;
      hsv.hue =  (count + (MatrixWidth * row + col) * 2) % 256;
      leds[i] = hsv;
    }
  }
  // Show the leds (only one of which is set to white, from above)
  //delay(100);
}

void fillMask(bool* mask, bool b){
  fillMask(mask, b, 0, NUM_LEDS);
}

void fillMask(bool* mask, bool b, int start, int stop){
  for(int i = start; i < stop && i < NUM_LEDS; i++){
    mask[i] = b;
  }
}
void setPixelMask(bool* mask, uint8_t row, uint8_t col, bool b){
  if(row >= MatrixHeight){
  }
  else if(col >= MatrixWidth){
  }
  else{
    uint16_t pos = XY(col, row);
    if(pos < NUM_LEDS){
      mask[pos] = b;
    }
  }
}

void setWordMask(bool *mask, uint8_t* word, bool b){
  // word = [row, col, len]
  for(int i=0; i < word[2]; i++){
    setPixelMask(mask, word[1], word[0] + i, b);
  }
}

void logical_and(int n, bool* mask, bool* wipe, bool* out){
  int i;
  for(i = 0; i < n; i++){
    out[i] = mask[i] && wipe[i];
  }
}

void logical_or(int n, bool* mask, bool* wipe, bool* out){
  int i;
  for(i = 0; i < n; i++){
    out[i] = mask[i] || wipe[i];
  }
}

void logical_copy(int n, bool* mask, bool* out){
  int i;
  for(i = 0; i < n; i++){
    out[i] = mask[i];
  }
}
  
void logical_not(int n, bool* mask, bool* out){
  int i;
  for(i = 0; i < n; i++){
    out[i] = !mask[i];
  }
}

bool logical_equal(int n, bool* mask, bool* wipe){
  bool out;
  int i = 0;
  while(i < n && mask[i] == wipe[i]){
    i++;
  }
  return i == n;
}
bool all_true(int n, bool* mask){
  int i = 0;
  
  while(i < n && mask[i]){
    i++;
  }
  return i == n;
}

bool any_false(int n, bool* mask){
  return !all_true(n, mask);
}

bool all_false(int n, bool* mask){
  int i = 0;
  
  while(i < n && !mask[i]){
    i++;
  }
  return i == n;
}

bool any_true(int n, bool* mask){
  return !all_false(n, mask);
}


void apply_mask(bool* mask){
  uint16_t b, k;
  for(uint16_t i=0; i < NUM_LEDS; i++){
    if(!mask[i]){
      leds[i] = CRGB::Black;
    }
  }
}

const int32_t UPDATE_INTERVAL_MS = 1000;
int32_t last_update_ms= 0;
const int32_t UPDATE_IO_MS = 5000;
int32_t last_io_update_ms= 0;

void loop(){
  desk_clock();
}

void word_drop_in(uint16_t time_inc){
  uint8_t bits;     // holds the on off state for 8 words at a time
  uint8_t word[3];  // start columm, start row, length of the current word
  bool tmp_mask[NUM_LEDS];
  uint8_t tmp_word[3];
  
  fillMask(mask, false);
  fillMask(wipe, false);
  fillMask(tmp_mask, false);
  
  for(uint8_t j = 0; j < n_byte_per_display; j++){ // j is a byte index 
    // read the state for the next set of 8 words
    bits = pgm_read_byte(DISPLAYS + 1 + (time_inc * n_byte_per_display) + j);
    for(uint8_t k = 0; k < 8; k++){                     // k is a bit index
      if((bits >> k) & 1){                              // check to see if word is on or off
	getword(j * 8 + k, word);                       // if on, read location and length
	tmp_word[0] = word[0];
	tmp_word[1] = word[1];
	tmp_word[2] = word[2];
	for(int rr = 0; rr <= word[1]; rr++){
	  tmp_word[1] = rr;
	  setWordMask(wipe, tmp_word, true);
	  logical_or(NUM_LEDS, mask, wipe, tmp_mask);
	  rainbow();
	  apply_mask(tmp_mask);
	  FastLED.show();
	  delay(25);
	}
	setWordMask(mask, word, true);
	for(int rr = 0; rr < word[1]; rr++){
	  tmp_word[1] = rr;
	  setWordMask(wipe, tmp_word, false);
	  logical_or(NUM_LEDS, mask, wipe, tmp_mask);
	  
	  rainbow();
	  apply_mask(tmp_mask);
	  FastLED.show();
	  delay(25);
	}
      }
    }
  }
}
void word_drop_out(uint16_t time_inc){
  uint8_t bits;     // holds the on off state for 8 words at a time
  uint8_t word[3];  // start columm, start row, length of the current word
  bool tmp_mask[NUM_LEDS];
  uint8_t tmp_word[3];
  
  //fillMask(mask, false);
  //fillMask(wipe, false);
  //fillMask(tmp_mask, false);
  logical_copy(NUM_LEDS, mask, wipe);
  logical_copy(NUM_LEDS, mask, tmp_mask);
  
  for(uint8_t j = 0; j < n_byte_per_display; j++){ // j is a byte index 
    // read the state for the next set of 8 words
    bits = pgm_read_byte(DISPLAYS + 1 + (time_inc * n_byte_per_display) + j);
    for(uint8_t k = 0; k < 8; k++){                     // k is a bit index
      if((bits >> k) & 1){                              // check to see if word is on or off
	getword(j * 8 + k, word);                       // if on, read location and length
	tmp_word[0] = word[0];
	tmp_word[1] = word[1];
	tmp_word[2] = word[2];
	for(int rr = word[1]; rr <= 8; rr++){
	  tmp_word[1] = rr;
	  setWordMask(wipe, tmp_word, true);
	  logical_or(NUM_LEDS, mask, wipe, tmp_mask);
	  rainbow();
	  apply_mask(tmp_mask);
	  FastLED.show();
	  delay(25);
	}
	setWordMask(mask, word, false);
	for(int rr = word[1]; rr <= 8; rr++){
	  tmp_word[1] = rr;
	  setWordMask(wipe, tmp_word, false);
	  logical_or(NUM_LEDS, mask, wipe, tmp_mask);
	  
	  rainbow();
	  apply_mask(tmp_mask);
	  FastLED.show();
	  delay(25);
	}
      }
    }
  }
}

void word_drop(uint16_t last_time_inc, uint16_t time_inc){
  bool tmp_d[NUM_LEDS];

  rainbow();

  // swipe rainbow from the left
  //wipe_around(ON);
  //delay(1000);
  if(last_time_inc != 289){
    word_drop_out(last_time_inc);
  }
  
  // clear the new display
  fillMask(tmp_d, false);
  
  // read display for next time incement
  get_time_display(mask, time_inc);
  
  // clear rainbow to reveal the time
  //wipe_off_left();
  //wipe_around(OFF);
  word_drop_in(time_inc);
}

void fade_transition(uint16_t time_inc, uint16_t last_time_inc){
  int i, j;
  
  fillMask(mask, false);
  get_time_display(mask, last_time_inc);
  rainbow();
  apply_mask(mask); // fill leds with next time inc and copy to second half of buffer
  for(j = 0; j < NUM_LEDS; j++){
    buffer[j] = leds[j]; // buffer has new time
  }

  fillMask(mask, false);
  get_time_display(mask, time_inc); // leds have old time
  rainbow();
  apply_mask(mask);

  int rate = 1;
  for(j = 0; j < 255; j++){
    for(i=0; i < NUM_LEDS; i++){
      leds[i].red   = blend8(leds[i].red,   buffer[i].red, rate);
      leds[i].green = blend8(leds[i].green, buffer[i].green, rate);
      leds[i].blue  = blend8(leds[i].blue,  buffer[i].blue, rate);
    }
    FastLED.show();
    delay(1);
  }
}

void TheMatrix(uint16_t last_time_inc, uint16_t time_inc){
  int n_drop = 0;
  int n_need = 8;
  
  const struct CRGB color = CRGB::Green;
  uint8_t cols[NUM_LEDS];
  uint8_t rows[NUM_LEDS];
  uint8_t pause[NUM_LEDS];
  bool have[NUM_LEDS];
  int col;
  int i, j;

  // rainbow();
  fillMask(mask, false);
  fillMask(wipe, false);
  fillMask(have, false);
  get_time_display(mask, last_time_inc);
  get_time_display(wipe, time_inc);
  apply_mask(mask);
  FastLED.show();
  for(i=0; i < MatrixWidth; i++){
    for(j=0; j < MatrixHeight; j++){
      if(leds[XY(i, j)].red > 0 ||
	 leds[XY(i, j)].green > 0 ||
	 leds[XY(i, j)].blue > 0){
	rows[n_drop] = j;
	cols[n_drop] = i;
	n_drop++;
      }
      if(wipe[XY(i, j)]){
	n_need++;
      }
    }
  }
  
  delay(10);
  for(j = 0; j < 255 * 3; j++){
    for(i=0; i < NUM_LEDS; i++){
      leds[i].red   = blend8(leds[i].red, 0, 1);
      leds[i].green = blend8(leds[i].green, 255, 1);
      leds[i].blue  = blend8(leds[i].blue, 0, 1);
    }
    apply_mask(mask);
    FastLED.show();
    delay(5);
  }

  for(i = n_drop; i < n_need; i++){/// add enough drops to complete
    cols[i] = random(0, MatrixWidth);
    rows[i] = -random(0, MatrixHeight);
    n_drop++;
  }

  int end = millis() + 5000; // go for 5 seconds
  // while new display is not filled out
  while(!logical_equal(NUM_LEDS, wipe, have)){
      //  while(millis() < end){
    fadeToBlackBy(leds, NUM_LEDS, 75);
    for(i = 0; i < n_drop; i++){
      if(millis() > end && wipe[XY(cols[i], rows[i])]){
	if(random(0, 3) == 0){
	  have[XY(cols[i], rows[i])] = true;
	}
      }
      
      if(random(0, 16) == 0){ // pause at random times
	pause[i] = random(6, 9); // for random duration
      }
      if(pause[i] == 0){
	rows[i]++;
      }
      else{
	pause[i]--; 
      }
      if(rows[i] > MatrixHeight - 1){
	if(n_drop > n_need){
	  for(j = i; j < n_drop; j++){ // slide drops down by one
	    rows[j] = rows[j + 1];
	    cols[j] = cols[j + 1];
	  }
	  n_drop--;
	  Serial.print("n_drop:");
	  Serial.println(n_drop);
	}
	else{
	  rows[i] = -random(0, MatrixHeight);
	  cols[i] = random(0, MatrixWidth);
	}
      }
      if(0 <= rows[i] && rows[i] <  MatrixHeight){
	leds[XY(cols[i], rows[i])] = color;
      }
    }

    for(int ii = 0; ii < NUM_LEDS; ii++){
      if(have[ii]){
	leds[ii] = CRGB::Blue;
      }
    }
    FastLED.show();
    delay(75);
  }
  for(int ii=0; ii< MatrixHeight * 10; ii++){
      //  while(millis() < end){
    fadeToBlackBy(leds, NUM_LEDS, 75);
    for(i = 0; i < n_drop; i++){
      rows[i]++;
      if(0 <= rows[i] && rows[i] <  MatrixHeight){
	leds[XY(cols[i], rows[i])] = color;
      }
    }
    for(int ii = 0; ii < NUM_LEDS; ii++){
      if(have[ii]){
	leds[ii] = CRGB::Blue;
      }
    }
    FastLED.show();
    delay(75);
  }

  // fade to green
  delay(1000);
  
  
  
}

void wipe_around(bool val){
  float dtheta = 31.4 / 180;
  float theta = -3.14 - dtheta;
  int row, col;
  bool tmp[NUM_LEDS];

  int cx = random(0, MatrixWidth-1);
  int cy = random(0, MatrixHeight-1);
  cx = 8;
  cy = 4;
  
  fillMask(wipe, !val);
  while (theta < 3.14 + dtheta){
    for(row=0; row < MatrixHeight; row++){
      for(col=0; col < MatrixWidth; col++){
	if(atan2(row - cy, col - cx) < theta){
	  setPixelMask(wipe, row, col, val);
	}
      }
    }
    logical_or(NUM_LEDS, wipe, mask, tmp);    
    rainbow();
    apply_mask(tmp);
    FastLED.show();
    theta += dtheta;
  }
}

void wipe_around_transition(uint16_t last_time_inc, uint16_t time_inc){
  rainbow();
  fillMask(mask, false);
  get_time_display(mask, last_time_inc);
  apply_mask(mask);
  wipe_around(ON);
  delay(10);

  fillMask(mask, false);
  get_time_display(mask, time_inc);
  apply_mask(mask);
  wipe_around(OFF);
  delay(10);
}
void wipe_down(bool val){
  int col, row;
  bool tmp[NUM_LEDS];
  
  fillMask(wipe, !val);
  for(row=0; row < MatrixHeight; row++){
    for(col = MatrixWidth - 1; col >= 0; col--){
      setPixelMask(wipe, row, col, val);
    }
    logical_or(NUM_LEDS, wipe, mask, tmp);
    rainbow();
    apply_mask(tmp);
    FastLED.show();
    delay(20);
  }
}

void wipe_up(bool val){
  int col, row;
  bool tmp[NUM_LEDS];
  
  fillMask(wipe, !val);
  for(row = MatrixHeight - 1; row >= 0; row--){
    for(col = MatrixWidth - 1; col >= 0; col--){
      setPixelMask(wipe, row, col, val);
    }
    logical_or(NUM_LEDS, wipe, mask, tmp);
    rainbow();
    apply_mask(tmp);
    FastLED.show();
    delay(20);
  }
}
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

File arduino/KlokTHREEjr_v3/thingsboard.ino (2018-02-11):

#include <ArduinoJson.h>
#include <PubSubClient.h>
#include <ESP8266WiFi.h>
#include <WiFiManager.h>         //https://github.com/tzapu/WiFiManager
#include <credentials.h>

#define TOKEN "5vOhJJYU2rGTDiJJ5FME"

#define GPIO0 0
#define GPIO2 2

#define GPIO0_PIN 3
#define GPIO2_PIN 5

char thingsboardServer[] = "demo.thingsboard.io";

WiFiClient wifiClient;

PubSubClient client(wifiClient);

int status = WL_IDLE_STATUS;

// We assume that all GPIOs are LOW
boolean gpioState[] = {false, false};

void thingsboard_setup() {
  // Set output mode for all GPIO pins
  pinMode(GPIO0, OUTPUT);
  pinMode(GPIO2, OUTPUT);
  delay(10);
  InitWiFi();
  client.setServer( thingsboardServer, 1883 );
  client.setCallback(on_message);

}

void thingsboard_loop() {
  if ( !client.connected() ) {
    reconnect();
  }

  client.loop();
}

// The callback for when a PUBLISH message is received from the server.
void on_message(const char* topic, byte* payload, unsigned int length) {

  Serial.println("On message");

  char json[length + 1];
  strncpy (json, (char*)payload, length);
  json[length] = '\0';

  Serial.print("Topic: ");
  Serial.println(topic);
  Serial.print("Message: ");
  Serial.println(json);

  // Decode JSON request
  StaticJsonBuffer<200> jsonBuffer;
  JsonObject& data = jsonBuffer.parseObject((char*)json);

  if (!data.success())
  {
    Serial.println("parseObject() failed");
    return;
  }

  // Check request method
  String methodName = String((const char*)data["method"]);

  if (methodName.equals("getGpioStatus")) {
    // Reply with GPIO status
    String responseTopic = String(topic);
    responseTopic.replace("request", "response");
    client.publish(responseTopic.c_str(), get_gpio_status().c_str());
  } else if (methodName.equals("setGpioStatus")) {
    // Update GPIO status and reply
    set_gpio_status(data["params"]["pin"], data["params"]["enabled"]);
    String responseTopic = String(topic);
    responseTopic.replace("request", "response");
    client.publish(responseTopic.c_str(), get_gpio_status().c_str());
    client.publish("v1/devices/me/attributes", get_gpio_status().c_str());
  }
}

String get_gpio_status() {
  // Prepare gpios JSON payload string
  StaticJsonBuffer<200> jsonBuffer;
  JsonObject& data = jsonBuffer.createObject();
  data[String(GPIO0_PIN)] = gpioState[0] ? true : false;
  data[String(GPIO2_PIN)] = gpioState[1] ? true : false;
  char payload[256];
  data.printTo(payload, sizeof(payload));
  String strPayload = String(payload);
  Serial.print("Get gpio status: ");
  Serial.println(strPayload);
  return strPayload;
}

void set_gpio_status(int pin, boolean enabled) {
  if (pin == GPIO0_PIN) {
    // Output GPIOs state
    digitalWrite(GPIO0, enabled ? HIGH : LOW);
    // Update GPIOs state
    gpioState[0] = enabled;
  } else if (pin == GPIO2_PIN) {
    // Output GPIOs state
    digitalWrite(GPIO2, enabled ? HIGH : LOW);
    // Update GPIOs state
    gpioState[1] = enabled;
  }
}

int tb_get_idx(){
  return gpioState[0] + gpioState[1] * 2;
}

void InitWiFi_orig() {
  Serial.println("Connecting to AP ...");
  // attempt to connect to WiFi network

  WiFi.begin(ssid, pass);
  while (WiFi.status() != WL_CONNECTED) {
    delay(500);
    Serial.print(".");
  }
  Serial.println("Connected to AP");


}
void InitWiFi() {
  WiFiManager wifiManager;
  //wifiManager.resetSettings();// uncomment to forget previous wifi manager settings
  
  wifiManager.autoConnect("KLOK");
  Serial.println("yay connected");
}


void reconnect() {
  // Loop until we're reconnected
  while (!client.connected()) {
    status = WiFi.status();
    if ( status != WL_CONNECTED) {
      WiFi.begin(ssid, pass);
      while (WiFi.status() != WL_CONNECTED) {
        delay(500);
        Serial.print(".");
      }
      Serial.println("Connected to AP");
    }
    Serial.print("Connecting to ThingsBoard node ...");
    // Attempt to connect (clientId, username, password)
    if ( client.connect("ESP8266Client", TOKEN, NULL) ) {
      Serial.println( "[DONE]" );
      // Subscribing to receive RPC requests
      client.subscribe("v1/devices/me/rpc/request/+");
      // Sending current GPIO status
      Serial.println("Sending current GPIO status ...");
      client.publish("v1/devices/me/attributes", get_gpio_status().c_str());
    } else {
      Serial.print( "[FAILED] [ rc = " );
      Serial.print( client.state() );
      Serial.println( " : retrying in 5 seconds]" );
      // Wait 5 seconds before retrying
      delay( 5000 );
    }
  }
}

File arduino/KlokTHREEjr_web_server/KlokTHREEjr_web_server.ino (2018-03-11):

#include <FastLED.h>
#include <WiFiManager.h>
#include <EEPROMAnything.h>
#define ULTIM8x16
#include <MatrixMaps.h>
#include <credentials.h>

#include "textures.h"
#include "logic.h"
#include "Faceplate.h"
#include "clock.h"

#include "dutch_v1.h"
#include "french_v1.h"
#include "german_v3.h"
#include "hebrew_v1.h"
#include "hungarian_v2.h"
#include "irish_v1.h"
#include "italian_v1.h"
#include "english_v3.h"
#include "spanish_v1.h"

#include "config.h"


//const bool ON = true;
//const bool OFF = !ON;

// How many leds are in the strip?
const uint8_t N_BOARD = 2;
const uint8_t NUM_LEDS = 64 * N_BOARD;
bool mask[NUM_LEDS];
bool wipe[NUM_LEDS];
CRGB leds[NUM_LEDS];

#define DATA_PIN     13
#define CLK_PIN      14
#define COLOR_ORDER BGR
#define LED_TYPE APA102
#define MILLI_AMPS 1000  // IMPORTANT: set the max milli-Amps of your power supply (4A = 4000mA)

uint8_t logo_rgb[] = {
  0x11,0x00,0x29,0x00,0x25,0x00,0x23,0x00,0x25,0x00,0x29,0x00,0x31,0x00,0xe0,0x01,
  0x00,0x03,0x80,0x04,0x80,0x04,0x80,0x04,0x80,0x04,0x00,0x03,0x00,0x00,0x00,0x00,
  0x11,0x00,0x09,0x88,0x05,0x48,0x03,0x28,0x05,0x18,0x09,0x28,0x11,0x48,0x00,0x88
};

Faceplate faceplates[] = {
  english_v3,
  spanish_v1
};
uint8_t num_faceplates = 2;

struct config_t{
  int timezone;
  long alarm;
  int mode;
  uint8_t brightness;
  uint8_t display_idx;
} configuration;

void display_bitmap_rgb(uint8_t* bitmap){
  uint8_t n = 16;
  uint8_t h = 8;
  uint8_t w = 16;
  uint8_t xy[2];
  uint8_t r, g, b;
  
  int i, j;
  int led_idx, byte_idx;

  //struct CRGB color;
  int x, y;
  
  for(i=0; i<n; i++){
    r = bitmap[i + 0 * w];
    g = bitmap[i + 1 * w];
    b = bitmap[i + 2 * w];
    //   012345678pabcdef
    // 0 0000000011111111
    // 1 2222222233333333
    // 2 4444444455555555
    // 3 6666666677777777
    // 4 8888888899999999
    // 5 aaaaaaaabbbbbbbb
    // 6 ccccccccdddddddd
    // 7 eeeeeeeeffffffff
    for(j=0; j<8; j++){
      x = (i * 8 + j) % 16;
      y = i / 2;
      led_idx = XY(x, y);
      leds[led_idx].red   = 255 * ((r >> j) & 1);
      leds[led_idx].green = 255 * ((g >> j) & 1);
      leds[led_idx].blue  = 255 * ((b >> j) & 1);
      if(leds[led_idx].red || leds[led_idx].green || leds[led_idx].blue){
	mask[led_idx] = true;
      }
    }
  }
}

void apply_mask(bool* mask){
  uint16_t b, k;
  for(uint16_t i=0; i < NUM_LEDS; i++){
    if(!mask[i]){
      leds[i] = CRGB::Black;
    }
  }
}

void wipe_around(bool val){
  float dtheta = 31.4 / 180;
  float theta = -3.14 - dtheta;
  int row, col;
  bool tmp[NUM_LEDS];

  int cx = random(0, MatrixWidth-1);
  int cy = random(0, MatrixHeight-1);
  cx = 8;
  cy = 4;
  
  fillMask(wipe, !val);
  while (theta < 3.14 + dtheta){
    for(row=0; row < MatrixHeight; row++){
      for(col=0; col < MatrixWidth; col++){
	if(atan2(row - cy, col - cx) < theta){
	  setPixelMask(wipe, row, col, val);
	}
      }
    }
    logical_or(NUM_LEDS, wipe, mask, tmp);    
    rainbow(leds, 0, XY);
    apply_mask(tmp);
    FastLED.show();
    theta += dtheta;
  }
}

void fillMask(bool* mask, bool b){
  fillMask(mask, b, 0, NUM_LEDS);
}

void fillMask(bool* mask, bool b, int start, int stop){
  for(int i = start; i < stop && i < NUM_LEDS; i++){
    mask[i] = b;
  }
}

void setPixelMask(bool* mask, uint8_t row, uint8_t col, bool b){
  if(row >= MatrixHeight){
  }
  else if(col >= MatrixWidth){
  }
  else{
    uint16_t pos = XY(col, row);
    if(pos < NUM_LEDS){
      mask[pos] = b;
    }
  }
}

void loadSettings(){
  EEPROM_readAnything(0, configuration);  
}

void saveSettings(){
  EEPROM_writeAnything(0, configuration);
  EEPROM.commit();
}

uint16_t XY( uint8_t x, uint8_t y){
  uint16_t out = 0;
  if(FLIP_DISPLAY){
    x = MatrixWidth - x - 1;
    y = MatrixHeight - y - 1;
  }
  if(x < MatrixWidth && y < MatrixHeight){
    out = MatrixMap[y][x];
  }
  return out;
}

void led_setup(){
  FastLED.addLeds<LED_TYPE, DATA_PIN, CLK_PIN, COLOR_ORDER>(leds, NUM_LEDS);
  FastLED.setDither(true);
  FastLED.setCorrection(TypicalLEDStrip);
  FastLED.setMaxPowerInVoltsAndMilliamps(5, MILLI_AMPS);
  fill_solid(leds, NUM_LEDS, CRGB::Black);
  FastLED.show();

  FastLED.setBrightness(10);
  //FastLED.setBrightness(configuration.brightness);
  wipe_around(ON);
  display_bitmap_rgb(logo_rgb);
  wipe_around(OFF);
  display_bitmap_rgb(logo_rgb);
  FastLED.show();
}

NTPClock ntp_clock;
DS3231Clock ds3231_clock();

WiFiManager wifiManager;
WiFiUDP ntpUDP;

NTPClient timeClient(ntpUDP, "us.pool.ntp.org", 0, 60000);

void setup(){
  Serial.begin(115200);
  delay(200);
  Serial.println("setup() starting");
  loadSettings();
  led_setup();

  for(int ii = 0; ii < num_faceplates; ii++){
    faceplates[ii].setup(MatrixWidth, MatrixHeight, XY);
  }

#ifdef USE_CREDENTIALS
  WiFi.begin(ssid, password);

  while ( WiFi.status() != WL_CONNECTED ) {
    delay ( 500 );
    Serial.print ( "." );
  }
#else
  wifiManager.autoConnect("KLOK");
  Serial.println("yay connected");
#endif
  ntp_clock.setup(&timeClient);
  //timeClient.begin();
  //timeClient.setTimeOffset(-240 * 60);
  
  Serial.println("setup() complete");
}

uint32_t count;
uint32_t now(){
  timeClient.update();
  return timeClient.getEpochTime();
}

void loop(){
  uint8_t word[3];
  //uint32_t current_time = now();
  uint32_t current_time = ntp_clock.now();

  fillMask(mask, OFF);
  faceplates[0].maskTime(current_time, mask);
  rainbow(leds, current_time, XY);
  apply_mask(mask);
  FastLED.show();
  Serial.print(timeClient.getHours());
  Serial.print(":");
  Serial.print(timeClient.getMinutes());
  Serial.print(":");
  Serial.print(timeClient.getSeconds());
  Serial.println("");
  delay(1000);
}

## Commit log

2017-12-24 first push
    [Barrel_Socket_STL_PJ-047A.stl, Barrel_Socket_STL_PJ-047B.stl, ClockFOUR.sch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]
2017-12-25 working on ESP function list, see spreadsheet
    [Barrel_Socket_STL_PJ-047A.stl, Barrel_Socket_STL_PJ-047B.stl, ClockFOUR.sch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]
2017-12-27 schematic WIP
    [Row_A.sch, Row_B.sch, Row_C.sch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]
2017-12-27 schematic dev in progress
    [Barrel_Socket_STL_PJ-047A.stl, Barrel_Socket_STL_PJ-047B.stl, Cap_0805_2012.step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]
2017-12-28 making progress on schematic
    [Row_A.sch, Row_B.sch, Row_C.sch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]
2017-12-29 WIP schematic
    [Row_A.sch, Row_B.sch, Row_C.sch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]
2017-12-29 making progress on PCB
    [Row_A.sch, Row_B.sch, Row_C.sch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]
2017-12-30 WIP PCB layout
    [D_SOD_123.step, MicroUSB-B_Molex_105017-0001.step, QFN-28.step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]
2017-12-30 almost done with PCB
    [c4.fcstd, chromogram.kicad_pcb, chromogram.sch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]
2017-12-31 PCB cleanup
    [ESP32_pin_assignments.ods, chromogram.kicad_pcb, chromogram.sch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]
2018-01-02 minor edits
    [chromogram.kicad_pcb]
2018-01-02 library edits
    [chromogram.kicad_pcb, esp_pwr_uart.sch, mechanical.sch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]
2018-01-03 modified diode footprints
    [D_1006-LLP1006-2L.step, D_LLP1006-2L.step, D_SOD_123.step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]
2018-01-03 legend cleanup
    [chromogram_BoM.ods]
2018-01-04 minor cleanup
    [c4_v2_BoM_seeed.ods, c4_v2_BoM_seeed.xlsx]
2018-01-05 edited mousebites
    [chromogram-B.Cu.gbl, chromogram-B.Mask.gbs, chromogram-B.SilkS.gbo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]
2018-01-06 modified mounting holes
    [chromogram-B.Cu.gbl, chromogram-B.Mask.gbs, chromogram-B.Paste.gbp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]
2018-01-06 added Gerbers
    [Row_A.sch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]
2018-01-07 renamed all files, fresh Gerbers
    [ESP32_pin_assignments.ods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]
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2018-01-08 fresh gerbers and pdf after minor cleanup
    [KlokTHREEjr-B.Cu.gbl, KlokTHREEjr-B.Mask.gbs, KlokTHREEjr-B.Paste.gbp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]
2018-01-08 corrected error in pin assignments
    [ESP32_pin_assignments.ods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]
2018-01-08 added keepout area under ESP antenna when boards are stacked
    [KlokTHREEjr-B.Cu.gbl, KlokTHREEjr-B.Mask.gbs, KlokTHREEjr-B.Paste.gbp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]
2018-01-09 added voltage translation ckt for I2C 3V3 to 5V
    [KlokTHREEjr-B.Cu.gbl, KlokTHREEjr-B.Mask.gbs, KlokTHREEjr-B.Paste.gbp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]
2018-01-10 removed voltage translation ckt for I2C, added I2C header
    [KlokTHREEjr.sch, rtc_ds3231.sch]
2018-01-11 started 8x8 prototype baffles
    [ultim8x8baffles.scad]
2018-01-11 added I2C and SPI headers
    [KlokTHREEjr-B.Cu.gbl, KlokTHREEjr-B.Mask.gbs, KlokTHREEjr-B.Paste.gbp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]
2018-01-11 tracks cleanup
    [KlokTHREEjr-B.Cu.gbl, KlokTHREEjr-B.Mask.gbs, KlokTHREEjr-B.Paste.gbp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]
2018-01-13 more tracks cleanup
    [KlokTHREEjr-B.Cu.gbl, KlokTHREEjr-B.Mask.gbs, KlokTHREEjr-B.Paste.gbp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]
2018-01-13 starting Arduino code for K3jr
    [ultim8x8baffles.scad]
2018-01-15 updated baffles for desklok
    [ultim8x8baffles.scad]
2018-01-16 missing from repo:
    Adafruit_IO_Arduino (added)
    Adafruit_MQTT_Library (added)
    ArduinoHTTPClient (added)
    EEPROMAnything (added)
    I installed local copies here.
    also missing
    Faceplate.h (Removed #include from ino code... was a failed test)
    and probably intentionally
    config.h
    credentials.h
    (not sure we need both) (We need both... added note:
    config.h -- IO feeds (not private)
    credentials.h -- usernames, passwords (private)
    ).
    [KlokTHREEjr_v1.ino]
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2018-01-21 update desKlok (inspired by Dulles)
    [ultim8x8baffles.scad]
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2018-01-21 added Dulles DesKloK assembly photos
    [desKlok_spacer.scad, ultim8x8baffles.scad]
2018-01-22 1. git added MatrixMaps.h to libraries (including ULTIM*x16) 2. added credentials/README file with credentials.h template I also added the lines: #ifndef __CREDENTIALS_H #define __CREDENTIALS_H ... #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
    to the README template. This will prevent multiple declarations error.
    3. Cleaned up calls to Adafruit MQTT library that are no longer used.
    [ultim8x8baffles.scad]
2018-01-23 moved FLIP_DISPLAY to config.h
    [KlokTHREEjr_v1.ino]
2018-01-23 added _anool enclosure in fabricate
    [DesKLOK_case_01.fcstd, Header_Female_PBS2-12.step, Header_Female_PBS2-16.step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]
2018-01-23 fix brightness bug, never changes
    [KlokTHREEjr_v1.ino]
2018-01-23 Desk Klok housing, annol's version
    [desk_klok_back_cover.stl, desk_klok_baffle.stl, desk_klok_case.stl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]
2018-01-24 modified _anool enclosure in fabricate
    [desk_klok_back_cover.stl, desk_klok_baffle.stl, desk_klok_case.stl]
2018-01-26 Desk Klok housing, anool's version, flex box
    [Header_Female_PBS2-12.step, Header_Female_PBS2-16.step, desk_klok_back_cover.stl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]
2018-01-28 DesKLOK 3d print version modified
    [baffles.stl, desk_klok_case.stl]
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2018-01-29 Anool, added missing language files to arduino/KlokTHREEjr_v2
2018-01-30 Anool, DesKLOK laser version files modified
    [baffles.stl]
2018-02-02 fix sense of adaIO inclusion
    [KlokTHREEjr_v2.ino]
2018-02-03 Anool, added dulles clock renders
    [desKlok_spacer.scad, dulles_back_plate.dxf, dulles_front_plate.dxf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]
2018-02-04 renamed some files to match arduino conventions
    [desKlok_spacer.scad]
2018-02-07 Anool, added k3jr_controller_kicad folder/files
    [D_1006-LLP1006-2L.step, D_LLP1006-2L.step, D_SOD_123.step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]
2018-02-08 Anool, updated controller board BoM
    [Row_A.sch, Row_B.sch, Row_C.sch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]
2018-02-08 Anool, updated KlokTHREEjr main board BoM
    [KlokTHREEjr_BoM.ods]
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2018-03-05 corrected I2C silk legend
    [desk_klok_FlexBox_side.dxf, esp_pwr_uart.sch, k3jr_controller.kicad_pcb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]
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2018-03-09 kontroller layout modified. Old layout archived as rev _v1
    [k3jr_controller.kicad_pcb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]
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2018-03-10 correction to Kontroller and KlockTHREEjr
    [k3jr_controller-B.Cu.gbl, k3jr_controller-B.Mask.gbs, k3jr_controller-B.Paste.gbp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]
2018-03-10 KlokTHREEjr final. Kontroller pending
    [KlokTHREEjr-B.Cu.gbl, KlokTHREEjr-B.Mask.gbs, KlokTHREEjr-B.Paste.gbp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]
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2018-03-11 seeed format BoM ready
    [KlokTHREEjr_BoM.ods, KlokTHREEjr_BoM_seeed.ods, KlokTHREEjr_BoM_seeed.xls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]
2018-03-11 BoM minor correction
    [KlokTHREEjr_BoM_seeed.ods, KlokTHREEjr_BoM_seeed.xls]
2018-03-17 USB protection, LDR, Switches reconfigured
    [KlokTHREEjr-B.Cu.gbl, KlokTHREEjr-B.Mask.gbs, KlokTHREEjr-B.Paste.gbp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]
2018-03-18 ready for seeed submission
    [KlokTHREEjr-B.Cu.gbl, KlokTHREEjr-B.Mask.gbs, KlokTHREEjr-B.Paste.gbp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]
2018-03-18 re-write xls bom for compatibility
    [KlokTHREEjr_BoM_seeed.xls]
2018-03-18 move ldr to dnp
    [KlokTHREEjr_BoM_seeed.xls]
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2018-03-19 moved APA102 to DNP row on BoM
    [KlokTHREEjr.sch, KlokTHREEjr_BoM_seeed.ods, KlokTHREEjr_BoM_seeed.xls]
2018-03-21 coin battery footprint update - remove solder paste opening
    [KlokTHREEjr-B.Cu.gbl, KlokTHREEjr-B.Mask.gbs, KlokTHREEjr-B.Paste.gbp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]
2018-03-21 added Kontroller_v2 based on most recent KlokTHREEjr
    [D_1006-LLP1006-2L.step, D_LLP1006-2L.step, D_SOD_123.step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]
